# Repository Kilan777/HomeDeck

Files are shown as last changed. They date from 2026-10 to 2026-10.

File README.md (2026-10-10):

# Jarvis HomeDeck

> **Public mirror.** This is a snapshot of the private working repo (commit `6268e34`). Some private parts of the software are not included.

A self-built voice assistant with a screen: a Raspberry Pi Compute Module 4 carrier PCB that bolts to the 7-inch
Raspberry Pi Touch Display 2, plus the software that turns it into "Jarvis". Personal project by Kilan.

The board carries the CM4, USB-C PD power, three 5 V bucks, a stereo class-D amplifier, two MEMS microphones,
a Camera Module 3 connector, CO2 / temperature / humidity / pressure / VOC sensors, an RGB LED bar and an external
WS2812B strip header, a fan header, buttons, a Qwiic-style I2C header, microSD, USB-A and a second USB-C.

The software is a single Python service with a module per feature and a touch UI in Chromium, plus a phone app
served on a personal domain behind Google sign-in. Voice runs on a local wake word and hosted speech models;
everything that is a command (timers, lights, music, volume, math) is handled on the device without a model.

| Folder | Contents |
|---|---|
| `kicad/` | KiCad project: hierarchical schematic (9 sheets), 4-layer routed PCB, project symbols and footprints, DRC rules |
| `tools/circuit.py` | The single source the schematic, netlist and BOM are generated from. Edit this, not the KiCad files |
| `out/` | Gerbers, JLCPCB BOM and pick-and-place, schematic PDF, board renders, DRC report (rev A as ordered) |
| `docs/` | Hardware docs: `README.md` (board overview), `ARCHITECTURE.md`, `BRINGUP.md`, `ORIENTATION.md`, and `PCB_ISSUES.md` (what went wrong on rev A and what rev B should change) |
| `software/homedeck/` | The assistant: `server.py`, `modules/`, `web/`, `install/`. See `docs/SOFTWARE.md` |
| `software/homedeck_ui.py` | The original bench dashboard used for bring-up (retired) |

## Status

- Rev A board #1 is fully working and in daily use, running at 9 V PD after two solder-jumper changes.
  Rev A board #2 is assembled and untested. Findings and the rev B list are in `docs/PCB_ISSUES.md`.
- Software is feature complete for daily use: home screen, Jarvis voice, Spotify (full client), YouTube (ad-free
  native player), air quality with history, timers, alarms, reminders, lists, calendar, countdowns, bikes, transit,
  flights radar, lights, fan, sleep sounds, guest card with Wi-Fi QR,
  presence, Wi-Fi setup, on-screen keyboard. See `docs/SOFTWARE.md`.

## Quick start

Hardware: order from `out/` (JLCPCB 4-layer, two-sided assembly), read `docs/BRINGUP.md`, then apply the rev A
fixes in `docs/PCB_ISSUES.md` before first power-on (the 9 V jumper setting matters).

Software, on the Pi:

```
rsync -a software/homedeck/ kilan@homedeck.local:~/hd/
ssh kilan@homedeck.local 'cd ~/hd && bash install.sh'
```

Then open Settings on the device for location, Wi-Fi, Spotify, calendar feeds and the API keys the optional
features need (Groq for voice, 511.org for Muni). Secrets live only on the device in `/var/lib/homedeck/config.json`
and are never in this repository.

## Privacy

This repository is private. It contains no credentials, tokens or Wi-Fi passwords. The device redacts secrets
from every API response, the phone app requires Google sign-in, and there is no VPN or third-party relay involved.

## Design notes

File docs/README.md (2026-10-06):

# HomeDeck CM4 – smart display / voice assistant carrier board

A Raspberry Pi Compute Module 4 carrier that bolts onto the back of the Raspberry Pi Touch Display 2 (7") and turns it into a self-built "Echo Show" style device: touchscreen, camera, two MEMS microphones, stereo class-D speaker amplifier, CO2 / temperature / humidity / pressure / VOC sensors, ambient light sensor header, RGB light bar, three programmable buttons, microSD, USB-C PD power, a second USB-C (data + 5 V) and a USB-A port.

Everything in this package was generated from a single circuit description (`tools/circuit.py`), so the schematic, the PCB netlist and the BOM cannot disagree with each other.

## What is in the box

| File | What it is |
|---|---|
| `kicad/HomeDeck.kicad_pro` + `*.kicad_sch` | KiCad 7 project, hierarchical schematic (9 sheets). Opens in KiCad 7, 8 or 9. |
| `kicad/HomeDeck.kicad_pcb` | 4-layer board, placed and routed, ground/power planes filled. |
| `kicad/HomeDeck.kicad_sym`, `kicad/HomeDeck.pretty/` | Project symbols and footprints (CM4, CH224K, TPA3118D2, TS3USB221, SY6280, BME688, FPC, USB-A, microSD). |
| `kicad/HomeDeck.kicad_dru` | Custom DRC rules (0.1 mm rules inside the CM4 fan-out areas). |
| `out/HomeDeck_gerbers.zip` | Gerbers + Excellon drill files for JLCPCB. |
| `out/HomeDeck_BOM_JLCPCB.csv` | BOM in JLCPCB format with LCSC part numbers, library type and stock as checked on 2026-09-06. |
| `out/HomeDeck_CPL_JLCPCB.csv` | Pick-and-place file in JLCPCB format (pad-centre positions, JLC rotation corrections applied). |
| `out/HomeDeck_BOM_other.csv` | Parts you buy elsewhere (the CM4 itself) and DNP parts. |
| `out/HomeDeck_schematic.pdf` | Printable schematic. |
| `out/board_top.png`, `out/board_bottom.png` | Renders. |
| `out/drc.txt` | KiCad DRC report of the delivered board. |
| `docs/ARCHITECTURE.md` | Design rationale, power budget, pin map. |
| `docs/BRINGUP.md` | Ordering, assembly, first power-on and software setup. |

## Key numbers

* Board: 130 x 105 mm, 1.6 mm, 4 layers (signal / GND / power planes / signal), ENIG recommended because of the 0.4 mm-pitch CM4 connector pads.
* Mounting: four M2.5 holes on the 58 x 49 mm Raspberry Pi pattern (Touch Display 2 standoffs), centred on the board.
* Power in: USB-C PD, 15 V requested (solder jumpers for 9/12/20 V). Needs a 45 W or better PD charger.
* Rails: 3x TPS5430 bucks (5V_SYS for the CM4, 5V_PERIPH for display/LEDs/fan, 5V_USB for the ports), AMS1117 3.3 V, amplifier directly from the 15 V rail.
* Design rules: 0.2 mm tracks / 0.15 mm clearance generally, 0.1 mm / 0.1 mm only inside the two CM4 fan-out rule areas, vias 0.6/0.3 mm (0.45/0.2 mm in the fan-out). All within JLCPCB's 4-layer capabilities.

## Status of the delivered board

* Placed, fully routed (160 nets), planes filled. KiCad DRC: **0 errors, 0 unconnected items, 0 dangling tracks or vias**; 272 warnings, all cosmetic (silkscreen clipped by the edge on overhanging connectors, designators over copper, and "footprint not in library" because the report was generated headless). Details in `docs/BRINGUP.md` section 5.
* Schematic-to-board netlist verified identical (both come from `tools/circuit.py`); a separate GND connectivity check finds no floating ground copper.
* Design-reviewed twice by independent passes over the datasheets; all findings are fixed in this revision (CH224K VDD feed, TVS orientation, buffered PWR LED, pull-ups referenced to the CM4 3.3 V, USB-C port current limit, I2C0 pull-ups, hub crystal caps removed, LDO output electrolytic, SD_PWR_ON pull-up rail). Manufacturing checks: minimum hole-to-hole gap 0.35 mm, vias 0.6/0.3 and 0.45/0.2, no top-side parts under the CM4, no bottom-side parts near the display standoffs.
* 218 assembled parts (plus the two CM4 sockets as M1A/M1B), 66 BOM lines (38 Basic, 28 Extended), all checked for JLC stock and library type on 2026-09-06 (three out-of-stock parts were swapped: fuse, FPC connectors, CM4 sockets). 116 parts on the bottom side, so order two-sided Standard assembly.
* Routing is 0/45/90-degree geometry with chamfered corners; differential pairs length-matched to within 1.3 mm (most under 0.3 mm), except USB-C #2 data (7.7 mm, still within what USB 2.0 tolerates; see ARCHITECTURE.md section 5).
* Buy separately: CM4 module, Touch Display 2, camera, speakers, PD charger, optional fan and BH1750 breakout (see `out/HomeDeck_BOM_other.csv`).

## How the schematic is drawn

The schematic is "label style": every pin carries a global label with its net name and the sub-sheets group the circuit by function (power, cm4, usb, video, sd, audio, sensors, ui, mech). Every net name is unique across the project, so you can click any label in KiCad and see every place the net goes. It is not a pretty hand-drawn schematic, but it is complete and it is exactly what the PCB was built from.

## Regenerating

```
python3 tools/gen_lib.py        # symbols + footprints
python3 tools/gen_sch.py        # schematic
python3 tools/route.py          # placement + routing + zone fill + DRC (takes 20-40 min)
python3 tools/export.py         # gerbers, BOM, CPL, PDF
```
`tools/router.cpp` is the negotiated-congestion grid router (build with `g++ -O2 -std=c++17 -o tools/router tools/router.cpp`, needs nlohmann-json).

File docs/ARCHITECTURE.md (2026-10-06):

# HomeDeck CM4 – Architecture & Design Notes

Smart-display / voice-assistant carrier board for the Raspberry Pi Compute Module 4, built to bolt onto the back of the Raspberry Pi Touch Display 2 (7", 720x1280). Fabricated and assembled by JLCPCB (4-layer, SMT assembly, Basic parts wherever a Basic part exists).

## 1. What the board does

| Block | Choice | Why |
|---|---|---|
| Compute | Raspberry Pi CM4 (any RAM / eMMC / wireless variant) on 2x Hirose DF40C-100DS | Linux, native DSI + CSI, Wi-Fi/BT on module, huge software base (Home Assistant, Wyoming/openWakeWord, Rhasspy). |
| Display | Touch Display 2 via 15-pin 1.0 mm bottom-contact DSI connector (BOOMELE, JLC C66660) (CM4 DSI1, 2 lanes) + 3-pin 5 V header for the display's power lead | Same wiring as a Pi 4, so the stock `vc4-kms-dsi-ili9881-7inch` overlay works. Touch runs over the I2C0 lines inside the DSI cable. |
| Camera | Pi Camera Module (v2/v3/HQ) via 15-pin 1.0 mm bottom-contact CSI connector (same part; CM4 CAM1, 2 lanes) | Stock libcamera support. Camera enable driven by the CM4 `Camera_GPIO` pin, exactly like the CM4IO board. |
| Power in | USB-C #1 with CH224K PD sink (VDD fed from VBUS through 1 k, SMBJ24A TVS, 5 A fuse), configured for 15 V (solder jumpers allow 9/12/20 V) | One cable from any 45 W+ USB-C PD charger. 15 V gives the amplifier headroom and keeps the bucks efficient. |
| Rails | 3x TPS5430 (3 A, Basic part) bucks: `5V_SYS` (CM4 + 3.3 V LDO), `5V_PERIPH` (display + LED bar + fan), `5V_USB` (USB-C #2 + USB-A + internal USB headers). AMS1117-3.3 LDO for `3V3` (22 uF ceramic + 100 uF electrolytic on its output, the LDO needs some ESR). | Three Basic-part bucks are cheaper at JLC than one big Extended buck, and they isolate the CM4 from USB-port load steps. Output caps are 100 uF electrolytic + 22 uF ceramic because the TPS5430 wants some ESR. |
| USB | CM4 USB 2.0 -> TS3USB221 mux -> CH334R 4-port hub. Ports: USB-C #2 (5 V/1.7 A + data, CC pull-ups advertise 1.5 A), USB-A (5 V/1.3 A + data), 2x internal 4-pin headers (for a Zigbee/Thread dongle etc). | CM4 has a single USB 2.0 port so a hub is mandatory. Each external port has a SY6280 current-limit switch and USBLC6 ESD protection. |
| eMMC flashing | `nRPIBOOT` jumper flips both TS3USB221 muxes so the CM4 USB goes straight to USB-C #2 and cuts that port's 5 V output. U6's two switch ports are wired the opposite way round to U7 (so the BOOT pair leaves U6 on the pins facing U7 without crossing the hub pair), and its select pin is therefore driven by an inverted copy of `nRPIBOOT` (Q5 2N7002 + R47 10 k). | Lets you run `rpiboot` from a PC with a USB-A-to-C cable without a separate service port. |
| Storage | microSD (Molex 104031-0811) on the CM4 SD lines with SD_PWR_ON load switch | Boot medium for CM4 *Lite*. On eMMC CM4 variants the SD pins are inactive (Pi limitation). |
| Audio out | PCM5102A I2S DAC -> TPA3118D2 stereo class-D (2x >5 W into 8 ohm from the 15 V rail), LC output filters (10 uH + 1 uF), 2x JST-PH speaker connectors | `dtoverlay=hifiberry-dac` style zero-config DAC. Amp enable/mute/fault on GPIO. |
| Audio in | 2x ICS-43434 I2S MEMS mics (L/R on one I2S data line) at the top corners, bottom-ported through the PCB | Same clocks as the DAC (full-duplex I2S), same arrangement as the Google AIY Voice HAT overlay. |
| Sensors (I2C6, GPIO22/23) | SCD40 (CO2) and BME688 (temp/humidity/pressure/VOC) on a thermally slotted tongue at the left edge; BH1750 ambient light sensor on a 4-pin header (J12) so it can sit behind the bezel and actually see the room. | Keeps the temperature sensor away from the CM4 heat and the light sensor where there is light. |
| Light bar | 10x WS2812B (5050) along the top edge + JST-PH-3 header for an external strip, 74AHCT1G125 level shifter, data on GPIO10 (SPI MOSI, works with `rpi_ws281x` SPI mode) | Classic "listening" glow. |
| Buttons / LEDs | Power button (GPIO3: wake from halt + `gpio-shutdown`), two user buttons (GPIO16, GPIO26), user LED (GPIO12, PWM-capable), PWR / ACT LEDs from the CM4 LED pins, PD-good LED. Each button has an on-board tactile switch *and* a 2-pin header for a panel-mounted button. | All programmable; nothing is hard-wired to the mics or camera. |
| Misc | 5 V fan header (GPIO25 PWM via transistor), UART debug header (GPIO14/15), 2x8 expansion header with the spare GPIOs, `GLOBAL_EN` and `RUN` headers, reset button | Bring-up and future expansion. |

## 2. Power budget (15 V PD input)

| Load | Rail | Typ | Peak |
|---|---|---|---|
| CM4 | 5V_SYS | 1.4 A | 3.0 A |
| 3V3 LDO loads (hub, DAC, mux, sensors, mics) | 5V_SYS | 0.25 A | 0.45 A |
| Touch Display 2 | 5V_PERIPH | 0.6 A | 1.0 A |
| LED bar (10x WS2812B) | 5V_PERIPH | 0.1 A | 0.6 A |
| Fan | 5V_PERIPH | 0.1 A | 0.2 A |
| USB-C #2 + USB-A + internal headers | 5V_USB | 0.5 A | 3.0 A (1.74 A + 1.33 A limits of the SY6280s) |
| Amplifier (2x5 W into 8 ohm, music) | VBUS 15 V | 0.3 A | 1.0 A |

Worst case at 15 V: (3.45 + 1.8 + 2.9) x 5 V / 0.88 + 15 W = ~61 W momentarily; realistic sustained draw is 20–30 W. A 45 W (15 V / 3 A) PD supply is the minimum; 65 W is comfortable. If the charger only offers 9 V or 12 V the CH224K falls back to it and everything still works (the amp just has less headroom). At 5 V only (dumb charger) the bucks cannot regulate and the board is not guaranteed to boot — the PD-good LED tells you.

Buck design (TPS5430, 500 kHz, non-synchronous): 10 uH / 7.8 A shielded inductor, SS34 catch diode, 2x 10 uF/50 V ceramic input, 100 uF electrolytic + 22 uF ceramic output, 10 nF bootstrap, feedback 15 k / 4.7 k -> 5.12 V (CM4 window is 4.75–5.25 V, USB ports need >4.75 V after the switch drop).

## 3. CM4 pin usage

* USB: `USB_P/N` (105/103) -> mux. `USB_OTG_ID` DNP link to GND (host mode is set by `otg_mode=1` in `config.txt`).
* DSI1 lanes 0-1 + clock -> display connector; CAM1 lanes 0-1 + clock -> camera connector; `SCL0/SDA0` (80/82) to both connectors (the CM4 has 1.8 k internal pull-ups, none added); `Camera_GPIO` (97) -> camera pin 11.
* SD: `SD_CLK/CMD/DAT0-3` (57/62/63/67/69/61) -> microSD; `SD_PWR_ON` (75) -> P-FET load switch, 10 k pull-up to `CM4_3.3V` so the card is powered at boot; `SD_VDD_OVERRIDE` NC.
* Power/control: 6x `+5V` pins from 5V_SYS, `GPIO_VREF` (78) -> `CM4_3.3V`, `GLOBAL_EN` (99) header, `RUN_PG` (92) reset switch via 220 R, `nRPIBOOT` (93) jumper, `PI_LED_nPWR` (95, buffered with a P-FET as the datasheet requires) / `Pi_nLED_Activity` (21) LEDs, `EEPROM_nWP`, `WL_nDisable`, `BT_nDisable`, `AnalogIP*`, `VDAC_COMP`, HDMI, PCIe, Ethernet all NC.
* GPIO map:

| GPIO | Function | GPIO | Function |
|---|---|---|---|
| 2 | expansion (SDA1) | 16 | BTN_A |
| 3 | PWR_BTN (SCL1, wake) | 17 | expansion |
| 4 | AMP_SDZ (amp enable, pulled low) | 18 | I2S_BCLK |
| 5 | AMP_MUTE (high = mute, pulled low) | 19 | I2S_LRCLK |
| 6 | AMP_FAULT (input, pulled up) | 20 | I2S_DIN (mics) |
| 7 | expansion (CE1) | 21 | I2S_DOUT (DAC) |
| 8 | expansion (CE0) | 22 | I2C6_SDA sensors |
| 9 | expansion (MISO) | 23 | I2C6_SCL sensors |
| 10 | LED_DATA (MOSI) | 24 | DAC_XSMT (pulled up) |
| 11 | expansion (SCLK) | 25 | FAN_PWM |
| 12 | USER_LED | 26 | BTN_B |
| 13 | expansion (PWM1) | 27 | PD_GOOD (input, pulled up) |
| 14/15 | UART TX/RX debug | 0/1 | ID_SD/ID_SC on expansion |

All pull-ups on CM4 GPIOs go to `CM4_3.3V` (not the always-on 3V3) so no pin sees voltage while the module is off, as the CM4 datasheet requires.

Software notes: `dtoverlay=i2c6,pins_22_23`, `dtoverlay=gpio-shutdown,gpio_pin=3`, `dtoverlay=hifiberry-dac` (or a custom simple-audio-card overlay that adds the ICS-43434 capture side), `dtoverlay=vc4-kms-dsi-ili9881-7inch`, `otg_mode=1`, `dtparam=i2c_vc=on`.

## 4. Mechanical

* Board 130 x 105 mm, 1.6 mm, 4 layers (Sig – GND – PWR – Sig), ENIG recommended for the 0.4 mm DF40 pads. JLCPCB 4-layer rules: 0.2/0.15 mm tracks/clearance generally, 0.1/0.1 mm and 0.45/0.2 mm vias inside the two CM4 fan-out rule areas.
* Four M2.5 holes on the 58 x 49 mm Raspberry Pi pattern (centred on the board), matching the Touch Display 2 standoffs. The display sits against the *bottom* side, so bottom-side parts are limited to 0603-1206 passives, one SOT-23 and the two mics (~1 mm tall); 114 parts live there, so order two-sided assembly.
* CM4 on top, centred over the standoff pattern; use the official CM4 heatsink (the design leaves the CM4 mounting holes free).
* All external connectors on the bottom edge (y = 105): microSD, USB-A, USB-C data, fan, speakers, display power, USB-C power. Display and camera FPC connectors sit above the CM4 with the cables exiting toward the top edge.
* Sensor tongue on the left edge with two 1.6 mm routed slots for thermal isolation; enclosure needs vent slots there and a light pipe for the BH1750.
* Mics at the top corners: 1.0 mm acoustic holes through the PCB (they are bottom-ported and mounted on the bottom side so they listen "up" through the board); enclosure needs matching holes with a gasket.
* LED bar along the top edge shining upward — enclosure needs a diffuser slot, or use the 3-pin header for a strip elsewhere.

## 5. Fan-out and routing notes

Every used CM4 pad gets a 0.1 mm stub to a 0.45/0.2 mm via, in three staggered rows (1.2 / 1.9 / 2.6 mm from the pad row). Inner rows fan out under the module, outer rows fan out away from it; the region below the lower connector (x 52-78, y 73-86) is kept free of components for this, and the lower fan-out rule area extends to y = 79.5 so the SD-card bus can leave the connector at 0.1 mm spacing. The routing was done by a negotiated-congestion grid router written for this project, then post-processed into conventional 0/45/90-degree geometry (staircases replaced by straight and 45-degree runs wherever clear, right-angle corners chamfered), and every differential pair was length-matched with small meander bumps on the shorter leg; the top/bottom GND pours use 0.25 mm minimum width and 0.25 mm clearance so they do not fragment into slivers, every pour island that ended up without a path to the internal GND plane got a stitching via, and a coarse grid of stitching vias ties the pours to the plane in the open areas (a connectivity check on the final board finds zero floating GND copper). In2 carries split power planes: 5V_SYS under the CM4, VBUS (15 V) along the right and bottom-right, 5V_USB bottom-left, 5V_PERIPH along the top, 3V3 under the sensor tongue.

### Differential-pair status (final board)

| Pair | Length P / N (mm) | Skew |
|---|---|---|
| DSI D0 / D1 / CLK | 19.0/18.8, 21.3/21.5, 20.4/20.6 | 0.1 / 0.2 / 0.2 mm |
| CSI D0 / D1 / CLK | 14.3/14.1, 17.1/16.6, 21.0/19.8 | 0.2 / 0.5 / 1.2 mm |
| CM4 USB -> U6 | 43.8/43.9 | 0.1 mm |
| U6 -> U7 (BOOT) | 6.8/7.2 | 0.3 mm |
| U6 -> hub upstream | 4.7/6.0 | 1.3 mm |
| hub -> U7 (DS1) | 3.4/4.2 | 0.8 mm |
| hub -> USB-A (signal path through the ESD diode) | 11.4/12.6 | 1.1 mm |
| hub -> internal headers DS3 / DS4 | 46.7/46.5, 34.2/34.0 | 0.2 / 0.2 mm |
| U7 -> USB-C #2 (signal path) | 22.9/15.2 | **7.7 mm** |

Everything except USB-C #2 is within 1.3 mm (under 10 ps), which is well inside what MIPI D-PHY and USB 2.0 receivers tolerate. The USB-C #2 data pair is the one that could not be matched automatically: the receptacle's A6/B6 and A7/B7 pads interleave, so one leg has to loop behind the connector, and the 0.5 mm-pitch mux pins leave no room for meanders. 7.7 mm is about 50 ps, 2.5 % of a USB high-speed bit, so it will work, but if you want it textbook-clean, re-route that pair with KiCad's interactive differential-pair router (Route -> Differential Pair, then Tune Skew) between U7 and J2. Nothing else on the board is impedance- or length-critical.

## 6. Options not populated (but discussed)

mmWave presence radar (LD2410 on the UART header), hardware mic/camera kill switch (can be added in series with the mic 3V3 and `Camera_GPIO`), Zigbee/Thread (a USB dongle on the internal USB header is the pragmatic route), IR blaster/receiver, PoE, RTC with coin cell, PIR.

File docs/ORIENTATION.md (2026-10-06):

# Component orientation list (for the JLCPCB placement preview)

Directions are as seen looking at that side of the board with the top edge of the board up (for bottom-side parts you are looking at the board from below). 'Only 90 deg' means 0 and 180 are both fine but a 90-degree error is a fault.

| Ref | Value | Footprint | Side | Orientation matters? | How it must sit |
|---|---|---|---|---|---|
| C1 | 10uF/50V | C_1206_3216Metric | bottom | No | Symmetric two-terminal part. |
| C2 | 10uF/50V | C_1206_3216Metric | bottom | No | Symmetric two-terminal part. |
| C3 | 100uF/35V | CP_Elec_6.3x7.7 | top | Yes | Positive (+) lead on the left (the can's black stripe is the negative side, opposite). |
| C4 | 1uF | C_0603_1608Metric | top | No | Symmetric two-terminal part. |
| C5 | 10uF/50V | C_1206_3216Metric | bottom | No | Symmetric two-terminal part. |
| C6 | 100nF | C_0603_1608Metric | top | No | Symmetric two-terminal part. |
| C7 | 10nF | C_0603_1608Metric | bottom | No | Symmetric two-terminal part. |
| C8 | 100uF/35V | CP_Elec_6.3x7.7 | top | Yes | Positive (+) lead on the bottom (the can's black stripe is the negative side, opposite). |
| C9 | 22uF/25V | C_1206_3216Metric | bottom | No | Symmetric two-terminal part. |
| C10 | 100nF | C_0603_1608Metric | bottom | No | Symmetric two-terminal part. |
| C11 | 10uF/50V | C_1206_3216Metric | bottom | No | Symmetric two-terminal part. |
| C12 | 100nF | C_0603_1608Metric | top | No | Symmetric two-terminal part. |
| C13 | 10nF | C_0603_1608Metric | bottom | No | Symmetric two-terminal part. |
| C14 | 100uF/35V | CP_Elec_6.3x7.7 | top | Yes | Positive (+) lead on the bottom (the can's black stripe is the negative side, opposite). |
| C15 | 22uF/25V | C_1206_3216Metric | bottom | No | Symmetric two-terminal part. |
| C16 | 100nF | C_0603_1608Metric | bottom | No | Symmetric two-terminal part. |
| C17 | 10uF/50V | C_1206_3216Metric | bottom | No | Symmetric two-terminal part. |
| C18 | 100nF | C_0603_1608Metric | top | No | Symmetric two-terminal part. |
| C19 | 10nF | C_0603_1608Metric | bottom | No | Symmetric two-terminal part. |
| C20 | 100uF/35V | CP_Elec_6.3x7.7 | top | Yes | Positive (+) lead on the bottom (the can's black stripe is the negative side, opposite). |
| C21 | 22uF/25V | C_1206_3216Metric | bottom | No | Symmetric two-terminal part. |
| C22 | 100nF | C_0603_1608Metric | bottom | No | Symmetric two-terminal part. |
| C23 | 22uF/25V | C_1206_3216Metric | bottom | No | Symmetric two-terminal part. |
| C24 | 22uF/25V | C_1206_3216Metric | bottom | No | Symmetric two-terminal part. |
| C25 | 100nF | C_0603_1608Metric | top | No | Symmetric two-terminal part. |
| C26 | 100nF | C_0603_1608Metric | bottom | No | Symmetric two-terminal part. |
| C27 | 10uF | C_0603_1608Metric | bottom | No | Symmetric two-terminal part. |
| C28 | 10uF | C_0603_1608Metric | bottom | No | Symmetric two-terminal part. |
| C29 | 100nF | C_0603_1608Metric | bottom | No | Symmetric two-terminal part. |
| C30 | 100nF | C_0603_1608Metric | bottom | No | Symmetric two-terminal part. |
| C31 | 100nF | C_0603_1608Metric | bottom | No | Symmetric two-terminal part. |
| C32 | 1uF | C_0603_1608Metric | bottom | No | Symmetric two-terminal part. |
| C33 | 10uF | C_0603_1608Metric | bottom | No | Symmetric two-terminal part. |
| C34 | 100nF | C_0603_1608Metric | bottom | No | Symmetric two-terminal part. |
| C35 | 100nF | C_0603_1608Metric | bottom | No | Symmetric two-terminal part. |
| C36 | 22pF | C_0603_1608Metric | bottom | No | Symmetric two-terminal part. |
| C37 | 22pF | C_0603_1608Metric | bottom | No | Symmetric two-terminal part. |
| C38 | 10uF | C_0603_1608Metric | top | No | Symmetric two-terminal part. |
| C39 | 10uF | C_0603_1608Metric | top | No | Symmetric two-terminal part. |
| C40 | 10uF | C_0603_1608Metric | bottom | No | Symmetric two-terminal part. |
| C41 | 10uF | C_0603_1608Metric | bottom | No | Symmetric two-terminal part. |
| C42 | 10uF | C_0603_1608Metric | bottom | No | Symmetric two-terminal part. |
| C43 | 100nF | C_0603_1608Metric | bottom | No | Symmetric two-terminal part. |
| C44 | 10uF | C_0603_1608Metric | bottom | No | Symmetric two-terminal part. |
| C45 | 100nF | C_0603_1608Metric | bottom | No | Symmetric two-terminal part. |
| C46 | 10uF | C_0603_1608Metric | bottom | No | Symmetric two-terminal part. |
| C47 | 100nF | C_0603_1608Metric | bottom | No | Symmetric two-terminal part. |
| C48 | 100nF | C_0603_1608Metric | bottom | No | Symmetric two-terminal part. |
| C49 | 10uF | C_0603_1608Metric | bottom | No | Symmetric two-terminal part. |
| C50 | 2.2uF | C_0603_1608Metric | bottom | No | Symmetric two-terminal part. |
| C51 | 2.2uF | C_0603_1608Metric | bottom | No | Symmetric two-terminal part. |
| C52 | 2.2uF | C_0603_1608Metric | bottom | No | Symmetric two-terminal part. |
| C53 | 2.2nF | C_0603_1608Metric | bottom | No | Symmetric two-terminal part. |
| C54 | 1uF | C_0603_1608Metric | top | No | Symmetric two-terminal part. |
| C55 | 1uF | C_0603_1608Metric | bottom | No | Symmetric two-terminal part. |
| C56 | 2.2nF | C_0603_1608Metric | bottom | No | Symmetric two-terminal part. |
| C57 | 1uF | C_0603_1608Metric | bottom | No | Symmetric two-terminal part. |
| C58 | 1uF | C_0603_1608Metric | bottom | No | Symmetric two-terminal part. |
| C59 | 1uF | C_0603_1608Metric | bottom | No | Symmetric two-terminal part. |
| C60 | 1uF | C_0603_1608Metric | bottom | No | Symmetric two-terminal part. |
| C61 | 100nF | C_0603_1608Metric | bottom | No | Symmetric two-terminal part. |
| C62 | 220nF | C_0603_1608Metric | top | No | Symmetric two-terminal part. |
| C63 | 220nF | C_0603_1608Metric | top | No | Symmetric two-terminal part. |
| C64 | 220nF | C_0603_1608Metric | top | No | Symmetric two-terminal part. |
| C65 | 220nF | C_0603_1608Metric | top | No | Symmetric two-terminal part. |
| C66 | 1nF | C_0603_1608Metric | bottom | No | Symmetric two-terminal part. |
| C67 | 10uF/50V | C_1206_3216Metric | bottom | No | Symmetric two-terminal part. |
| C68 | 1nF | C_0603_1608Metric | bottom | No | Symmetric two-terminal part. |
| C69 | 10uF/50V | C_1206_3216Metric | bottom | No | Symmetric two-terminal part. |
| C70 | 100uF/35V | CP_Elec_6.3x7.7 | top | Yes | Positive (+) lead on the left (the can's black stripe is the negative side, opposite). |
| C71 | 1uF/50V | C_0805_2012Metric | top | No | Symmetric two-terminal part. |
| C72 | 1uF/50V | C_0805_2012Metric | bottom | No | Symmetric two-terminal part. |
| C73 | 1uF/50V | C_0805_2012Metric | bottom | No | Symmetric two-terminal part. |
| C74 | 1uF/50V | C_0805_2012Metric | top | No | Symmetric two-terminal part. |
| C75 | 100nF | C_0603_1608Metric | top | No | Symmetric two-terminal part. |
| C76 | 100nF | C_0603_1608Metric | top | No | Symmetric two-terminal part. |
| C77 | 10uF | C_0603_1608Metric | bottom | No | Symmetric two-terminal part. |
| C78 | 100nF | C_0603_1608Metric | bottom | No | Symmetric two-terminal part. |
| C79 | 100nF | C_0603_1608Metric | bottom | No | Symmetric two-terminal part. |
| C80 | 100nF | C_0603_1608Metric | bottom | No | Symmetric two-terminal part. |
| C81 | 100nF | C_0603_1608Metric | bottom | No | Symmetric two-terminal part. |
| C82 | 100nF | C_0603_1608Metric | bottom | No | Symmetric two-terminal part. |
| C83 | 100nF | C_0603_1608Metric | bottom | No | Symmetric two-terminal part. |
| C84 | 100nF | C_0603_1608Metric | bottom | No | Symmetric two-terminal part. |
| C85 | 100nF | C_0603_1608Metric | bottom | No | Symmetric two-terminal part. |
| C86 | 100nF | C_0603_1608Metric | bottom | No | Symmetric two-terminal part. |
| C87 | 100nF | C_0603_1608Metric | bottom | No | Symmetric two-terminal part. |
| C88 | 100nF | C_0603_1608Metric | bottom | No | Symmetric two-terminal part. |
| C89 | 100nF | C_0603_1608Metric | bottom | No | Symmetric two-terminal part. |
| C90 | 100nF | C_0603_1608Metric | bottom | No | Symmetric two-terminal part. |
| C91 | 100nF | C_0603_1608Metric | bottom | No | Symmetric two-terminal part. |
| C92 | 10uF | C_0603_1608Metric | bottom | No | Symmetric two-terminal part. |
| C93 | 100nF | C_0603_1608Metric | bottom | No | Symmetric two-terminal part. |
| C94 | 100nF | C_0603_1608Metric | bottom | No | Symmetric two-terminal part. |
| C95 | 100nF | C_0603_1608Metric | bottom | No | Symmetric two-terminal part. |
| D1 | SMBJ24A | D_SMB | top | Yes | Cathode band on the bottom. |
| D2 | PD OK (green) | LED_0805_2012Metric | top | Yes | Cathode (green mark / notch) on the bottom. |
| D3 | ACT (green) | LED_0805_2012Metric | top | Yes | Cathode (green mark / notch) on the bottom. |
| D4 | PWR (red) | LED_0603_1608Metric | top | Yes | Cathode (green mark / notch) on the bottom. |
| D5 | USER (green) | LED_0805_2012Metric | top | Yes | Cathode (green mark / notch) on the bottom. |
| D6 | SS34 | D_SMA | top | Yes | Cathode band on the left. |
| D7 | SS34 | D_SMA | top | Yes | Cathode band on the left. |
| D8 | SS34 | D_SMA | top | Yes | Cathode band on the left. |
| D9 | SS34 | D_SMA | top | Yes | Cathode band on the left. |
| D10 | WS2812B | LED_WS2812B_PLCC4_5.0x5.0mm_P3.2mm | top | Yes | Pin 1 (VDD, the cut corner of the LED) at the top-left. |
| D11 | WS2812B | LED_WS2812B_PLCC4_5.0x5.0mm_P3.2mm | top | Yes | Pin 1 (VDD, the cut corner of the LED) at the top-left. |
| D12 | WS2812B | LED_WS2812B_PLCC4_5.0x5.0mm_P3.2mm | top | Yes | Pin 1 (VDD, the cut corner of the LED) at the top-left. |
| D13 | WS2812B | LED_WS2812B_PLCC4_5.0x5.0mm_P3.2mm | top | Yes | Pin 1 (VDD, the cut corner of the LED) at the top-left. |
| D14 | WS2812B | LED_WS2812B_PLCC4_5.0x5.0mm_P3.2mm | top | Yes | Pin 1 (VDD, the cut corner of the LED) at the top-left. |
| D15 | WS2812B | LED_WS2812B_PLCC4_5.0x5.0mm_P3.2mm | top | Yes | Pin 1 (VDD, the cut corner of the LED) at the top-left. |
| D16 | WS2812B | LED_WS2812B_PLCC4_5.0x5.0mm_P3.2mm | top | Yes | Pin 1 (VDD, the cut corner of the LED) at the top-left. |
| D17 | WS2812B | LED_WS2812B_PLCC4_5.0x5.0mm_P3.2mm | top | Yes | Pin 1 (VDD, the cut corner of the LED) at the top-left. |
| D18 | WS2812B | LED_WS2812B_PLCC4_5.0x5.0mm_P3.2mm | top | Yes | Pin 1 (VDD, the cut corner of the LED) at the top-left. |
| D19 | WS2812B | LED_WS2812B_PLCC4_5.0x5.0mm_P3.2mm | top | Yes | Pin 1 (VDD, the cut corner of the LED) at the top-left. |
| F1 | 5A | Fuse_1206_3216Metric | top | No | Symmetric. |
| J1 | USB-C PD IN | USB_C_Receptacle_HRO_TYPE-C-31-M-1 | top | Yes | Opening faces the bottom board edge. Only fits one way on the pads (through-hole shell pins). |
| J2 | USB-C DATA/5V | USB_C_Receptacle_HRO_TYPE-C-31-M-1 | top | Yes | Opening faces the bottom board edge. Only fits one way on the pads (through-hole shell pins). |
| J3 | USB-A | USB_A_Molex_67643_Horizontal | top | Yes | Opening faces the bottom board edge; through-hole pins only fit one way. |
| J4 | USB int | PinHeader_1x04_P2.54mm_Vertical | top | No | Plain header, any orientation. |
| J5 | USB int | PinHeader_1x04_P2.54mm_Vertical | top | No | Plain header, any orientation. |
| J6 | DISPLAY (DSI1) | FPC_15P_1.0mm_BottomContact_RA | top | Yes | Cable side (the flip/slide latch) faces the top board edge; pin 1 on the bottom-right. |
| J7 | CAMERA (CAM1) | FPC_15P_1.0mm_BottomContact_RA | top | Yes | Cable side (the flip/slide latch) faces the top board edge; pin 1 on the bottom-right. |
| J8 | DISPLAY 5V | PinHeader_1x03_P2.54mm_Vertical | top | No | Plain header, any orientation. |
| J9 | microSD | microSD_HC_Molex_104031-0811 | top | Yes | Card slot opening faces the bottom board edge; the 8 contact pins must sit on the 8 small pads at the inner (top) end of the footprint. |
| J10 | SPK L | JST_PH_S2B-PH-K_1x02_P2.00mm_Horiz | top | Yes | Opening must face the board edge (down). Pin 1 (SPK_LP) on the centre. |
| J11 | SPK R | JST_PH_S2B-PH-K_1x02_P2.00mm_Horiz | top | Yes | Opening must face the board edge (down). Pin 1 (SPK_RP) on the centre. |
| J12 | I2C ext (light sensor) | PinHeader_1x04_P2.54mm_Vertical | top | No | Plain header, any orientation. |
| J13 | GLOBAL_EN | PinHeader_1x02_P2.54mm_Vertical | top | No | Plain header, any orientation. |
| J14 | nRPIBOOT | PinHeader_1x02_P2.54mm_Vertical | top | No | Plain header, any orientation. |
| J15 | UART debug | PinHeader_1x03_P2.54mm_Vertical | top | No | Plain header, any orientation. |
| J16 | Expansion | PinHeader_2x08_P2.54mm_Vertical | top | No | Plain header; 180 just swaps pin numbering, which the pinout table already accounts for as physical positions. |
| J17 | LED strip ext | JST_PH_S3B-PH-K_1x03_P2.00mm_Horiz | top | Yes | Opening must face the board edge (down). Pin 1 (5V_PERIPH) on the centre. |
| J18 | ext button | PinHeader_1x02_P2.54mm_Vertical | top | No | Plain header, any orientation. |
| J19 | ext button | PinHeader_1x02_P2.54mm_Vertical | top | No | Plain header, any orientation. |
| J20 | ext button | PinHeader_1x02_P2.54mm_Vertical | top | No | Plain header, any orientation. |
| J21 | FAN 5V | JST_PH_S2B-PH-K_1x02_P2.00mm_Horiz | top | Yes | Opening must face the board edge (down). Pin 1 (5V_PERIPH) on the centre. |
| L1 | 10uH 7.8A | L_Sunlord_MWSA1004S | top | Only 90 deg | Non-polar. The two terminals must sit on the two pads; 0 and 180 are both fine, 90 is wrong. |
| L2 | 10uH 7.8A | L_Sunlord_MWSA1004S | top | Only 90 deg | Non-polar. The two terminals must sit on the two pads; 0 and 180 are both fine, 90 is wrong. |
| L3 | 10uH 7.8A | L_Sunlord_MWSA1004S | top | Only 90 deg | Non-polar. The two terminals must sit on the two pads; 0 and 180 are both fine, 90 is wrong. |
| L4 | 10uH 2.1A | L_Sunlord_SWPA5040S | top | Only 90 deg | Non-polar. The two terminals must sit on the two pads; 0 and 180 are both fine, 90 is wrong. |
| L5 | 10uH 2.1A | L_Sunlord_SWPA5040S | top | Only 90 deg | Non-polar. The two terminals must sit on the two pads; 0 and 180 are both fine, 90 is wrong. |
| L6 | 10uH 2.1A | L_Sunlord_SWPA5040S | top | Only 90 deg | Non-polar. The two terminals must sit on the two pads; 0 and 180 are both fine, 90 is wrong. |
| L7 | 10uH 2.1A | L_Sunlord_SWPA5040S | top | Only 90 deg | Non-polar. The two terminals must sit on the two pads; 0 and 180 are both fine, 90 is wrong. |
| Q1 | AO3401A | SOT-23 | top | Yes | Pin 1 (one of the two same-side pins) at the top-left; the single pin is on the opposite side. |
| Q2 | 2N7002 | SOT-23 | top | Yes | Pin 1 (one of the two same-side pins) at the top-left; the single pin is on the opposite side. |
| Q3 | AO3400A | SOT-23 | top | Yes | Pin 1 (one of the two same-side pins) at the top-left; the single pin is on the opposite side. |
| Q4 | AO3401A | SOT-23 | bottom | Yes | Pin 1 (one of the two same-side pins) at the bottom-right; the single pin is on the opposite side. |
| Q5 | 2N7002 | SOT-23 | bottom | Yes | Pin 1 (one of the two same-side pins) at the top-left; the single pin is on the opposite side. |
| R1 | 5.1k | R_0603_1608Metric | bottom | No | Symmetric two-terminal part. |
| R2 | 1k/0.25W | R_1206_3216Metric | bottom | No | Symmetric two-terminal part. |
| R3 | 10k | R_0603_1608Metric | bottom | No | Symmetric two-terminal part. |
| R4 | 470R | R_0603_1608Metric | bottom | No | Symmetric two-terminal part. |
| R5 | 15k | R_0603_1608Metric | top | No | Symmetric two-terminal part. |
| R6 | 4.7k | R_0603_1608Metric | bottom | No | Symmetric two-terminal part. |
| R7 | 15k | R_0603_1608Metric | bottom | No | Symmetric two-terminal part. |
| R8 | 4.7k | R_0603_1608Metric | top | No | Symmetric two-terminal part. |
| R9 | 15k | R_0603_1608Metric | bottom | No | Symmetric two-terminal part. |
| R10 | 4.7k | R_0603_1608Metric | top | No | Symmetric two-terminal part. |
| R11 | 10k | R_0603_1608Metric | bottom | No | Symmetric two-terminal part. |
| R13 | 330R | R_0603_1608Metric | bottom | No | Symmetric two-terminal part. |
| R14 | 100k | R_0603_1608Metric | bottom | No | Symmetric two-terminal part. |
| R15 | 1k | R_0603_1608Metric | bottom | No | Symmetric two-terminal part. |
| R16 | 220R | R_0603_1608Metric | bottom | No | Symmetric two-terminal part. |
| R17 | 10k | R_0603_1608Metric | bottom | No | Symmetric two-terminal part. |
| R18 | 22k | R_0603_1608Metric | bottom | No | Symmetric two-terminal part. |
| R19 | 22k | R_0603_1608Metric | bottom | No | Symmetric two-terminal part. |
| R20 | 3.9k | R_0603_1608Metric | bottom | No | Symmetric two-terminal part. |
| R21 | 5.1k | R_0603_1608Metric | bottom | No | Symmetric two-terminal part. |
| R22 | 10k | R_0603_1608Metric | bottom | No | Symmetric two-terminal part. |
| R23 | 10k | R_0603_1608Metric | bottom | No | Symmetric two-terminal part. |
| R24 | 10R | R_0603_1608Metric | bottom | No | Symmetric two-terminal part. |
| R25 | 10k | R_0603_1608Metric | bottom | No | Symmetric two-terminal part. |
| R26 | 470R | R_0603_1608Metric | top | No | Symmetric two-terminal part. |
| R27 | 22k | R_0603_1608Metric | bottom | No | Symmetric two-terminal part. |
| R28 | 6.8k | R_0603_1608Metric | bottom | No | Symmetric two-terminal part. |
| R29 | 470R | R_0603_1608Metric | bottom | No | Symmetric two-terminal part. |
| R30 | 22k | R_0603_1608Metric | bottom | No | Symmetric two-terminal part. |
| R31 | 6.8k | R_0603_1608Metric | top | No | Symmetric two-terminal part. |
| R32 | 20k | R_0603_1608Metric | bottom | No | Symmetric two-terminal part. |
| R33 | 100k | R_0603_1608Metric | top | No | Symmetric two-terminal part. |
| R34 | 10R | R_0603_1608Metric | bottom | No | Symmetric two-terminal part. |
| R35 | 10k | R_0603_1608Metric | bottom | No | Symmetric two-terminal part. |
| R36 | 10k | R_0603_1608Metric | bottom | No | Symmetric two-terminal part. |
| R37 | 10k | R_0603_1608Metric | top | No | Symmetric two-terminal part. |
| R38 | 4.7k | R_0603_1608Metric | bottom | No | Symmetric two-terminal part. |
| R39 | 4.7k | R_0603_1608Metric | bottom | No | Symmetric two-terminal part. |
| R40 | 330R | R_0603_1608Metric | bottom | No | Symmetric two-terminal part. |
| R41 | 470R | R_0603_1608Metric | bottom | No | Symmetric two-terminal part. |
| R42 | 10k | R_0603_1608Metric | bottom | No | Symmetric two-terminal part. |
| R43 | 10k | R_0603_1608Metric | bottom | No | Symmetric two-terminal part. |
| R44 | 10k | R_0603_1608Metric | bottom | No | Symmetric two-terminal part. |
| R45 | 100R | R_0603_1608Metric | top | No | Symmetric two-terminal part. |
| R46 | 100k | R_0603_1608Metric | bottom | No | Symmetric two-terminal part. |
| R47 | 10k | R_0603_1608Metric | bottom | No | Symmetric two-terminal part. |
| SW1 | POWER | SW_Push_1P1T_XKB_TS-1187A | top | Only 90 deg | The switch's internally connected pin pairs run along the 6 mm axis (left-right). Terminals must sit on the four pads; 0 and 180 are fine, 90 shorts the button permanently. |
| SW2 | BTN A | SW_Push_1P1T_XKB_TS-1187A | top | Only 90 deg | The switch's internally connected pin pairs run along the 6 mm axis (left-right). Terminals must sit on the four pads; 0 and 180 are fine, 90 shorts the button permanently. |
| SW3 | BTN B | SW_Push_1P1T_XKB_TS-1187A | top | Only 90 deg | The switch's internally connected pin pairs run along the 6 mm axis (left-right). Terminals must sit on the four pads; 0 and 180 are fine, 90 shorts the button permanently. |
| SW4 | RESET | SW_Push_1P1T_XKB_TS-1187A | top | Only 90 deg | The switch's internally connected pin pairs run along the 6 mm axis (left-right). Terminals must sit on the four pads; 0 and 180 are fine, 90 shorts the button permanently. |
| U1 | CH224K | ESSOP-10-1EP_3.9x4.9mm_P1.0mm | top | Yes | Pin 1 dot at the top-left. |
| U2 | TPS5430 | TI_SO-PowerPAD-8_ThermalVias | top | Yes | Pin 1 dot at the top-left. |
| U3 | TPS5430 | TI_SO-PowerPAD-8_ThermalVias | top | Yes | Pin 1 dot at the top-left. |
| U4 | TPS5430 | TI_SO-PowerPAD-8_ThermalVias | top | Yes | Pin 1 dot at the top-left. |
| U5 | AMS1117-3.3 | SOT-223-3_TabPin2 | top | Yes | Pin 1 at the top-left; the wide tab is on the opposite side. |
| U6 | TS3USB221 | Texas_UQFN-10_1.5x2mm_P0.5mm | top | Yes | Pin 1 dot at the top-left. |
| U7 | TS3USB221 | Texas_UQFN-10_1.5x2mm_P0.5mm | top | Yes | Pin 1 dot at the top-left. |
| U8 | CH334R | QSOP-16_3.9x4.9mm_P0.635mm | top | Yes | Pin 1 dot at the bottom-left. |
| U9 | USBLC6-2SC6 | SOT-23-6 | top | Yes | Pin 1 at the top-left (the side with 3 pins is left). |
| U10 | SY6280AAC | SOT-23-5 | top | Yes | Pin 1 at the top-left (the side with 3 pins is left). |
| U11 | USBLC6-2SC6 | SOT-23-6 | top | Yes | Pin 1 at the top-left (the side with 3 pins is left). |
| U12 | SY6280AAC | SOT-23-5 | top | Yes | Pin 1 at the top-left (the side with 3 pins is left). |
| U13 | PCM5102A | TSSOP-20_4.4x6.5mm_P0.65mm | top | Yes | Pin 1 dot at the top-left. |
| U14 | TPA3118D2 | HTSSOP-32-1EP_6.1x11mm_P0.65mm_EP5 | top | Yes | Pin 1 dot at the top-right. |
| U15 | ICS-43434 | InvenSense_ICS-43434-6_3.5x2.65mm | bottom | Yes | Pin 1 at the bottom-right (seen from the bottom side). The sound port hole must line up with the hole in the PCB. |
| U16 | ICS-43434 | InvenSense_ICS-43434-6_3.5x2.65mm | bottom | Yes | Pin 1 at the bottom-right (seen from the bottom side). The sound port hole must line up with the hole in the PCB. |
| U17 | SCD40 | Sensirion_SCD4x-1EP_10.1x10.1mm_P1 | top | Yes | Pin 1 dot at the top-left. |
| U18 | BME688 | Bosch_LGA-8_3x3mm_P0.8mm_Clockwise | top | Yes | Pin 1 dot at the top-left. |
| U19 | 74AHCT1G125 | SOT-23-5 | top | Yes | Pin 1 at the top-left (the side with 3 pins is left). |
| Y1 | 12MHz | Crystal_SMD_3225-4Pin_3.2x2.5mm | top | Only 90 deg | Pins 1/3 are the crystal, 2/4 ground. 0 and 180 are fine; 90 would swap them. Pin 1 belongs bottom-left. |

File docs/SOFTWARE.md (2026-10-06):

# Jarvis HomeDeck software

Everything runs on the CM4 as one systemd service, `homedeck.service`, from `/opt/homedeck`. Config lives in
`/var/lib/homedeck/config.json` (mode 0600, never in the repo). The device UI is Chromium in kiosk mode on the
touch panel; phones get a separate remote app on `https://jarvis.example.com` behind Google sign-in.

## Layout

```
software/homedeck/
  server.py            core: config, module loader, event bus, HTTP API, auth gate, secret redaction, CSP
  modules/*.py         one file per feature (see below)
  web/index.html       device UI shell + apps
  web/shell.js         app registry, home screen, switcher, now playing, controls, events
  web/keyboard.js      on-screen keyboard (also injected into Spotify's sign-in pages)
  web/style.css        design system, landscape rules, touch targets
  web/themes/          home screen styles (weather-led is the one in use)
  web/apps/*.js        one file per app
  web/remote.*         phone app
  install.sh           full install/update on the Pi
  install/             kiosk script, audio setup, Caddy, DuckDNS/UPnP, Spotify event hook, voice deps
```

## Module contract

A module is a Python file in `modules/` with `NAME`, `DEFAULTS`, `state()`, `api(action, params)`, a blocking
`start(ctx)` loop, an optional `intent(text)` for voice (return a spoken string, `""` for a silently handled
command, or `None` if the text is not yours) and optional `ROUTES` for raw HTTP. `ctx` gives config, logging,
`emit`/`on` events and `module(name)` for cross-module calls. Apps register with `HD.registerApp({...})` and get
`render`, `update(state)`, `idleWidget` for a home tile and `onEvent`.

## Modules

| Module | What it does |
|---|---|
| voice | Wake word (openwakeword "hey jarvis"), recorder with hysteresis end-of-speech and speculative transcription, Groq Whisper STT, local intents (math, time, volume, stop), module intents, Groq chat (qwen, reasoning off) with web search fallback, Orpheus TTS with Piper offline fallback, conversation history and recall, offline mode, mic taps for other modules |
| timers | Persistent countdown timers with labels, pause, add time, ringing until stopped; understands most phrasings and STT mishearings |
| alarms, reminders, lists, calendar, countdowns, memory | The usual assistant basics; calendar from private iCal URLs; countdowns also derived from calendar titles |
| spotify | Spotify Connect speaker (librespot / go-librespot) plus a full Web API client: library, search, playlists, queue, devices, likes, on-device sign-in with the injected keyboard |
| youtube | yt-dlp search, ffmpeg remux stream for an ad-free native player, iframe fallback |
| sensors | SCD40 / BME688 / J12 sensors, comfort zones, nudges, one-minute history log, daily spoken air report |
| weather | Open-Meteo forecast and the animated sky |
| bikes | Bay Wheels GBFS: station health, corrected e-bike counts, nearest free e-bikes, morning warning |
| transit | BART (legacy API) and Muni (511.org key) departures with walking time |
| flights | Live ADS-B aircraft around home with routes and a radar view |
| leds | WS2812B strip: lamp, Jarvis patterns, timer fill, music-reactive VU, sunrise |
| display | Backlight from ambient light, night mode, manual override, screen off, orientation, power button |
| fan | CM4 fan with auto thresholds |
| sleep | Generated sleep sounds with a fading sleep timer |
| presence | Home/away from phones on the LAN; drives notifications |
| guest | Wi-Fi QR card and house notes; "give me the wifi" overlay |
| wifi | Scan, join and forget networks from Settings |
| notify | ntfy push notifications |
| auth | Google OAuth sign-in for the phone app |
| audio | System volume (ALSA softvol shared by everything) |

## Things that are not obvious

- Chromium runs with `--alsa-output-device=default` and a dead `PULSE_SERVER` so browser audio shares the ALSA
  dmix/softvol chain with Jarvis and Spotify instead of PipeWire taking the card exclusively.
- The on-screen keyboard is our own page-level keyboard; squeekboard is installed but never shows in Chromium.
- Landscape is the default orientation (config `general.orientation`), applied live via wlr-randr and at boot by
  `install/kiosk.sh`. Landscape CSS lives in `@media (orientation: landscape) and (max-height: 600px)` blocks.
- Groq's free tier changes its model list; the fast model is configurable (`voice.llm.groq_fast_model`).
- The language model is told it cannot perform actions; every command is matched on the device first, and the
  timers module accepts common STT mishearings of "timer".
- Secrets are redacted in every API response (`*key`, `*secret`, `*token`, `*password`) with a `_set` flag for
  the UI; the phone app never receives them.
- Deploying: `install.sh` for everything, or copy single files and `systemctl restart homedeck.service`. Web
  files hot-reload in the kiosk when their version changes. Timers, conversation history, air history and
  YouTube history persist in `/var/lib/homedeck/` across restarts and power loss.
- Chromium keeps its shared memory in /tmp on this board (Debian's `/etc/chromium.d/dev-shm` rule) and leaks it
  slowly; after about a day /tmp fills and the page shows "Reconnecting" while the service is fine.
  `install/kiosk_watchdog.py`, started by `kiosk.sh`, restarts the browser when /tmp passes 70 %, when the page
  has been offline for a minute while the server answers, or at 4 AM, and never while the screen is being touched.
- Echo cancellation: `/etc/asound.conf` tees the speaker feed into an ALSA loopback card (snd-aloop, clocked from the
  I2S card via `timer_source`, ignored by WirePlumber), and `install/aec/homedeck-aec` (WebRTC AEC3, built by
  `install/aec/build.sh`) reads mics + loopback and feeds cleaned 16 kHz audio to the voice pipeline. The echo
  reaches the mics 20-40 ms before the loopback copy, so the mic path is delayed 60 ms. Live on the device at
  volume 55 it removes ~16 dB of music echo; the pipeline falls back to plain arecord if the helper dies twice in
  a minute. Settings: `voice.aec` (delay_ms, mic_delay_ms, ns, stereo_ref, music_wake_threshold). The Jarvis app has
  a Voice calibration card (api `voice/calibrate`) to re-measure after the enclosure changes the acoustics.

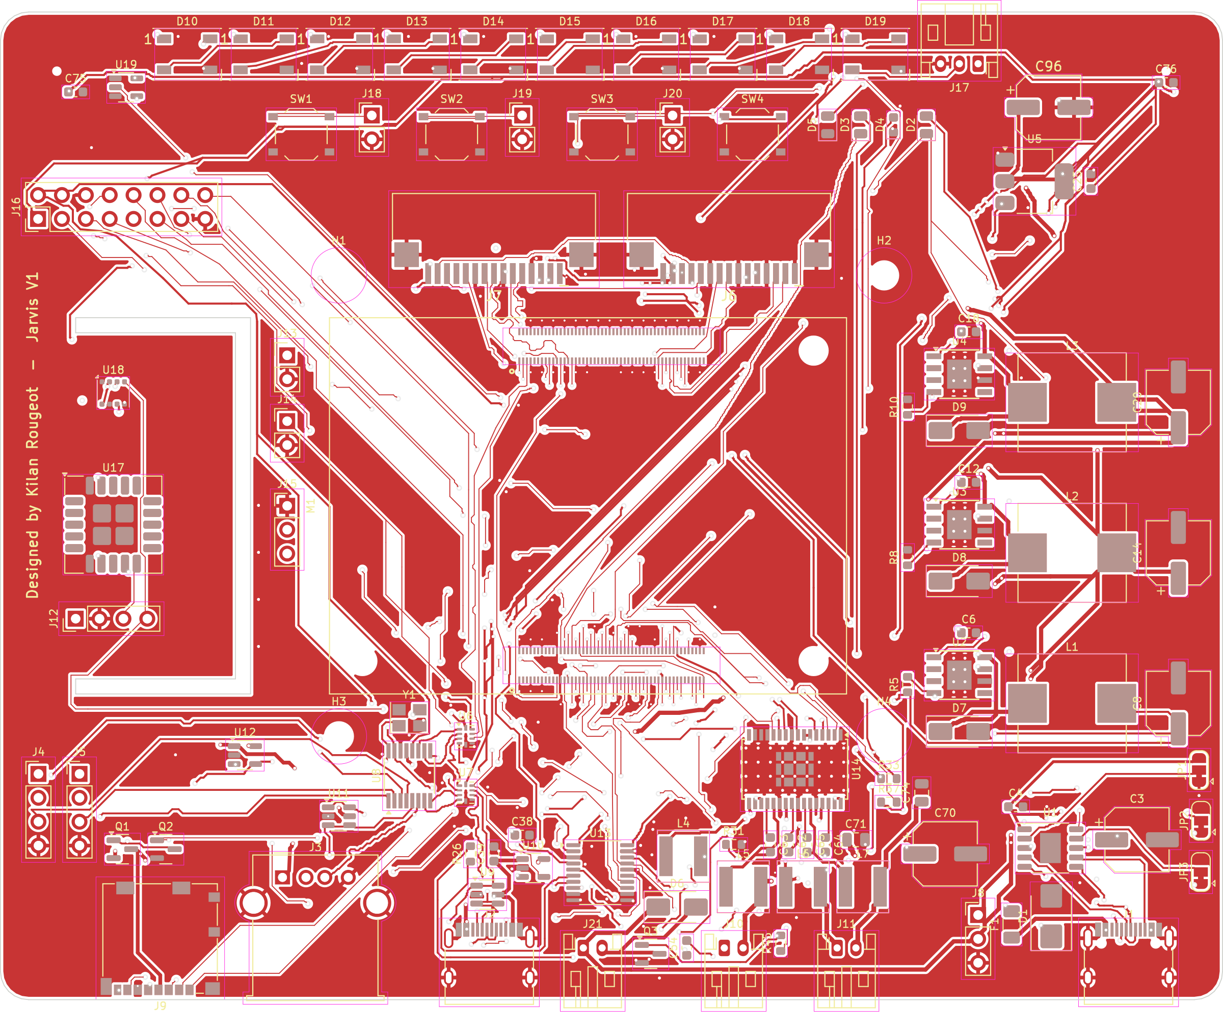
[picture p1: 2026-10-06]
out/board_top.png

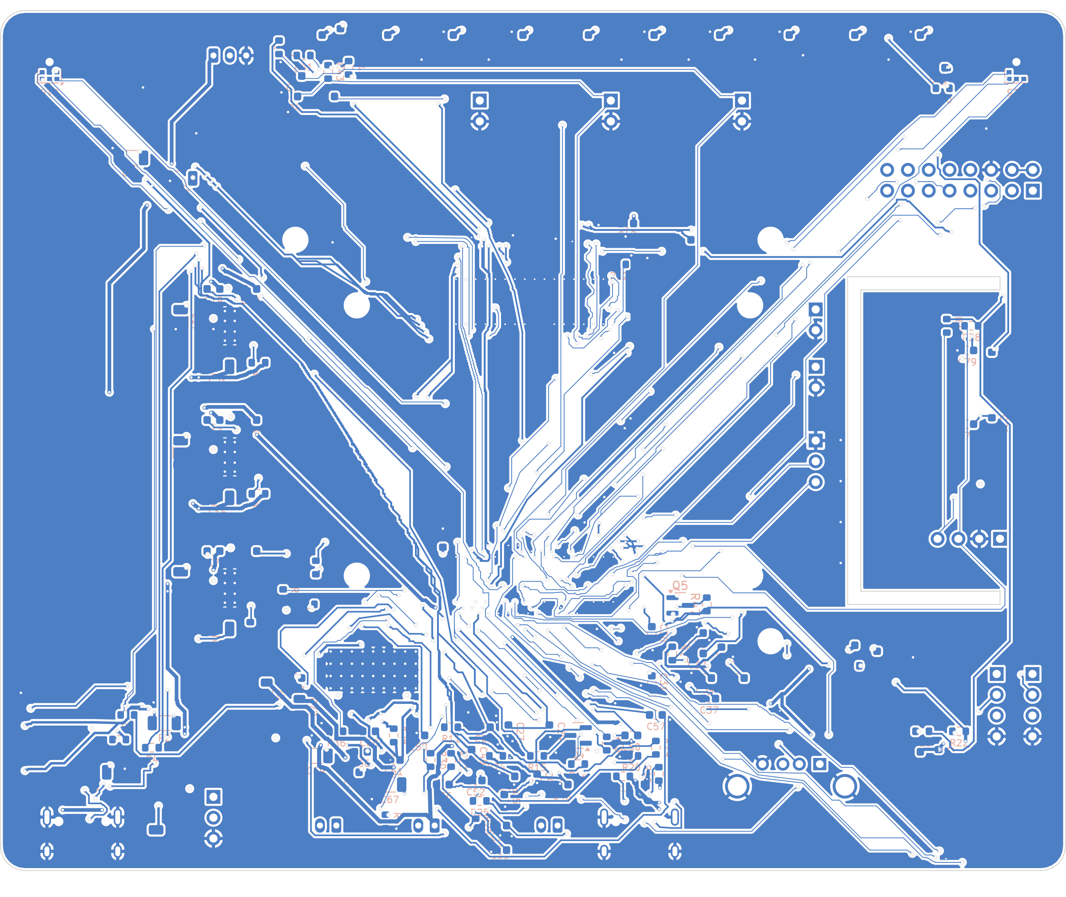
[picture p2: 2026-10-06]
out/board_bottom.png

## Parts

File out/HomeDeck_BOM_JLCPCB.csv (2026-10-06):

Comment | Designator | Footprint | LCSC Part # | MPN | JLC type | Description | JLC stock (2026-09-06)
TYPE-C-31-M-12 | J1,J2 | USB_C_Receptacle_HRO_TYPE-C-31-M-12 | C165948 | TYPE-C-31-M-12 | Extended | USB-C receptacle 16P (power input) | 295816
5A | F1 | Fuse_1206_3216Metric | C48332 | SF-1206F500-2 | Extended | 5 A fast-acting 1206 fuse (Bourns) | 10183
SMBJ24A | D1 | D_SMB | C87268 | SMBJ24A | Extended | VBUS TVS, cathode (band) to VBUS | 31850
10uF/50V | C1,C2,C5,C11,C17,C67,C69 | C_1206_3216Metric | C13585 |  | Basic |  | 3886433
100uF/35V | C3,C8,C14,C20,C96,C70 | CP_Elec_6.3x7.7 | C3339 |  | Extended |  | 45052
CH224K | U1 | ESSOP-10-1EP_3.9x4.9mm_P1.0mm | C970725 | CH224K | Extended | USB PD sink controller | 3137
5.1k | R1,R21 | R_0603_1608Metric | C23186 |  | Basic |  | 24366811
1k/0.25W | R2 | R_1206_3216Metric | C4410 |  | Basic |  | 3103095
1uF | C4,C32,C54,C55,C57,C58,C59,C60 | C_0603_1608Metric | C15849 |  | Basic |  | 9141046
10k | R3,R11,R47,R17,R22,R23,R25,R35,R36,R37,R42,R43,R44 | R_0603_1608Metric | C25804 |  | Basic |  | 32438109
KT-0805G | D2,D3,D5 | LED_0805_2012Metric | C2297 | KT-0805G | Basic |  | 1844100
470R | R4,R26,R29,R41 | R_0603_1608Metric | C23179 |  | Basic |  | 7850550
TPS5430 | U2,U3,U4 | TI_SO-PowerPAD-8_ThermalVias | C9864 | TPS5430DDAR | Basic | 3A buck -> 5V_SYS | 149924
100nF | C6,C10,C12,C16,C18,C22,C25,C26,C29,C30,C31,C34,C35,C43,C45,C47,C48,C61,C75,C76,C78,C79,C80,C81,C82,C83,C84,C85,C86,C87,C88,C89,C90,C91,C93,C94,C95 | C_0603_1608Metric | C14663 |  | Basic |  | 65400153
10nF | C7,C13,C19 | C_0603_1608Metric | C57112 |  | Basic |  | 9208836
SS34 | D7,D8,D9,D6 | D_SMA | C8678 | SS34 | Basic |  | 5300408
10uH 7.8A | L1,L2,L3 | L_Sunlord_MWSA1004S | C408487 | MWSA1004S-100MT | Extended |  | 8080
22uF/25V | C9,C15,C21,C23,C24 | C_1206_3216Metric | C12891 |  | Basic |  | 1473417
15k | R5,R7,R9 | R_0603_1608Metric | C22809 |  | Basic |  | 5368460
4.7k | R6,R8,R10,R38,R39 | R_0603_1608Metric | C23162 |  | Basic |  | 28145041
AMS1117-3.3 | U5 | SOT-223-3_TabPin2 | C6186 | AMS1117-3.3 | Basic |  | 1493311
10uF | C27,C28,C33,C38,C39,C40,C41,C42,C44,C46,C49,C77,C92 | C_0603_1608Metric | C96446 |  | Basic |  | 4908933
330R | R13,R40 | R_0603_1608Metric | C23138 |  | Basic |  | 4491301
AO3401A | Q4,Q1 | SOT-23 | C15127 | AO3401A | Basic | PWR LED buffer | 715738
100k | R14,R33,R46 | R_0603_1608Metric | C25803 |  | Basic |  | 25165711
PWR (red) | D4 | LED_0603_1608Metric | C2286 | KT-0603R | Basic |  | 4584108
1k | R15 | R_0603_1608Metric | C21190 |  | Basic |  | 29352441
B-2100S02P-A110 | J13,J14,J18,J19,J20 | PinHeader_1x02_P2.54mm_Vertical | C124375 | B-2100S02P-A110 | Extended |  | 182578
B-2100S03P-A110 | J15,J8 | PinHeader_1x03_P2.54mm_Vertical | C124376 | B-2100S03P-A110 | Extended |  | 18108
Expansion | J16 | PinHeader_2x08_P2.54mm_Vertical | C492425 | PZ254V-12-16P | Extended |  | 29777
TS-1187A-B-A-B | SW4,SW1,SW2,SW3 | SW_Push_1P1T_XKB_TS-1187A | C318884 | TS-1187A-B-A-B | Basic |  | 860979
220R | R16 | R_0603_1608Metric | C22962 |  | Basic |  | 2214404
TS3USB221 | U6,U7 | Texas_UQFN-10_1.5x2mm_P0.5mm | C130085 | TS3USB221RSER | Extended | USB 2.0 2:1 mux | 36241
2N7002 | Q5,Q2 | SOT-23 | C8545 | 2N7002 | Basic | nRPIBOOT inverter for U6 select | 2245681
CH334R | U8 | QSOP-16_3.9x4.9mm_P0.635mm | C4154405 | CH334R | Extended | USB 2.0 4-port hub | 26952
12MHz | Y1 | Crystal_SMD_3225-4Pin_3.2x2.5mm | C9002 | X322512MSB4SI | Basic |  | 142602
22k | R18,R19,R27,R30 | R_0603_1608Metric | C31850 |  | Basic |  | 4382672
USBLC6-2SC6 | U9,U11 | SOT-23-6 | C7519 | USBLC6-2SC6 | Extended |  | 48108
SY6280AAC | U10,U12 | SOT-23-5 | C55136 | SY6280AAC | Extended | USB-C #2 power switch 1.3A | 32462
3.9k | R20 | R_0603_1608Metric | C23018 |  | Basic |  | 1171777
USB-A | J3 | USB_A_Molex_67643_Horizontal | C2346 | 901-211A1021D10100 | Extended |  | 33420
B-2100S04P-A110 | J4,J5,J12 | PinHeader_1x04_P2.54mm_Vertical | C124378 | B-2100S04P-A110 | Extended |  | 105951
1.0-15PContact,Bottom | J6,J7 | FPC_15P_1.0mm_BottomContact_RA | C66660 | 1.0-15PContact,Bottom | Extended | 15-pin 1.0mm FPC, bottom contact, right angle (BOOMELE) | 3138
microSD | J9 | microSD_HC_Molex_104031-0811 | C585350 | 104031-0811 | Extended |  | 13273
PCM5102A | U13 | TSSOP-20_4.4x6.5mm_P0.65mm | C107671 | PCM5102APWR | Extended | I2S stereo DAC | 10504
10R | R24,R34 | R_0603_1608Metric | C22859 |  | Basic |  | 9636923
2.2uF | C50,C51,C52 | C_0603_1608Metric | C23630 |  | Basic |  | 3821265
2.2nF | C53,C56 | C_0603_1608Metric | C1604 |  | Basic |  | 1417575
6.8k | R28,R31 | R_0603_1608Metric | C23212 |  | Basic |  | 2243339
TPA3118D2 | U14 | HTSSOP-32-1EP_6.1x11mm_P0.65mm_EP5.2x11mm_Mask4.11x4.36mm_ThermalVias | C46497 | TPA3118D2DAPR | Extended | Stereo class-D amplifier | 39991
20k | R32 | R_0603_1608Metric | C4184 |  | Basic |  | 7878441
220nF | C62,C63,C64,C65 | C_0603_1608Metric | C21120 |  | Basic |  | 1068539
1nF | C66,C68 | C_0603_1608Metric | C1588 |  | Basic |  | 10301799
10uH 2.1A | L4,L5,L6,L7 | L_Sunlord_SWPA5040S | C84608 | SWPA5040S100MT | Extended |  | 72976
1uF/50V | C71,C72,C73,C74 | C_0805_2012Metric | C28323 |  | Basic |  | 3981237
S2B-PH-K-S | J10,J11,J21 | JST_PH_S2B-PH-K_1x02_P2.00mm_Horizontal | C173752 | S2B-PH-K-S | Extended |  | 29753
ICS-43434 | U15,U16 | InvenSense_ICS-43434-6_3.5x2.65mm | C5656610 | ICS-43434 | Extended | I2S MEMS mic LEFT | 4500
SCD40 | U17 | Sensirion_SCD4x-1EP_10.1x10.1mm_P1.25mm_EP4.8x4.8mm | C3659421 | SCD40-D-R2 | Extended | CO2 sensor | 3075
BME688 | U18 | Bosch_LGA-8_3x3mm_P0.8mm_ClockwisePinNumbering | C3664478 | BME688 | Extended | Temp/humidity/pressure/VOC | 1339
74AHCT1G125 | U19 | SOT-23-5 | C7484 | SN74AHCT1G125DBVR | Extended | 3.3->5V level shifter | 26202
WS2812B | D10,D11,D12,D13,D14,D15,D16,D17,D18,D19 | LED_WS2812B_PLCC4_5.0x5.0mm_P3.2mm | C2761795 | WS2812B-B/T | Extended |  | 167528
LED strip ext | J17 | JST_PH_S3B-PH-K_1x03_P2.00mm_Horizontal | C157929 | S3B-PH-K-S | Extended |  | 155016
AO3400A | Q3 | SOT-23 | C20917 | AO3400A | Basic |  | 964371
100R | R45 | R_0603_1608Metric | C22775 |  | Basic |  | 13946107
DF40C-100DS-0.4V(51) | M1A,M1B | Hirose_DF40C-100DS-0.4V | C597931 | DF40C-100DS-0.4V(51) | Extended | CM4 socket, 100-pin 0.4 mm, 1.5 mm stack (genuine Hirose; low stock, may be pre-order) | 25

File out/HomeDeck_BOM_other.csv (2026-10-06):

Designator | Value | Footprint | Note
M1 | Raspberry Pi CM4 | HomeDeck:RPi_CM4 | not in JLC library: Compute Module 4 (2x DF40C-100DS-0.4V(51), JLC C597931)
R12 | 0R | Resistor_SMD:R_0603_1608Metric | DNP (do not populate)
C36 | 22pF | Capacitor_SMD:C_0603_1608Metric | DNP (do not populate)
C37 | 22pF | Capacitor_SMD:C_0603_1608Metric | DNP (do not populate)

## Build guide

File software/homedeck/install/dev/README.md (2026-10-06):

# Dev helpers (run on the Pi)

- `cdp_eval.py "<js>"` runs JavaScript in the kiosk Chromium through DevTools on 127.0.0.1:9222, e.g.
  `HD.openApp("sensors")` then `grim /tmp/shot.png` (with `WAYLAND_DISPLAY=wayland-0 XDG_RUNTIME_DIR=/run/user/1000`)
  for a screenshot of a page, and `HD.showIdle()` to go back.
- `threadcpu.py <pid> [seconds]` per-thread CPU of the service (`systemctl show -p MainPID --value homedeck`).
- `aecdump_analyze.py` per-second echo reduction and echo delay for both mics from a helper dump
  (`kill -USR1` the homedeck-aec process after setting dump_s in /var/lib/homedeck/aec_runtime.conf).
- `wake_mix.py` offline check that summing two mics keeps the wake word detectable (needs the piper voices).

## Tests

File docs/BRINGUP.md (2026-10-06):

# HomeDeck CM4 – ordering, assembly and bring-up

## 0. Shopping list and how it fits together

What you buy besides the assembled board:

| Item | Notes |
|---|---|
| Raspberry Pi Compute Module 4, **wireless**, eMMC (e.g. CM4104016: 4 GB RAM / 16 GB eMMC / Wi-Fi) | Wireless is mandatory (no Ethernet on the board). Lite (no eMMC) works too but then you need a microSD card. Not a CM5. |
| Raspberry Pi Touch Display 2 (7") | Comes with the 15-way DSI ribbon, a 2-wire power lead with female Dupont ends, and four M2.5 screws. |
| Raspberry Pi Camera Module 3 (or v2) | Comes with a 15-way ribbon. Any length is fine; 200 mm gives room to position it in the bezel. |
| 2x speakers, 8 ohm, 3-5 W, ideally with a JST-PH 2.0 mm 2-pin lead | Search "8 ohm 5W speaker JST PH". Otherwise crimp JST-PH housings onto plain speakers. |
| USB-C PD charger, 45-65 W, plus a USB-C cable rated for it | Must offer 15 V (any laptop-class PD charger does). A phone charger will not boot the board. |
| USB-A to USB-C cable | To flash the eMMC from a PC (rpiboot) and for the USB-C data port. |
| M2.5 standoffs 3-4 mm tall (4x) and M2.5 nuts/screws | Board-to-display spacing; the display's own standoffs are on the Pi hole pattern. |
| 2.54 mm jumper cap (2x) | One for the nRPIBOOT jumper J14 during flashing, one spare. |
| Optional: 30 mm 5 V fan with JST-PH 2-pin lead | Plugs into J21. Only needed if the enclosure is sealed. |
| Optional: BH1750 (GY-302) light-sensor breakout + 4 female-female Dupont wires | Plugs into J12; mount it behind the bezel where it sees the room. |
| Optional: microSD card | Only for a CM4 Lite. |
| Optional: WS2812B LED strip with 3-pin JST-PH lead | J17, if you want light outside the board's own 10-LED bar. |
| Optional: panel-mount buttons (3x) with 2-wire leads | J18/J19/J20, if the on-board tactile switches are not reachable through the enclosure. |
| Optional: Zigbee/Thread USB dongle | Plugs into an internal USB header J4/J5 (5V, D-, D+, GND) with a 4-wire lead, or into the USB-A port. |

How it goes together (all connectors are on the top side unless noted):

1. **Board on display.** The board's bottom side faces the back of the display. Line up the four M2.5 holes (H1-H4, the 58 x 49 mm Pi pattern) with the display's standoffs, put 3-4 mm standoffs in between and screw down. The bottom side only has flat 0603-1206 parts and the two mics, which is why it fits.
2. **CM4 on the board.** Press the module onto the two 100-pin sockets (M1A/M1B) until it clicks, then M2.5 screws through its four corner holes into standoffs. Fit the official CM4 heatsink if you have one; the enclosure needs airflow there.
3. **Display ribbon.** 15-way ribbon from the display's DSI connector to **J6** (the right-hand FPC connector above the CM4). Both ends are bottom-contact: pull the black latch out, insert the cable with the **bare contacts facing the PCB** (blue stiffener up), push the latch back. The ribbon exits toward the top edge of the board.
4. **Display power.** The display's power lead with the two Dupont sockets goes on **J8** ("DISPLAY 5V", 3 pins next to the USB-C power input): red/5 V on pin 1 or 2 (both are 5V_PERIPH), black/GND on pin 3.
5. **Camera ribbon.** From the camera to **J7** (the left-hand FPC connector), same orientation rule. The camera enable is handled by the CM4 pin, nothing to set.
6. **Speakers.** JST-PH plugs into **J10** (left) and **J11** (right), pin 1 = +. If the speakers have no polarity marking it does not matter, just be consistent.
7. **Power.** PD charger into **J1**, the USB-C at the right end of the bottom edge (the other USB-C, **J2**, is the data port). D2 lights green when the charger agreed to 15 V.
8. **Optional bits.** Fan on J21 (pin 1 = 5 V). Light sensor on J12: 3V3, GND, SDA, SCL in that order. External LED strip on J17: 5 V, DATA, GND. Panel buttons on J18 (power), J19 (button A), J20 (button B), each to GND. UART debug on J15: GND, TX, RX (3.3 V logic, use a USB-UART adapter).
9. **First flash.** With an eMMC CM4: jumper on J14, USB-A-to-C from the PC into J2, power up, run rpiboot, then Raspberry Pi Imager onto the disk that appears, then remove the jumper and reboot. With a Lite: write the OS to the microSD and put it in J9 (bottom edge, left). Then follow sections 2-4 below.

## 1. Ordering from JLCPCB

1. Upload `out/HomeDeck_gerbers.zip`. Choose: 4 layers, 1.6 mm, 1 oz outer copper, ENIG surface finish (the CM4 connector pads are 0.2 mm wide – HASL is not flat enough), any colour, "Specify stackup" is not needed (JLC7628 default is fine, there are no controlled-impedance traces).
2. Tick SMT assembly, **both sides** ("Standard" assembly, not "Economic"). 116 of the 218 assembled parts sit on the bottom: all the decoupling and filter passives (0603/0805/1206 only), the two ICS-43434 microphones and two SOT-23 FETs. Everything tall (connectors, bucks, hub, amp, CM4 sockets) is on top. Hand-soldering the bottom side is possible but it is over 100 passives, so pay for two-sided assembly.
3. Upload `out/HomeDeck_BOM_JLCPCB.csv` and `out/HomeDeck_CPL_JLCPCB.csv`.
4. In the part-matching step, check every line. Part numbers were verified against the JLC catalogue while designing, but stock changes weekly. Known things to expect:
   * The DF40C-100DS-0.4V(51) sockets are LCSC/JLC part C597931 (genuine Hirose, Extended; only ~25 in stock on 2026-09-06 with an 11-day pre-order lead time, minimum order 9 pieces). 2 per board, BOM/CPL designators `M1A` and `M1B`; the KiCad footprint is a single `M1` CM4 footprint that contains both. If JLC cannot supply them, order from Digi-Key/Mouser and hand-reflow them (ENIG + stencil). Pin 1 of each socket is the left-hand pad of its lower row (M1A pin 1 at x=55.2, y=71.0; M1B pin 1 at x=55.2, y=37.08 in board coordinates) – check the orientation in JLC's placement preview.
   * The two 15-pin FPC connectors are BOOMELE "1.0-15PContact,Bottom" (C66660, 1.0 mm pitch, bottom contact, right angle, ~3,000 in stock). The footprint follows that part's drawing (0.6 x 2.2 mm pads, 2.6 x 2.6 mm anchors). The TE 1-84952-5 originally chosen is out of stock at JLC.
   * The fuse is Bourns SF-1206F500-2 (C48332, 5 A fast, ~10,000 in stock); the original 1206FT 5A is out of stock.
   * Every LCSC number was checked on jlcpcb.com on 2026-09-06 (library type and stock are in the last two BOM columns). Lowest stocks: BME688 (~1,300), SCD40 (~3,000), CH224K (~3,100), the FPC connector (~3,100) and the CM4 sockets (25). Everything else is in the tens of thousands or millions. 38 lines are Basic and 28 unique parts are Extended (each Extended part adds JLC's ~$3 feed-loading fee once per order). Every Extended part was checked for a Basic equivalent on 2026-09-06: JLC's Basic library contains no connectors, no hub/mux/PD/audio/sensor ICs, no fuses, no TVS, no power inductors and no ESD arrays, so those 28 cannot be reduced further without changing the design (e.g. dropping the microSD slot or the expansion headers).
   * WS2812B, BME688, SCD40 and the ICS-43434 mics are "Standard assembly only" parts, which is another reason to choose Standard, two-sided assembly.
   * Placement file: positions are the centre of each part's pads (what JLC expects, so connectors and pin headers land where they should) and rotations already include the usual KiCad-to-JLC package corrections (SOT-23 -90, SOIC/TSSOP/QSOP/QFN 270, SOT-223/electrolytics/USB-C/JST 180, etc.), the same table the popular kicad-jlcpcb-tools plugin uses. JLC's own library orientation still varies part by part, so in the placement preview check every polarized part: electrolytic caps (C3, C8, C14, C20, C70), SS34 diodes (D6-D9), SMBJ24A (D1), all LEDs, the WS2812Bs, every IC, and pin 1 of the CM4 sockets, FPC connectors and USB connectors. Rotate in their UI if needed; it does not change your files. `docs/ORIENTATION.md` lists, for every assembled part, whether its orientation matters and which corner/side its pin-1 dot, cathode band or + mark has to be on, so you can check the preview part by part. Square-looking parts still matter: the tactile switches (SW1-SW4) have internally connected pin pairs along the long 6 mm axis, so a 90-degree error shorts the button permanently; the terminals of the inductors and switches must sit on the pads, which the preview shows clearly.
5. Buy separately: Raspberry Pi CM4 (any variant; buy CM4 *Lite* if you want to use the microSD slot), Touch Display 2 (7"), a Pi camera module with 15-pin cable, two 8 ohm 3-5 W speakers with JST-PH leads, a 45-65 W USB-C PD charger, optionally a 5 V 30 mm fan and a BH1750 (GY-302) light-sensor breakout.

## 2. Before applying power

* Visually check the two CM4 connectors under magnification for solder bridges (0.4 mm pitch).
* With no CM4 fitted: measure resistance from VBUS to GND (should be > 1 kΩ), 5V_SYS/5V_PERIPH/5V_USB to GND (> 100 Ω), 3V3 to GND (> 100 Ω).
* D1 (SMBJ24A) band/cathode must face VBUS (the fuse side). Check the nRPIBOOT inverter Q5 (bottom side, under the CM4) is fitted, then check the three PD solder jumpers JP1-3: JP1 bridged 1-2 (CFG1 = GND), JP2 and JP3 bridged 1-2 (CFG2/CFG3 = VDD) → 15 V request.

## 3. First power-on (no CM4)

1. Plug a PD charger into J1 (the right-hand USB-C). D2 (PD OK) should light and VBUS should read 15 V (9 or 12 V if the charger cannot do 15).
2. Check 5.0-5.2 V on the three 5 V rails (test at the big electrolytic caps C14/C20/C29 area) and 3.3 V at U5.
3. Check that the USB-C data port (J2) and USB-A (J3) VBUS pins read 5 V.

## 4. Fit the CM4

1. Press the CM4 onto the two connectors, screw it down with M2.5 screws through the four CM4 holes (use 1.5 mm standoffs if you prefer; the DF40C is a 1.5 mm stack).
2. For an eMMC CM4: fit the nRPIBOOT jumper (J14), connect a PC to J2 with a USB-**A**-to-C cable (a C-to-C cable will not enumerate in this mode because the port's CC pull-ups are switched off with its 5 V), run `rpiboot`, flash Raspberry Pi OS with `rpi-imager`, remove the jumper. For a CM4 Lite: write the OS to a microSD.
3. `config.txt` additions (put at the end):

```
dtoverlay=vc4-kms-v3d
dtoverlay=vc4-kms-dsi-ili9881-7inch      # Touch Display 2
camera_auto_detect=1
otg_mode=1                                # CM4 USB port as host
dtparam=i2c_vc=on
dtoverlay=i2c6,pins_22_23                 # sensors + light sensor header (I2C6, /dev/i2c-6)
dtoverlay=gpio-shutdown,gpio_pin=3        # power button: shutdown while running, wake from halt
dtoverlay=hifiberry-dac                   # PCM5102A on I2S (playback)
dtoverlay=googlevoicehat-soundcard        # alternative: playback + ICS-43434 mic capture in one card
```
Use one of the two audio overlays, not both. `googlevoicehat-soundcard` gives you a full-duplex card (DAC + the two mics as a stereo capture device), which is the easiest way to get both directions working; `hifiberry-dac` is playback-only.

4. GPIO housekeeping the software must do: drive GPIO4 (AMP_SDZ) high to enable the amplifier and keep GPIO5 (AMP_MUTE) low; GPIO24 is the DAC soft-mute (pulled up = unmuted, drive low to mute); GPIO25 is the fan (PWM); GPIO27 reads low when the PD negotiation succeeded; GPIO6 reads low when the amplifier reports a fault.
5. Buttons: GPIO3 = power (handled by the overlay), GPIO16 = button A, GPIO26 = button B, all active-low with pull-ups on the board. User LED on GPIO12 (active high). Light bar: 10x WS2812B on GPIO10 (SPI0 MOSI) – use `rpi_ws281x` / `adafruit-circuitpython-neopixel-spi` in SPI mode, plus whatever you plug into J17.
6. Sensors on I2C6: SCD40 at 0x62, BME688 at 0x76, BH1750 breakout (J12) at 0x23.

## 5. Things to know / possible revision-B items

* The ambient light sensor is not on the board on purpose: it must see the room. Mount the BH1750 breakout behind the bezel and wire it to J12 (3V3, GND, SDA, SCL).
* The BME688 will read a few degrees high if the enclosure traps CM4 heat – the sensor tongue slots help but give the enclosure vents there.
* A 5 V-only USB charger will not boot the board reliably (the bucks need > 6 V). Use a PD charger.
* The USB-C data port is limited to 1.7 A and the USB-A port to 1.3 A by the SY6280 switches; both share the 3 A 5V_USB buck.
* Bottom-side parts are limited to 0603-1206 passives so the board can sit on the display's standoffs; keep at least 2.5 mm standoff height.
* The router is a home-grown grid router; the traces were straightened and the differential pairs length-matched afterwards (see ARCHITECTURE.md section 5 for the numbers). The one pair still out of tolerance by textbook standards is USB-C #2 data (7.7 mm skew); it will work, but it is the first thing to tidy in KiCad if you want to.
* C36 and C37 (22 pF next to the hub crystal Y1) are intentionally not populated: the CH334R has built-in crystal load capacitors. Leave them empty.
* If you ever move the PD jumpers to 20 V, replace R2 (1 k, 0.25 W) with a 0.5 W part; at 15 V it dissipates 0.14 W and is fine.
* Five ground pads have their via inside the pad (U9 pin 2, U11 pin 2, J6 pin 13, J9 pin 6, C61 pin 2) because there was no room next to them. They are 0.45/0.2 mm vias, tented by default, and JLC assembles boards like this every day; if you want to be picky, ask for "via filling / epoxy plugged" on the order (not needed).
* The DRC report (`out/drc.txt`) ends with 0 errors and 0 unconnected items. The 292 remaining entries are all warnings: silkscreen clipped by the board edge (connector outlines that deliberately overhang the edge), reference designators printed over copper, "footprint not in library" (only because the report is generated from the command line without KiCad's global footprint table) and 22 "via connected on one layer" notes, which are fan-out junction vias that are harmless.

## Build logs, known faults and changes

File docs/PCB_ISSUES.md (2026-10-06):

# Rev A findings and the rev B change list

What actually happened when the first two rev A boards were assembled and brought up (September 2026), the
workarounds that are in place on board #1, and what the next revision should change. Board references use the
designators in `kicad/HomeDeck.kicad_pcb`.

## What works on rev A board #1

USB-C PD input, all three bucks, 3.3 V LDO, CM4 (wireless, 4 GB / 16 GB eMMC), Wi-Fi and Bluetooth, DSI display and
Goodix touch, Camera Module 3, SCD40 and BME688 on I2C6, J12 I2C header (SHT4x and BH1750 auto-detected), I2S
microphones, TPA3118 amplifier and speakers, RGB LED bar and the J17 strip (70 LEDs in one chain), fan on J21,
buttons A / B / power, user LED, USB hub and ports. Board #2 is assembled but has not been powered.

## Problems found, in order of importance

### 1. 15 V PD chargers trip on plug-in (power)

Laptop-class PD chargers negotiate 15 V and then trip their protection during the 5 to 15 V step. Only 9 V
sources worked (a 20 W phone charger). The likely cause is inrush into the roughly 280 uF of VBUS bulk capacitance
(C3 100 uF electrolytic plus the buck input caps) at the moment of the voltage step.

Workaround on board #1: request 9 V instead. CH224K configuration jumpers JP2 and JP3 were cut between the
bottom and centre pads and bridged centre to top (CFG2 and CFG3 to GND). The board runs fine at 9 V; the
amplifier has less headroom but the small speakers do not need it.

Rev B: add inrush limiting on VBUS (a P-channel soft-start or a hot-swap controller such as TPS2595, or at least
an NTC in series with C3), reduce C3, and make 9 V the default jumper setting with 15 V as the option. Consider
whether 15 V is needed at all: the only 15 V consumer is the amplifier, and 12 V or 9 V is enough for
Dayton ND65-class speakers.

### 2. 5V_PERIPH rail intermittent (power)

The 5V_PERIPH buck (U3) output was dead on first power-up: no LED bar, no display power on J8. It came alive on
handling the board at the office and stayed up, which points at a poor joint on L2 or at the rail side of the
output stage rather than at U3 itself. U2 and U3 both ran cold, so it was not a load fault.

Workaround: the display was temporarily powered from 5V_SYS on the J16 expansion header (pins 4 and 6). After
the joint reflowed itself the normal path works. Reflow L2 on both boards before trusting them.

Rev B: use a smaller, easier-to-solder inductor footprint for L1 to L3 (the current one is wide and sits over
a plane cutout), add test points on every rail output (5V_SYS, 5V_PERIPH, 5V_USB, 3V3, VBUS), and route the
rails so a meter probe reaches them without a wire.

### 3. microSD slot does not work with an eMMC CM4 (design)

The eMMC variants of the CM4 disable the SD interface, so the slot is dead by design with the module installed.
It only works with a CM4 Lite.

Rev B: either drop the slot and the SD switching, or document it as Lite-only.

### 4. Button A shares GPIO16 with the voice HAT overlay (firmware)

The stock `googlevoicehat-soundcard` overlay claims GPIO16, which is button A. A custom overlay
(`homedeck-audio.dtbo`, same sound card with the amplifier shutdown line moved) fixed it.

Rev B: keep GPIO16 free of buttons, or pick GPIOs that no common audio overlay uses.

### 5. Amplifier pops on shutdown toggling (audio)

Toggling AMP_SDZ (GPIO4) per playback produced pops. The line is now held high permanently and the amplifier is
muted by silence only; the overlay's shutdown control was moved to an unused pin (GPIO13).

Rev B: add a proper mute (TPA3118 has MUTE separate from SDZ) with an RC ramp, and keep the DAC running between
plays. A hardware volume control is not needed because the DAC has none anyway; software volume via ALSA
softvol is fine.

### 6. Temperature sensors read high (thermal)

The SCD40 and BME688 sit close to the CM4 and its heat sink; in portrait mounting they were above the module in
the rising warm air and read 8 to 10 F high. Landscape mounting (sensors beside the module) and a configurable
offset fixed it in software.

Rev B: move the environmental sensors to the board edge farthest from the CM4, ideally on a slot-isolated
tongue with its own vent opening in the enclosure, and put the fan header where the fan pulls air across the
CM4 and away from the sensors.

### 7. Display panel sometimes fails to probe at boot (mechanical)

Occasionally the touch controller returns I2C errors at boot and the panel stays dark; a power cycle with the J6
ribbon reseated fixes it. Swapping the display and camera ribbons (they are different lengths) also broke the
display once.

Rev B: use a locking FPC connector for J6 and label the two FPC connectors clearly with their ribbon lengths.

### 8. Fan is on/off only (features)

J21 drives the fan through a low-side switch on GPIO25. Speed control needs PWM, which the software driver
supports but the hardware does not do smoothly (fans stall below about 35 percent and the switch is not meant
for 25 kHz).

Rev B: a proper PWM fan stage (logic-level MOSFET with a flyback diode, or a 4-wire fan header with a PWM line).

### 9. Chargers report under-voltage at 5 V (power)

With a plain 5 V USB source the CM4 reports under-voltage. Expected, since the design needs PD, but the board
should refuse to boot cleanly rather than brown out.

Rev B: a VBUS good comparator that holds the CM4 in reset below 8.5 V, and a status LED for "PD contract OK".

### 10. Minor

- The onboard LED bar (first 10 LEDs of the chain) is not used in the final enclosure; the external J17 strip is.
  Rev B could drop the bar or put it on a separate data line so the strip index does not start at 10.
- J19 and J20 button headers were clipped off to make room; only J18 (power button) is used.
- `config.txt` on Trixie does not accept trailing comments on a line; the bring-up doc now says so.
- Keep `enable_uart=1` and a serial adapter handy for bring-up; it saved time twice.
- Add the CM4 stack height (1.5 mm DF40C) and the display standoff pattern to the enclosure notes; the enclosure
  reference SVG lives outside the repo.

## Rev B change list, short form

1. Inrush limiter on VBUS, smaller C3, 9 V default jumpers.
2. Rail test points and friendlier inductor footprints.
3. Drop or clearly mark the microSD slot.
4. Move buttons off GPIO16; move the sensors away from the CM4; fan header positioned for airflow.
5. Amplifier mute with a ramp; keep SDZ high.
6. PWM fan stage.
7. Locking FPC connector for the display; label ribbon lengths.
8. VBUS-good reset gate and a PD status LED.
9. Optional: remove the onboard LED bar.

### Display controller hangs across a warm reboot (rev B: switchable display rail)

The Touch Display 2 keeps 5 V through a software reboot. After some warm reboots its controller (I2C 0x45 on the
CSI/DSI bus) no longer answers (`touch_reg -EREMOTEIO`, `pwm-backlight -EIO`); the DSI panel driver depends on
the backlight, so the screen stays black until power is removed. Seen 2026-09-19 and twice on 2026-10-05. All three
TPS5430 EN pins are no-connect (always on), so software cannot power-cycle the panel.
Rev B: drive the EN of the buck that feeds J8 (5V_PERIPH) from a GPIO through a pull-up (on by default), or put a
load switch on the J8 output, so the system can cycle the display for ~1 s before or after a reboot.

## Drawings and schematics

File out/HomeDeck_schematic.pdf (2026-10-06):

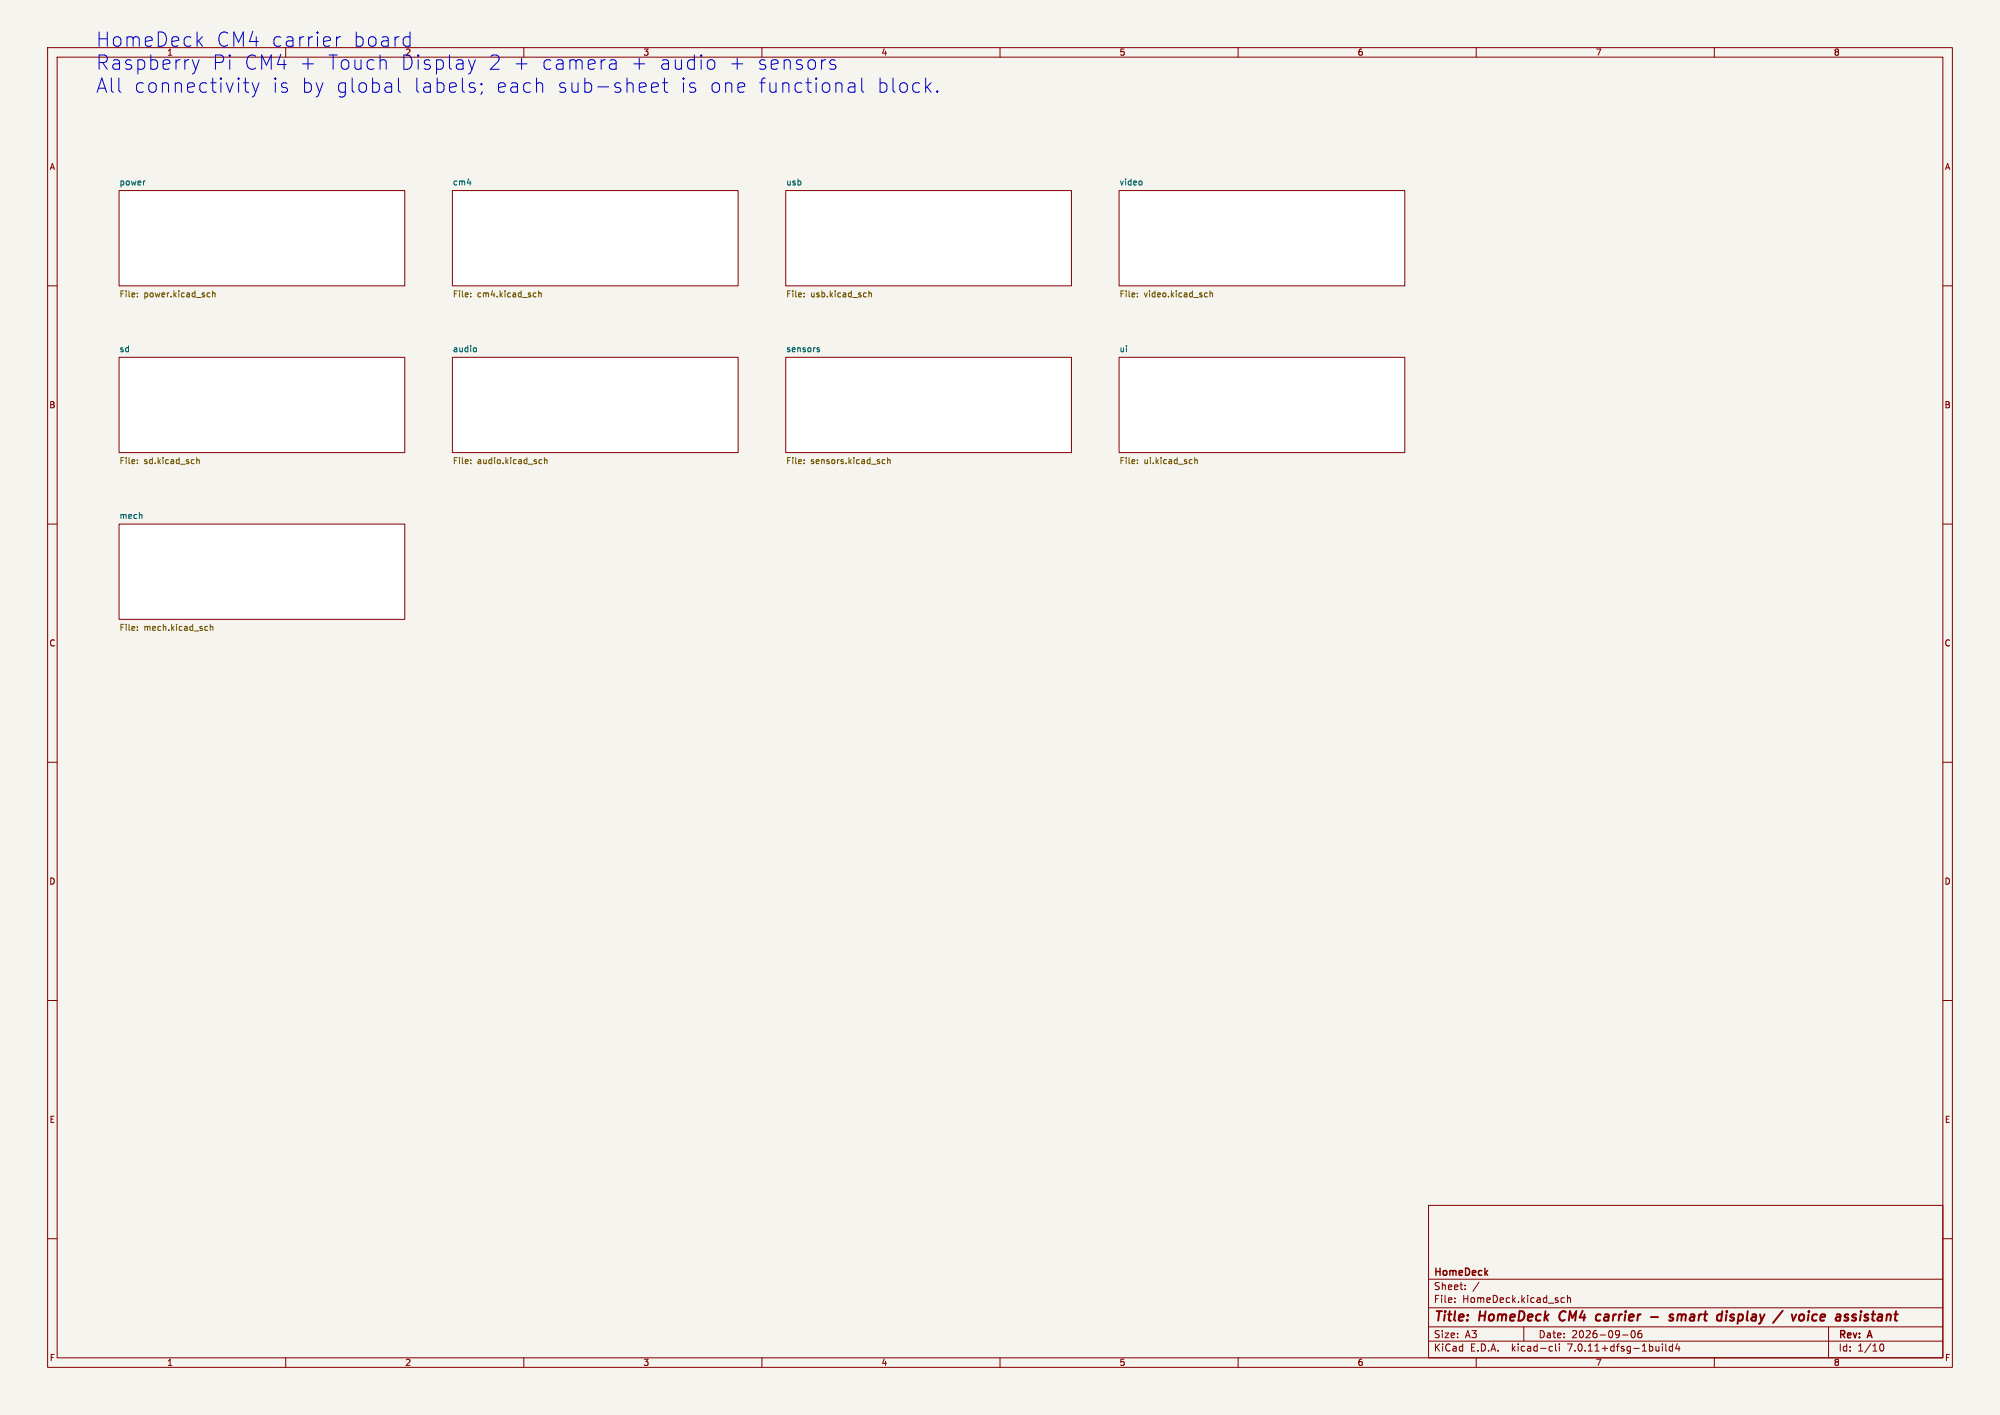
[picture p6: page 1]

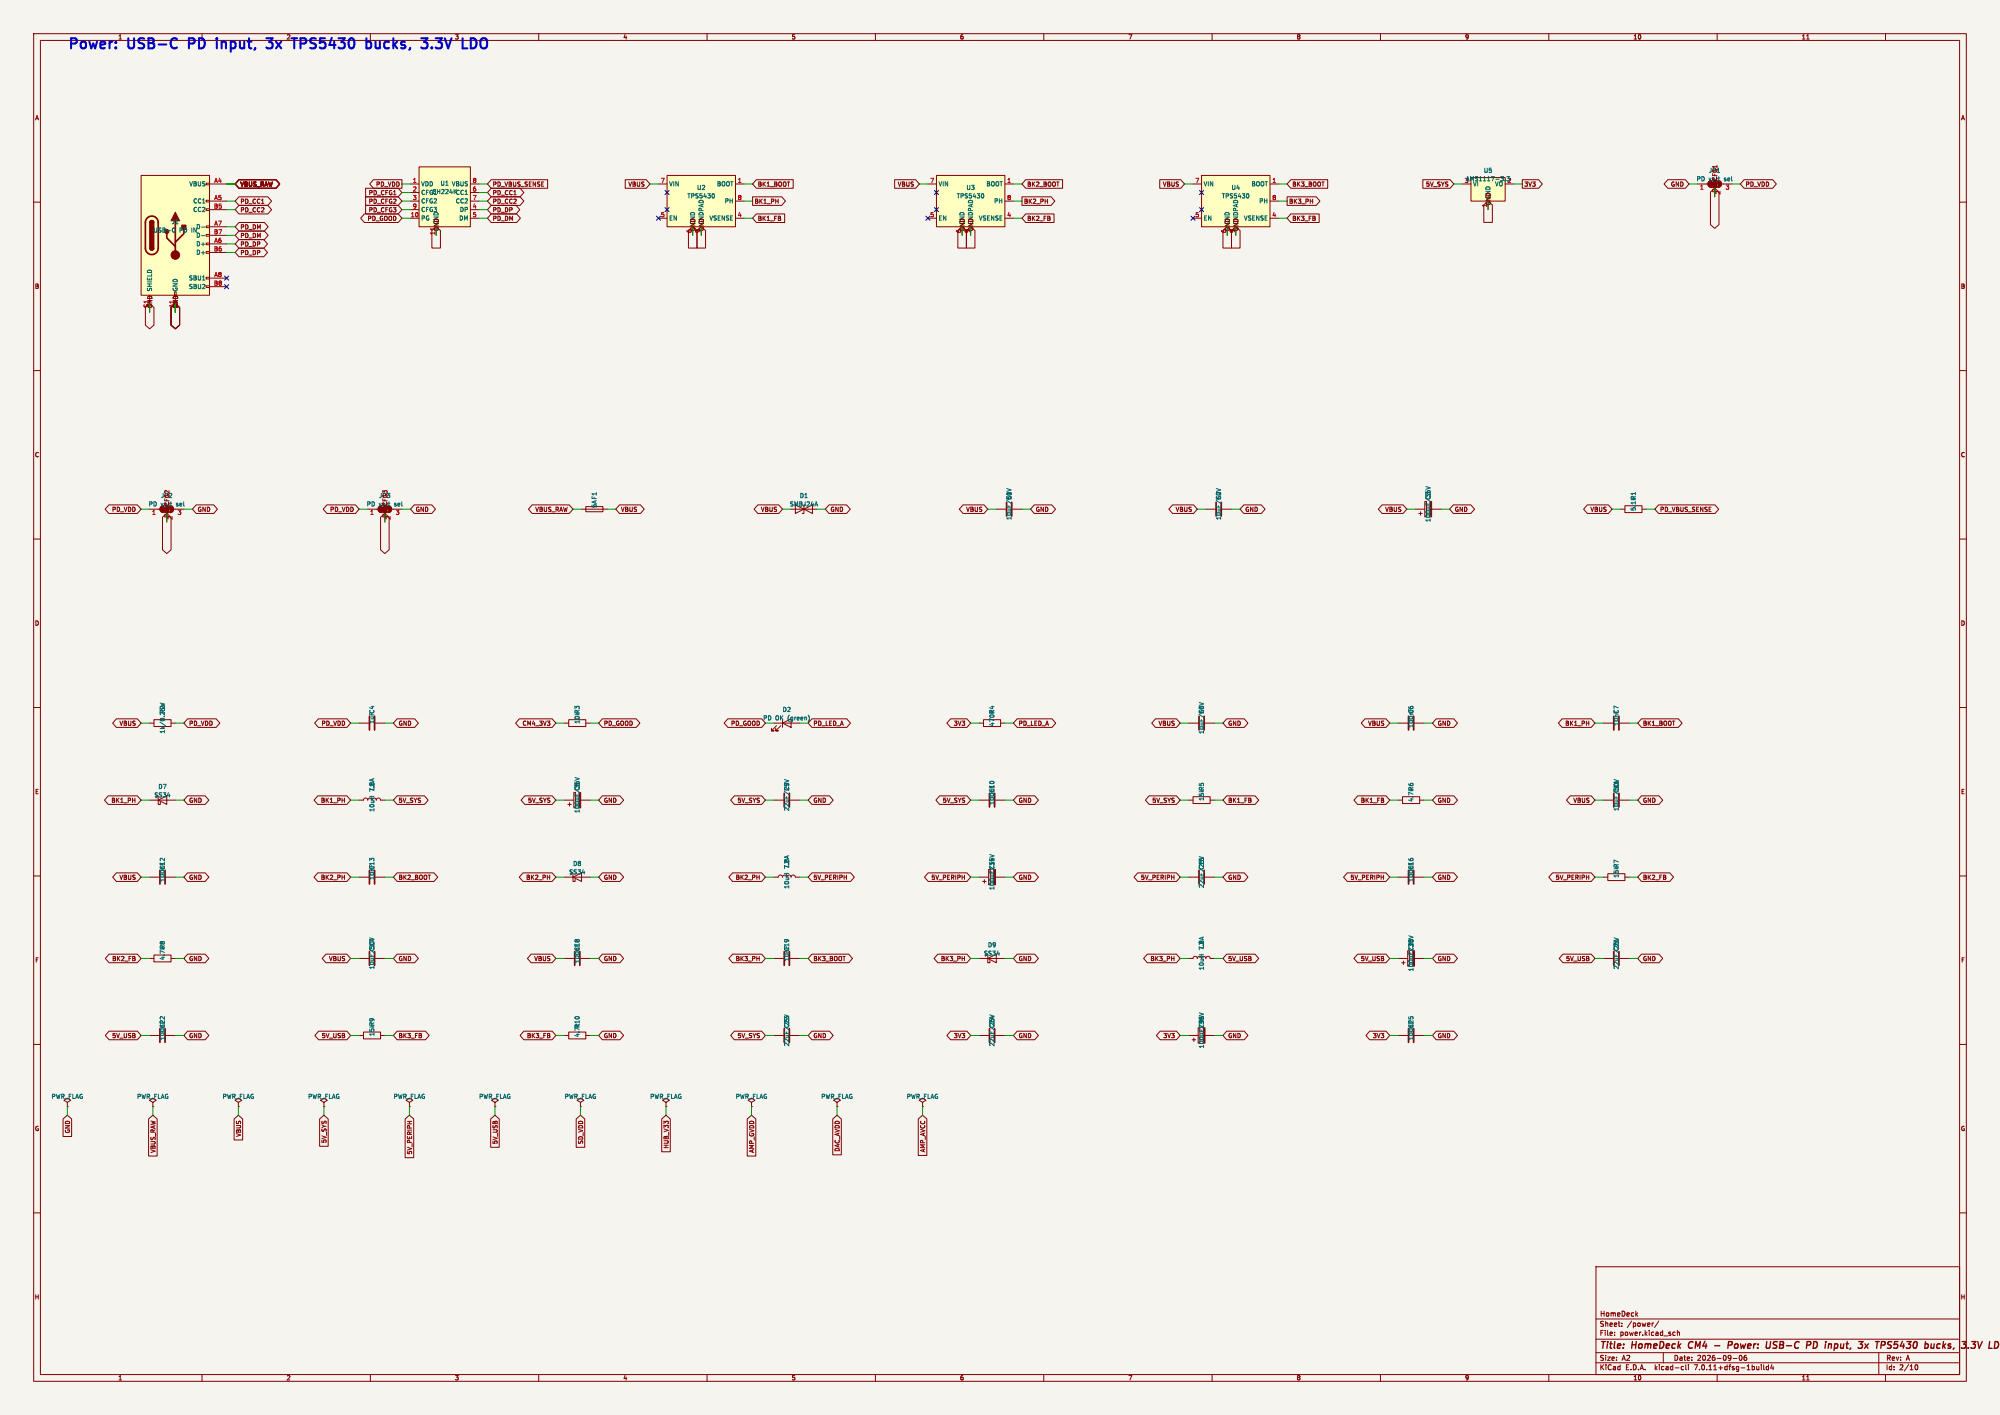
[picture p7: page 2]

JP1 PD volt sel GND

File: power.kicad_sch Sheet: /power/ HomeDeck C11 10uF/50VC8 100uF/35V

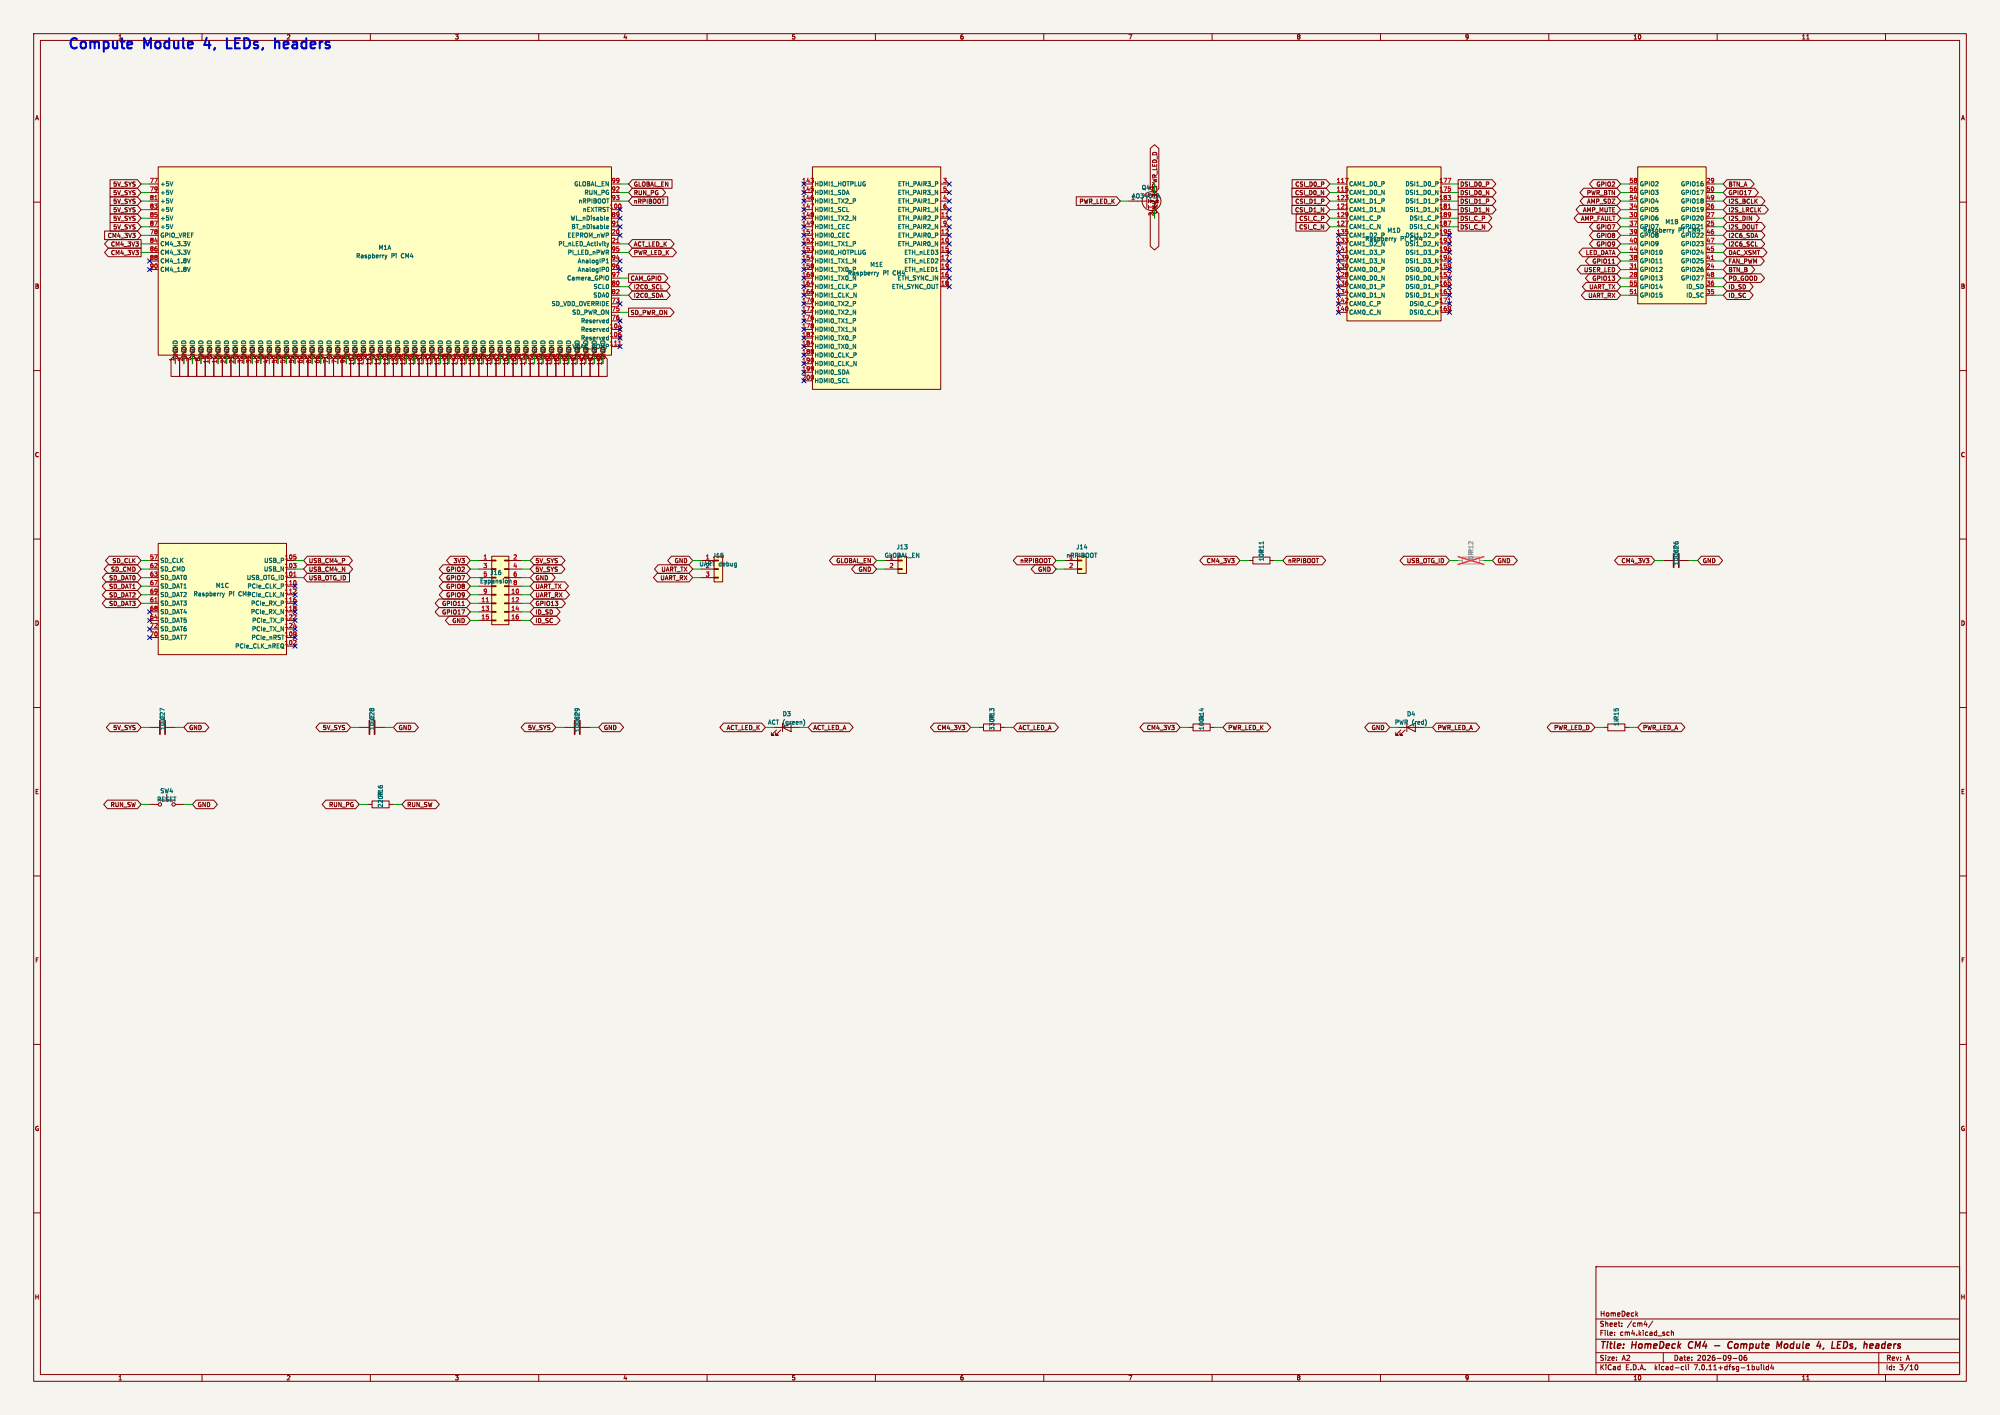
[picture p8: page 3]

CM4_3V3 Compute Module 4, LEDs, headers

7 GND 71 SD_VDD_OVERRIDE 73 GND 74 SD_PWR_ON 75 Reserved 76 +5V 77 GPIO_VREF 78 +5V 79 GND

2 EEPROM_nWP 20 Pi_nLED_Activity 21 GND 22 GND 23 GND 32 GND 33 GND 42 GND 43 GND 52 GND 53 GND 59 GND 60 GND 65 GND 66 GND

nRPIBOOT GND GND GND

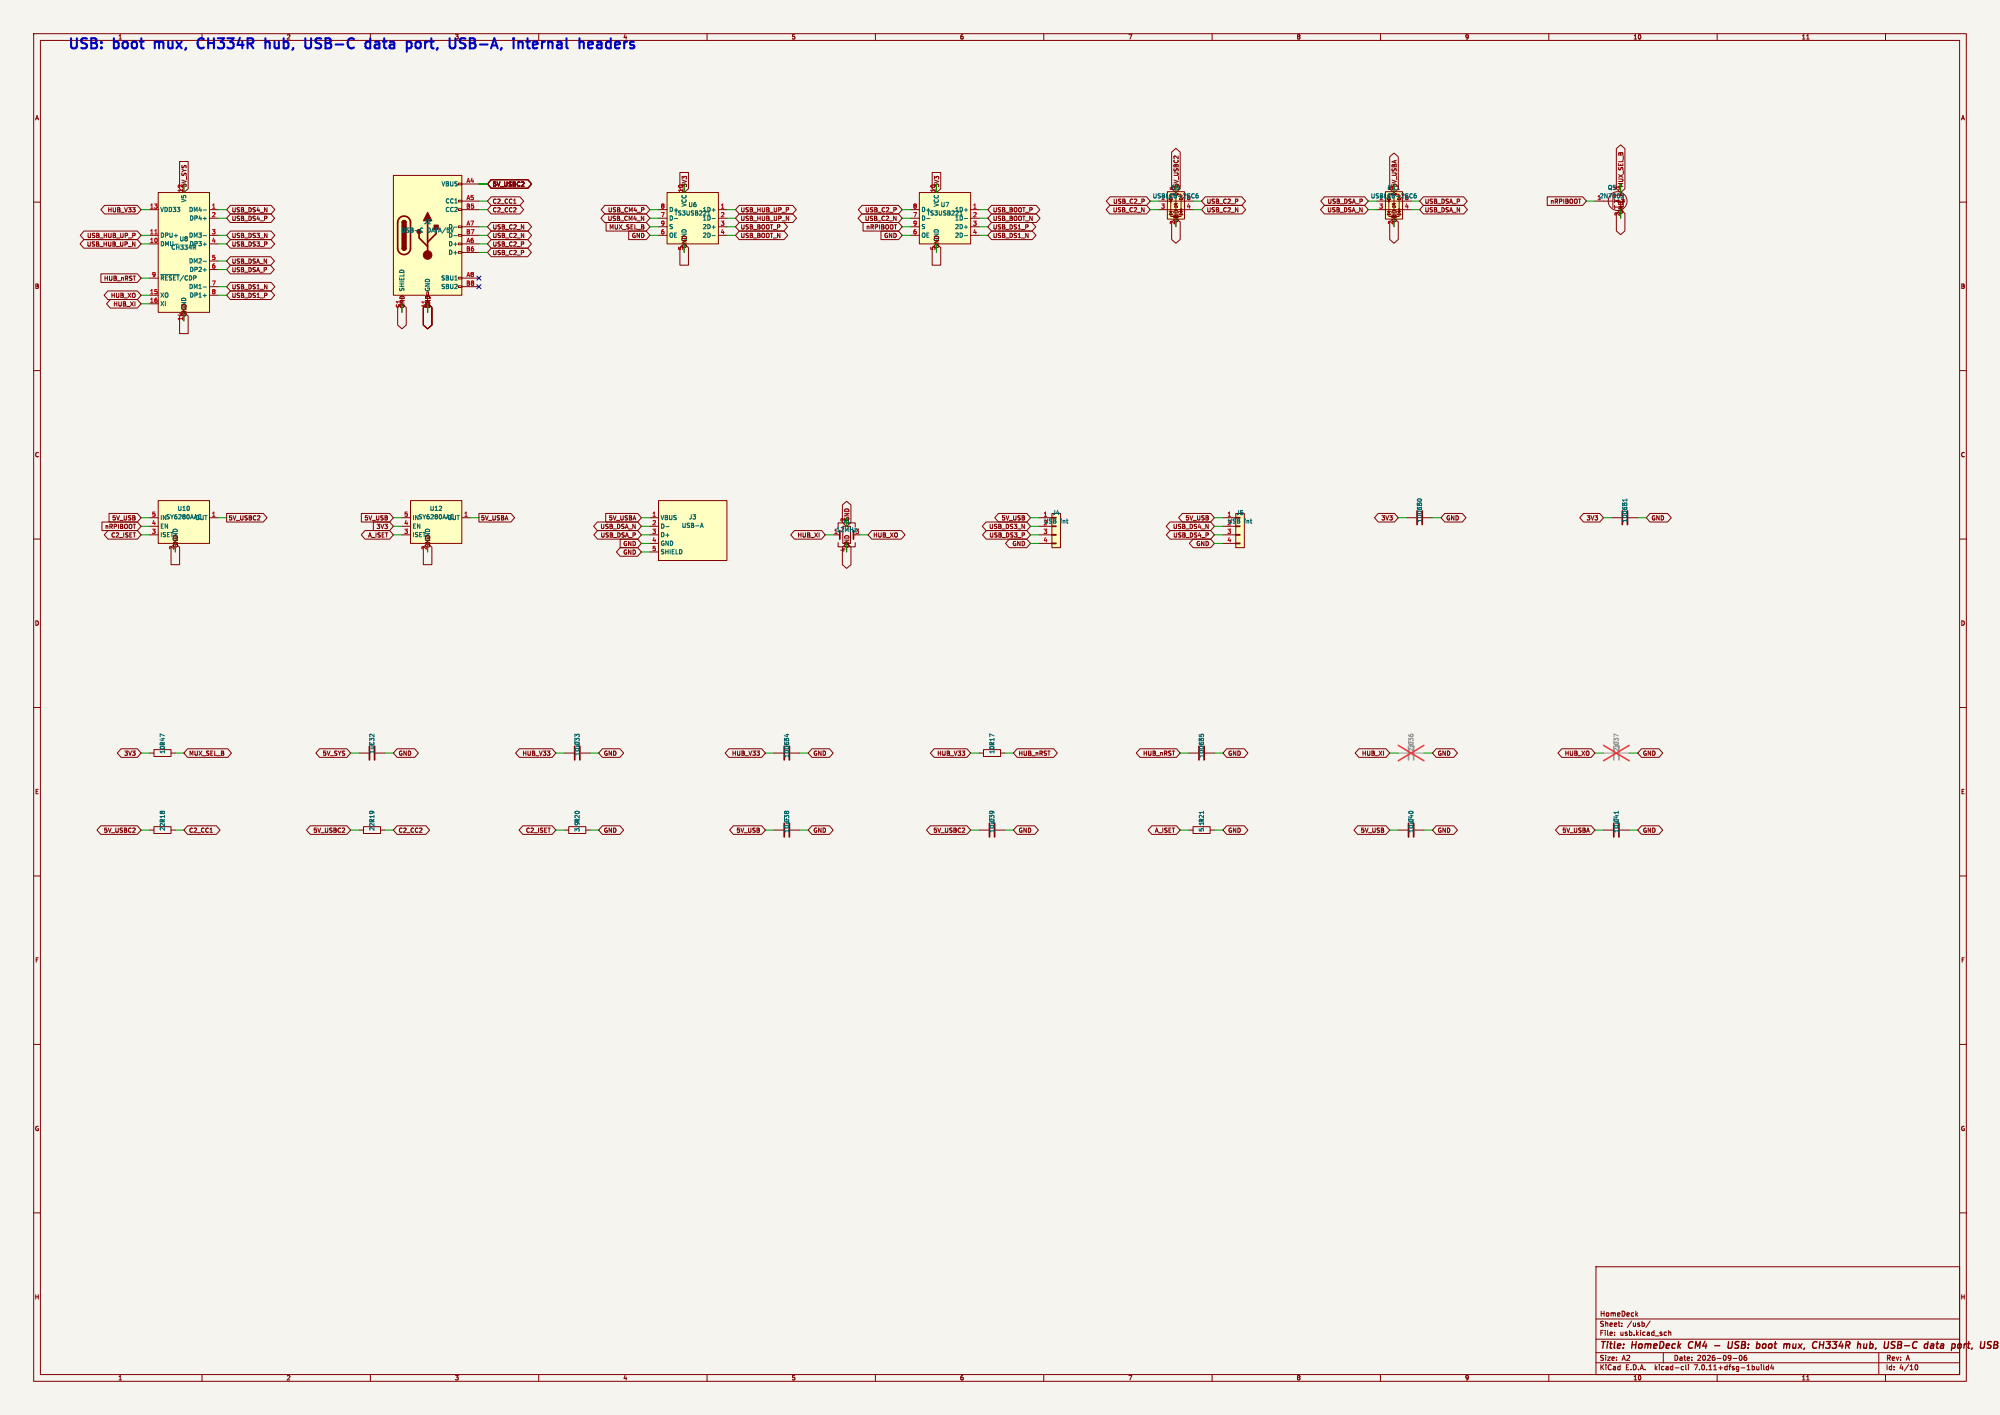
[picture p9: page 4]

File: usb.kicad_sch Sheet: /usb/ HomeDeck C30 100nF C33 10uF

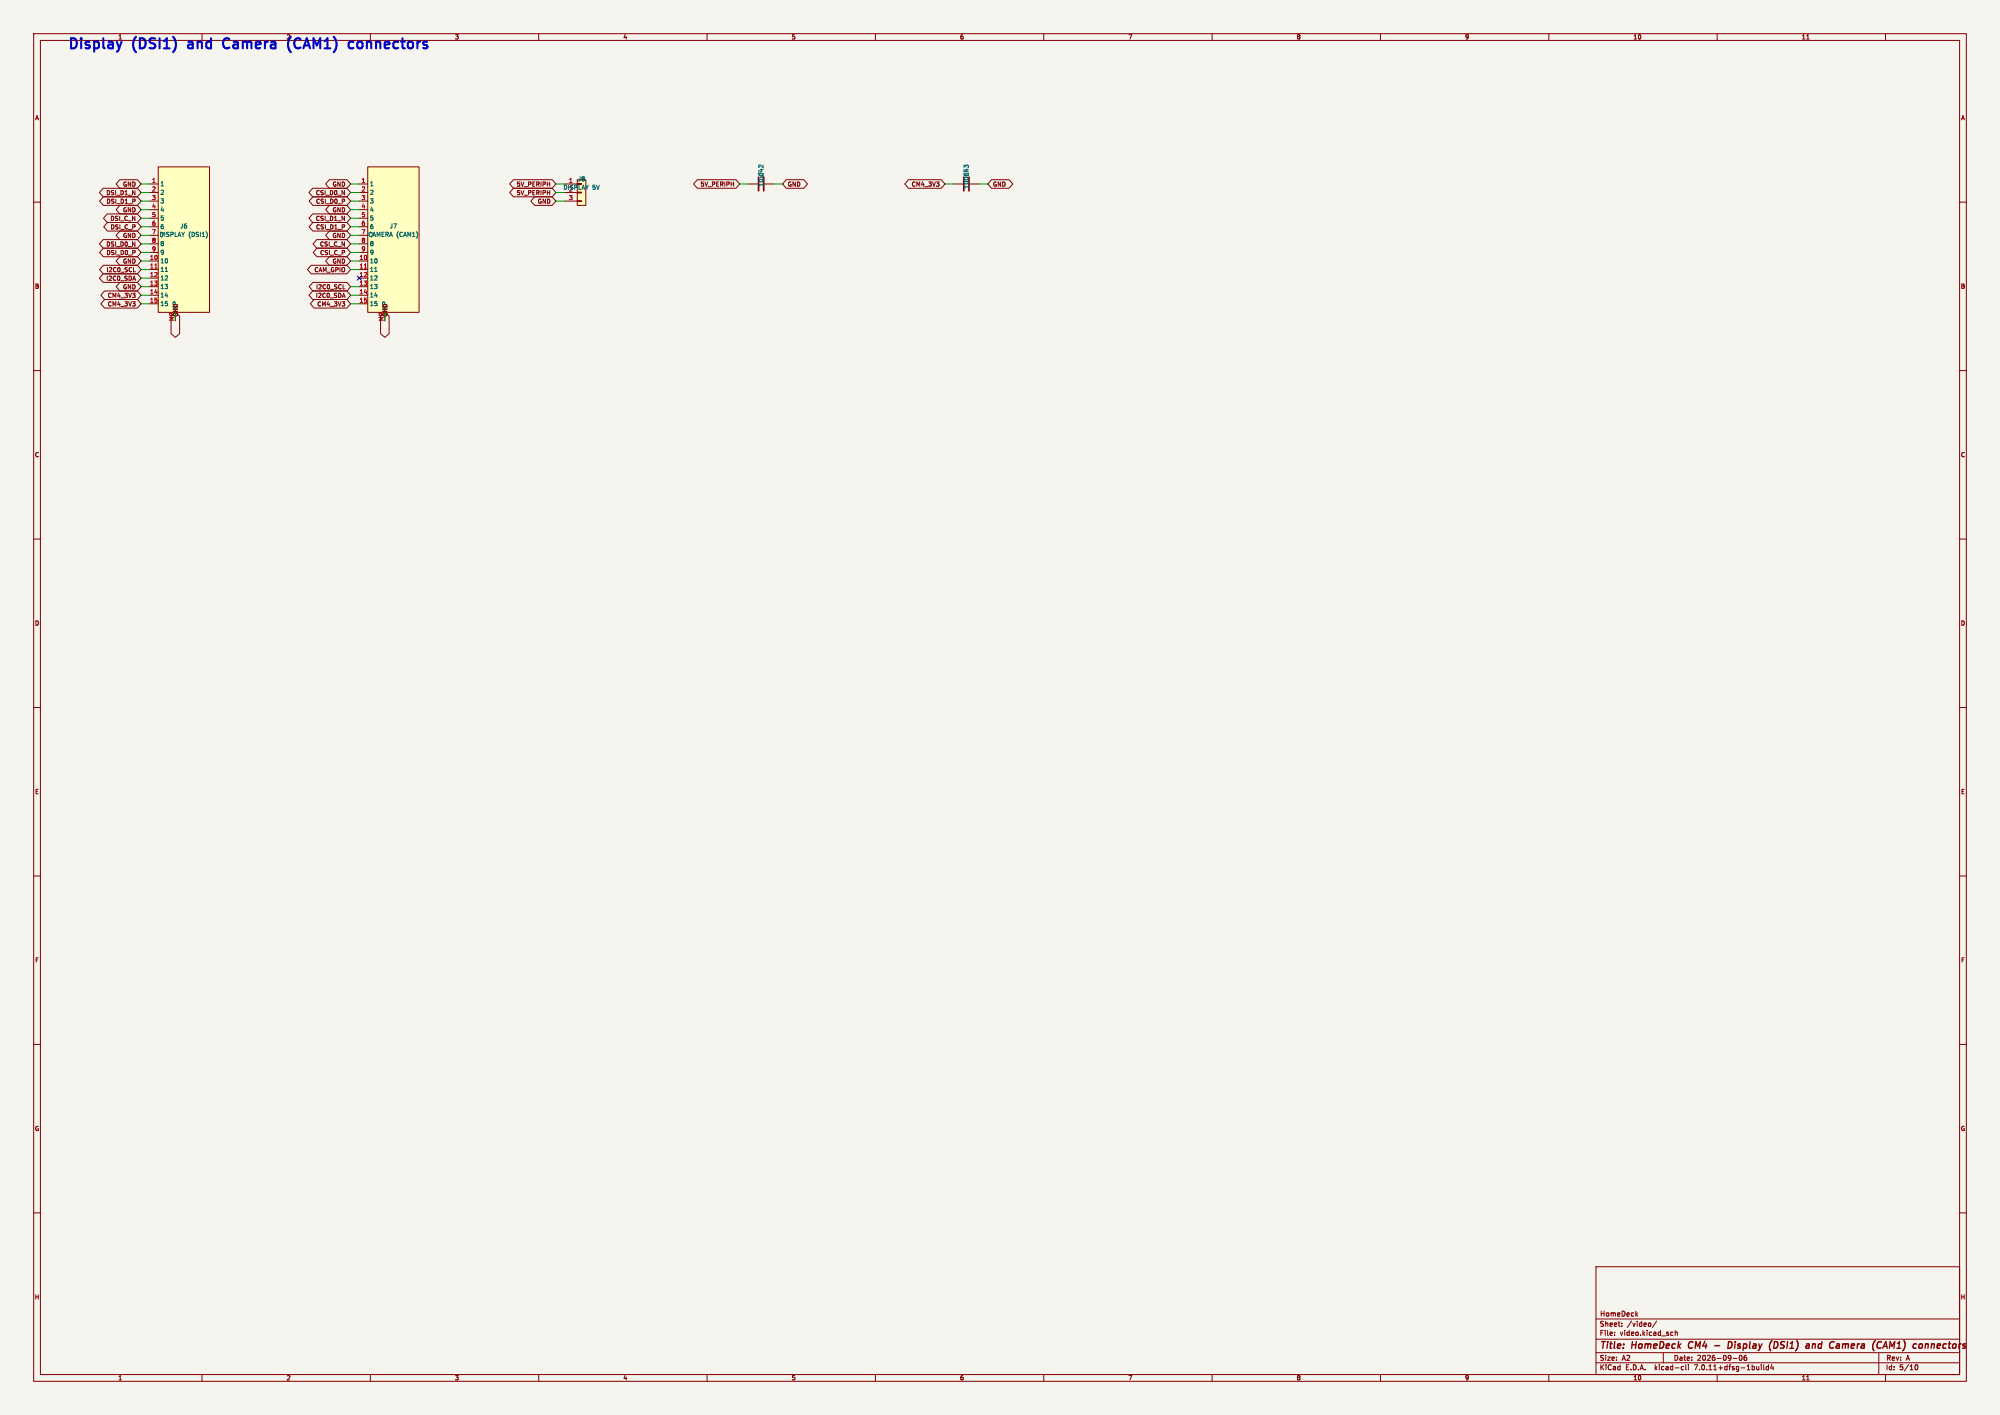
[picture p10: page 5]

File: video.kicad_sch Sheet: /video/ HomeDeck C43 100nFC42 10uF 1

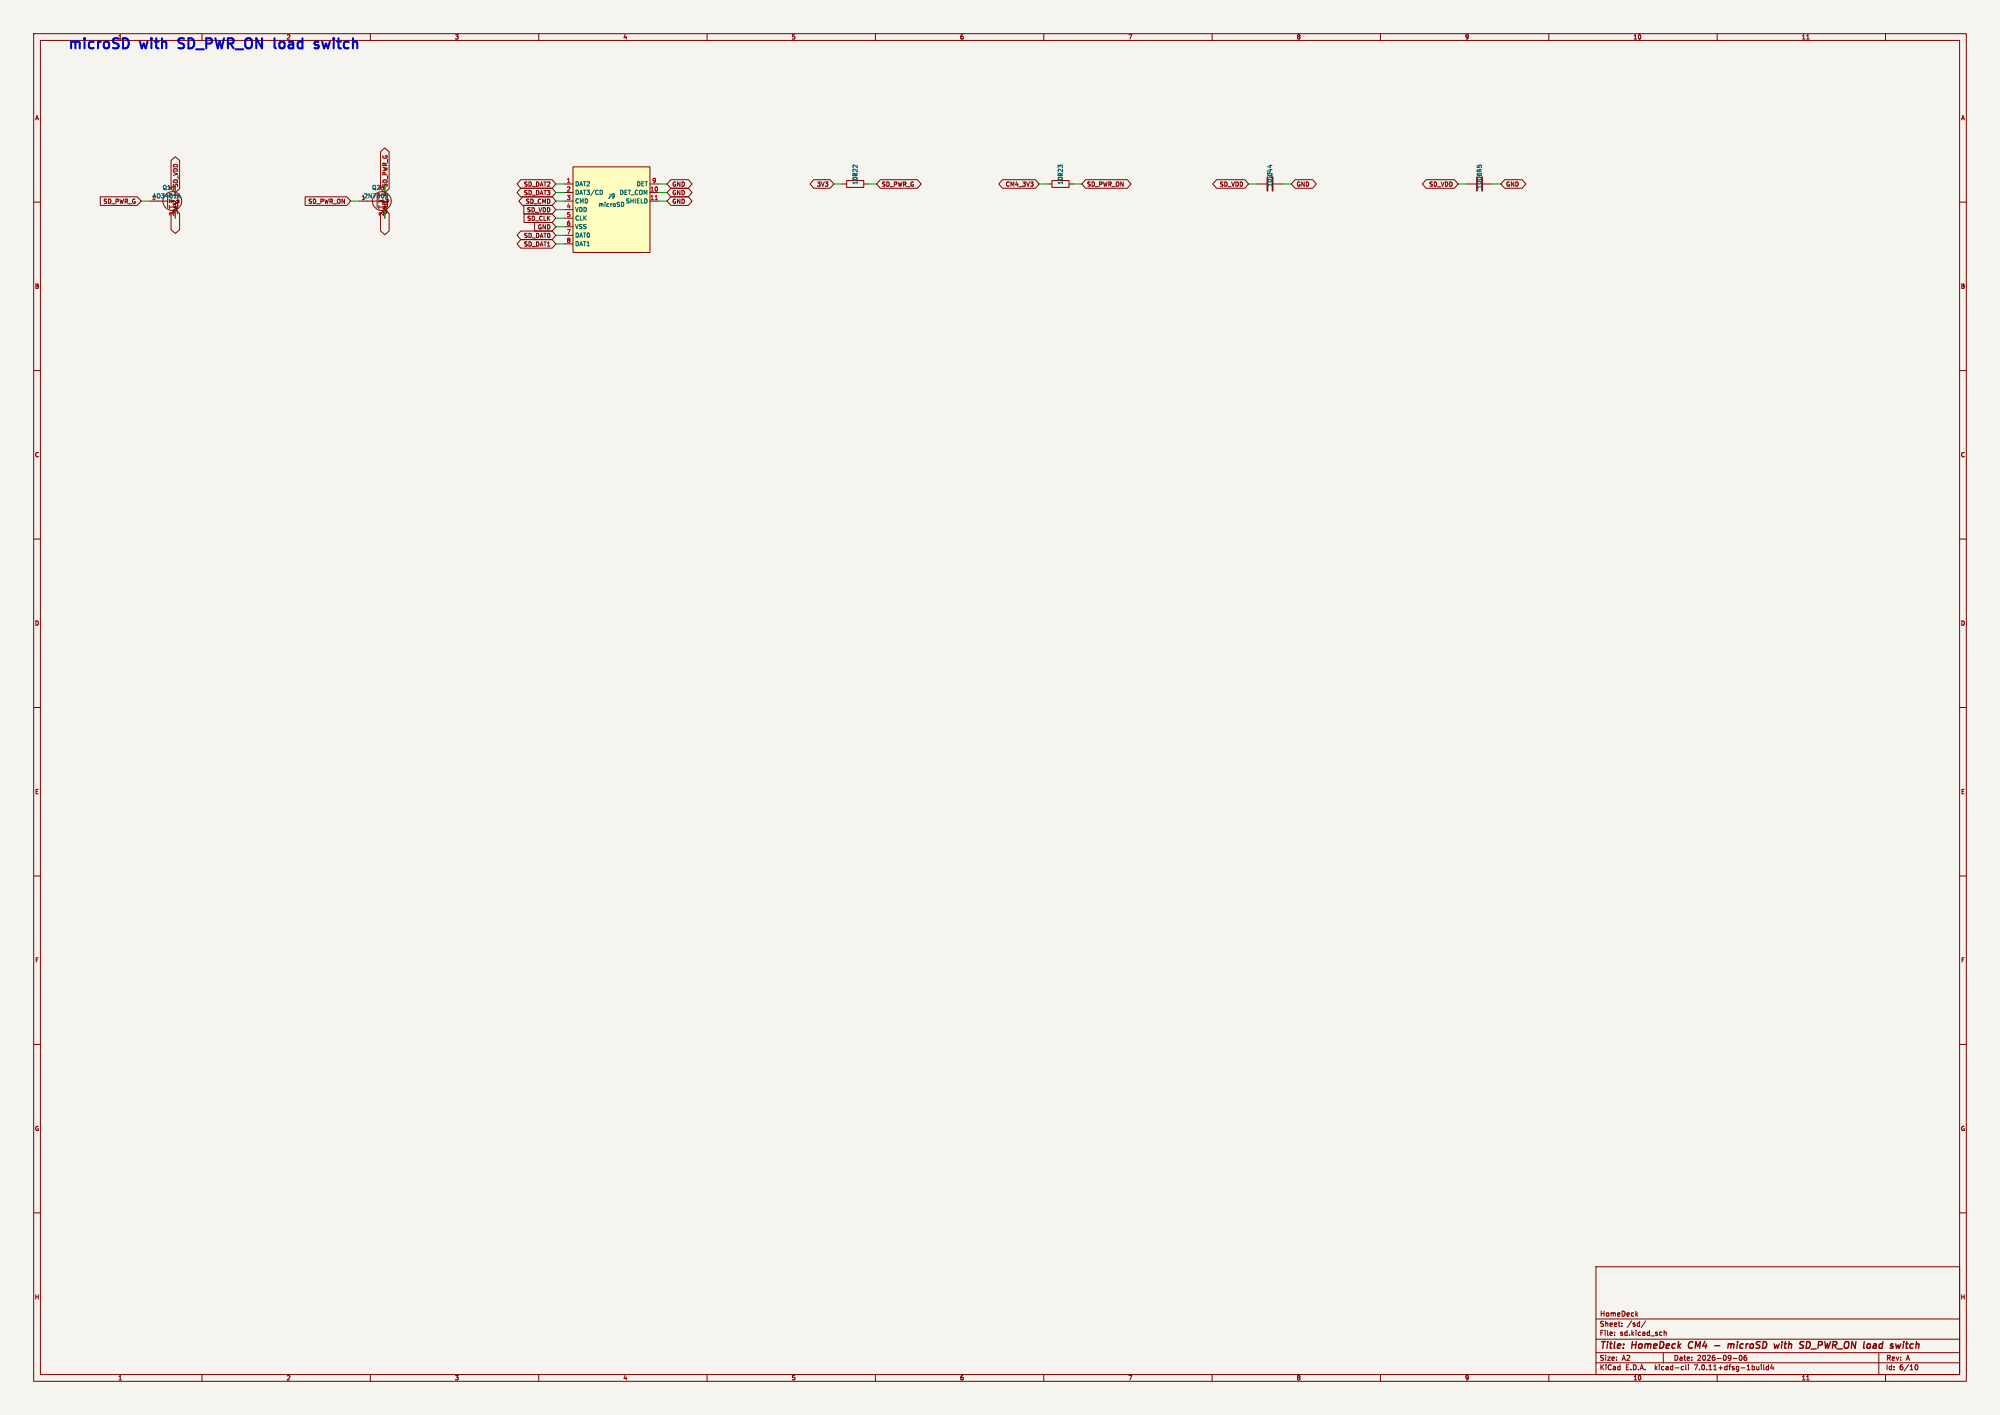
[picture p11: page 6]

File: sd.kicad_sch Sheet: /sd/ HomeDeck C44 10uF

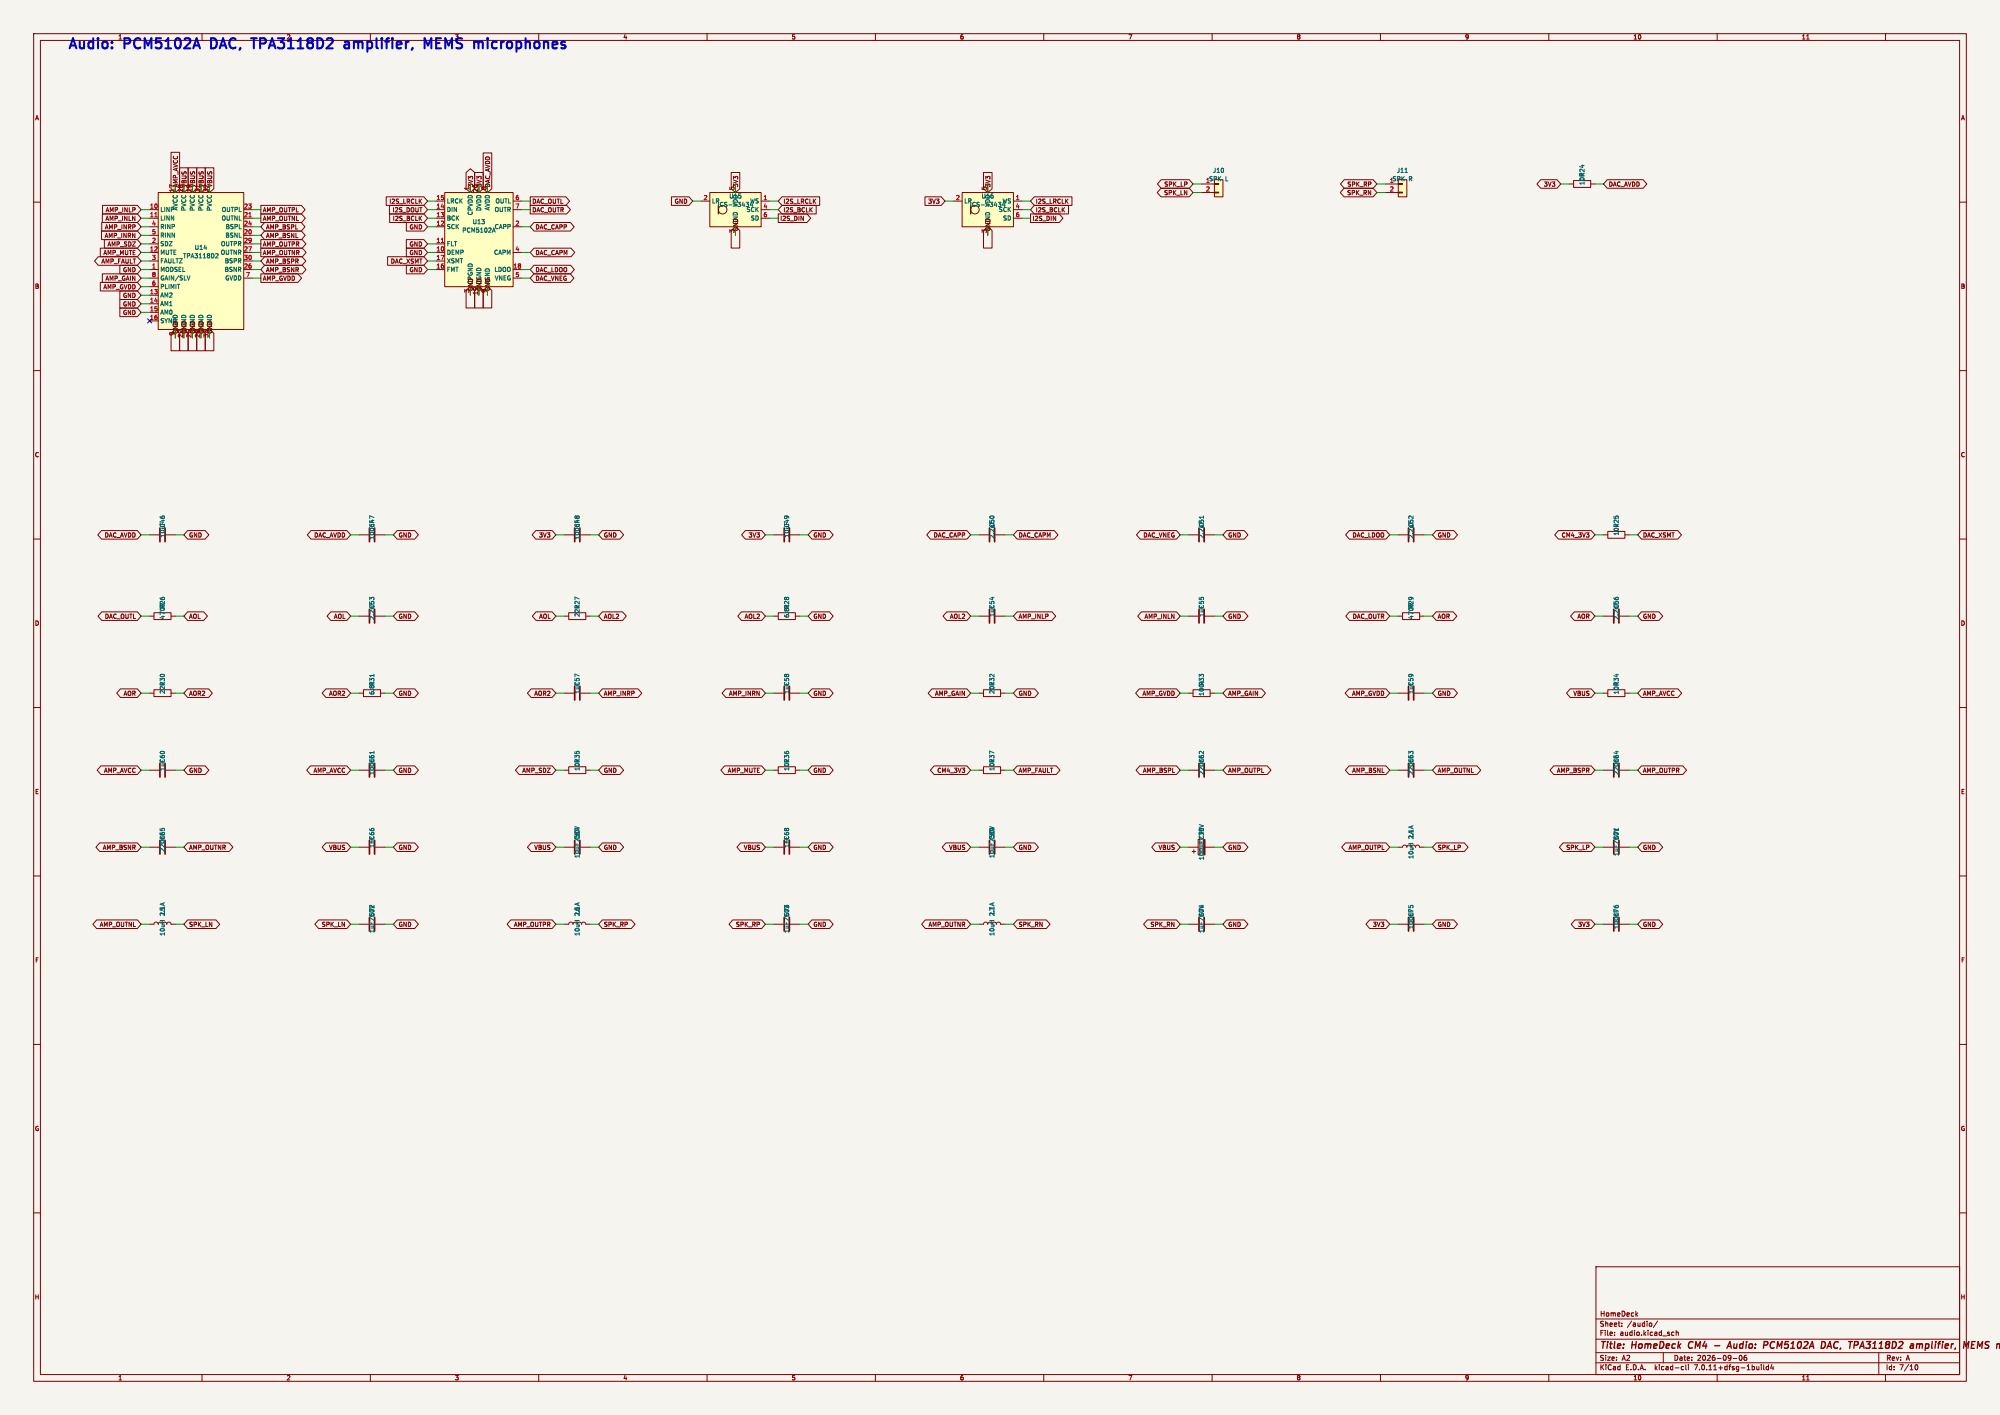
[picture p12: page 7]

1 DEMP 10 FLT 11 SCK 12 BCK 13 DIN 14

3 CAPM 4 VNEG 5 OUTL 6 OUTR 7 AVDD

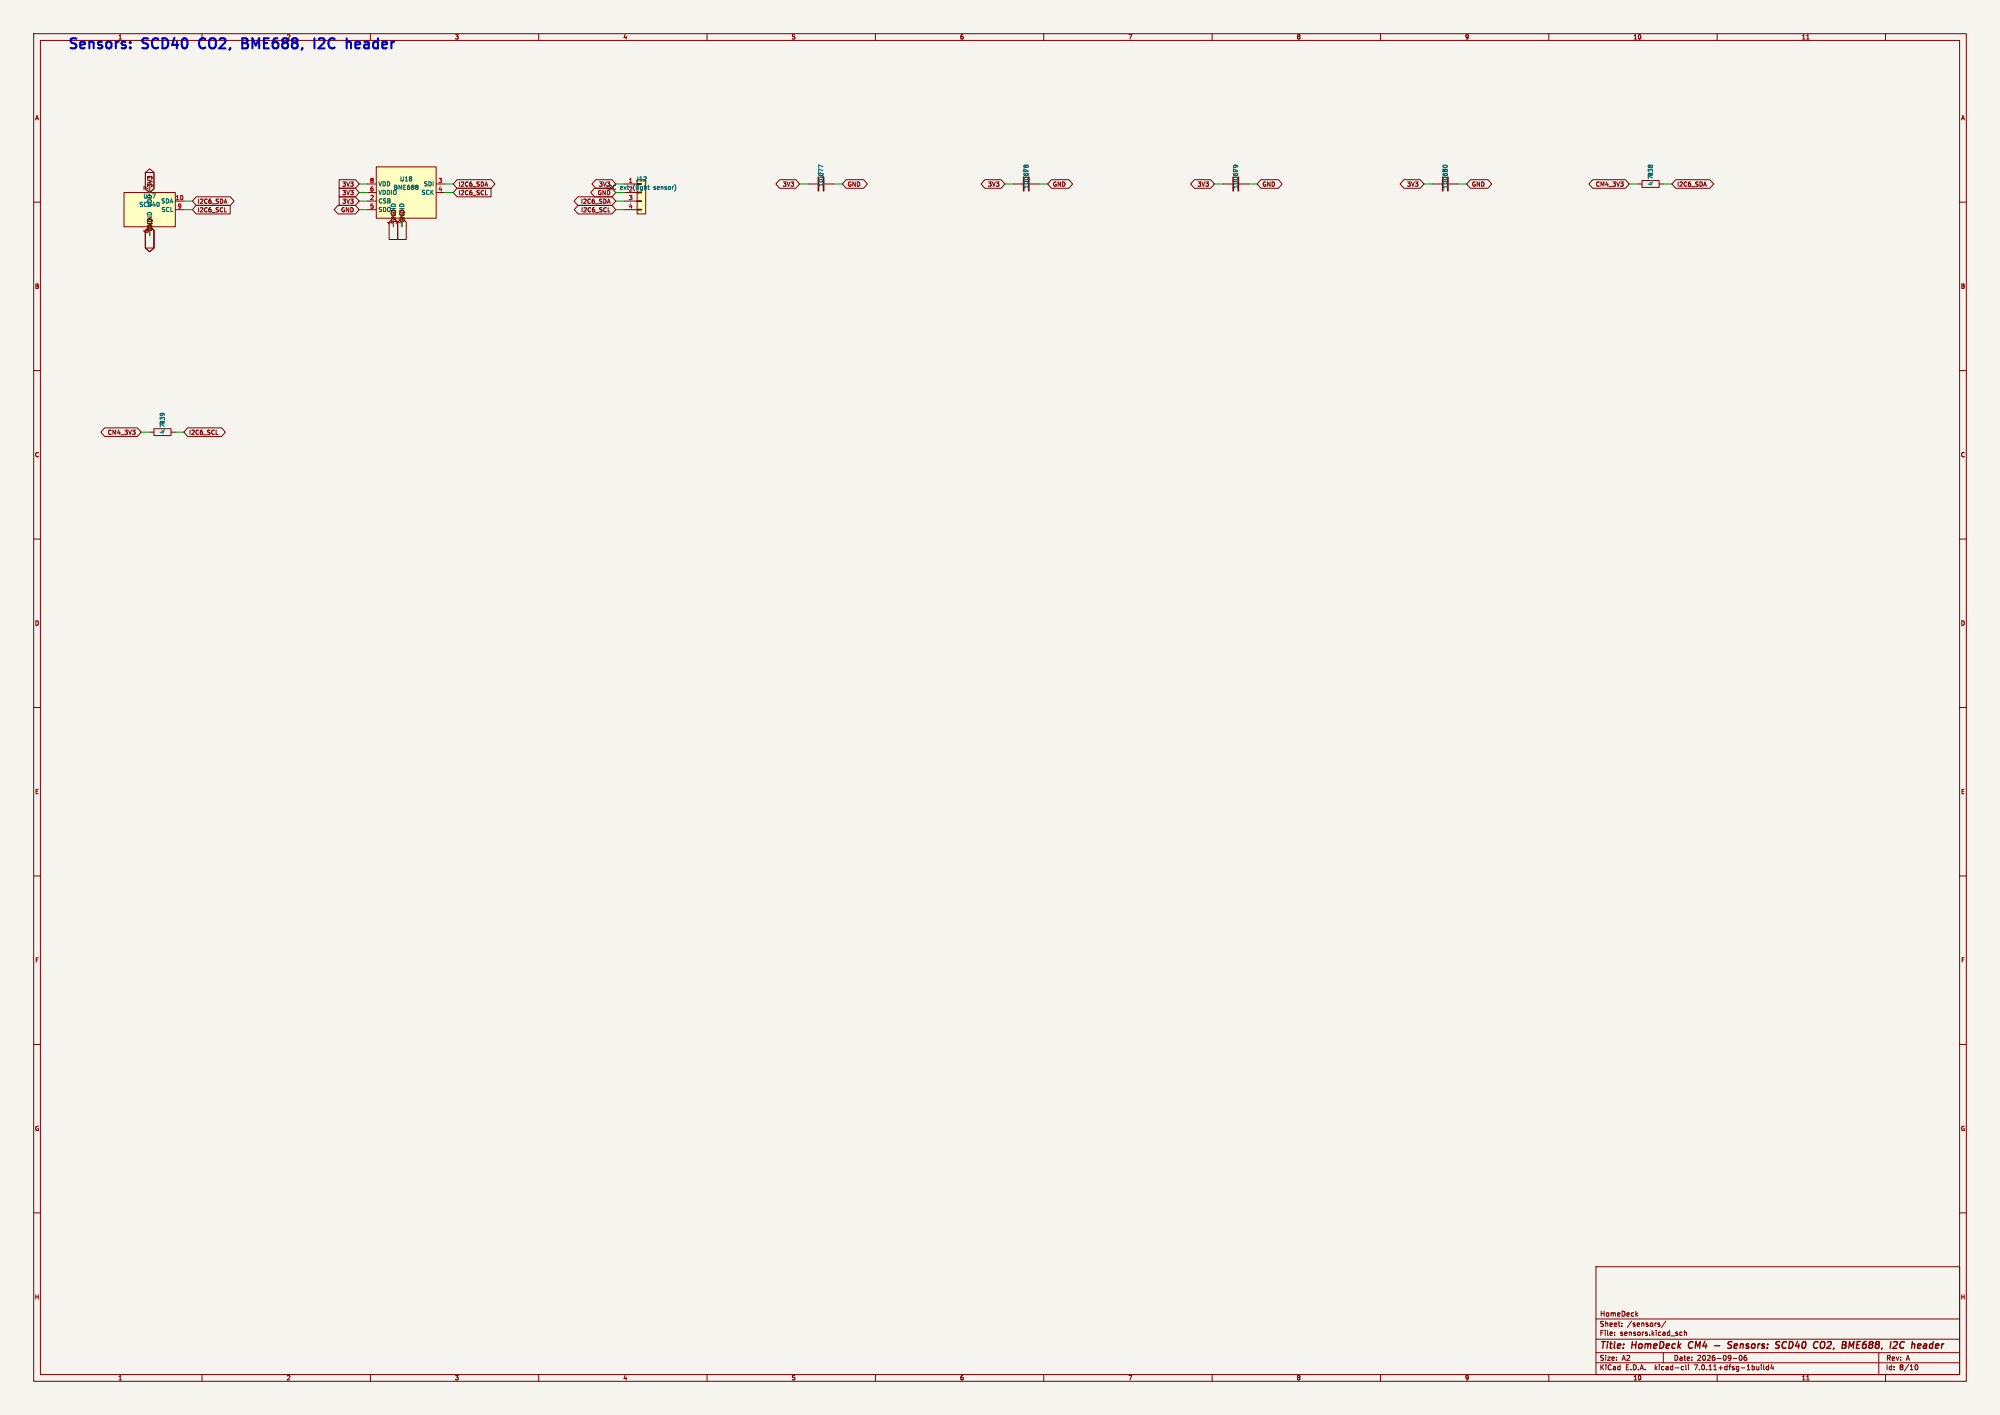
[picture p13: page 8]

1 CSB 2 SDI 3 SCK 4 SDO 5 VDDIO 6 GND

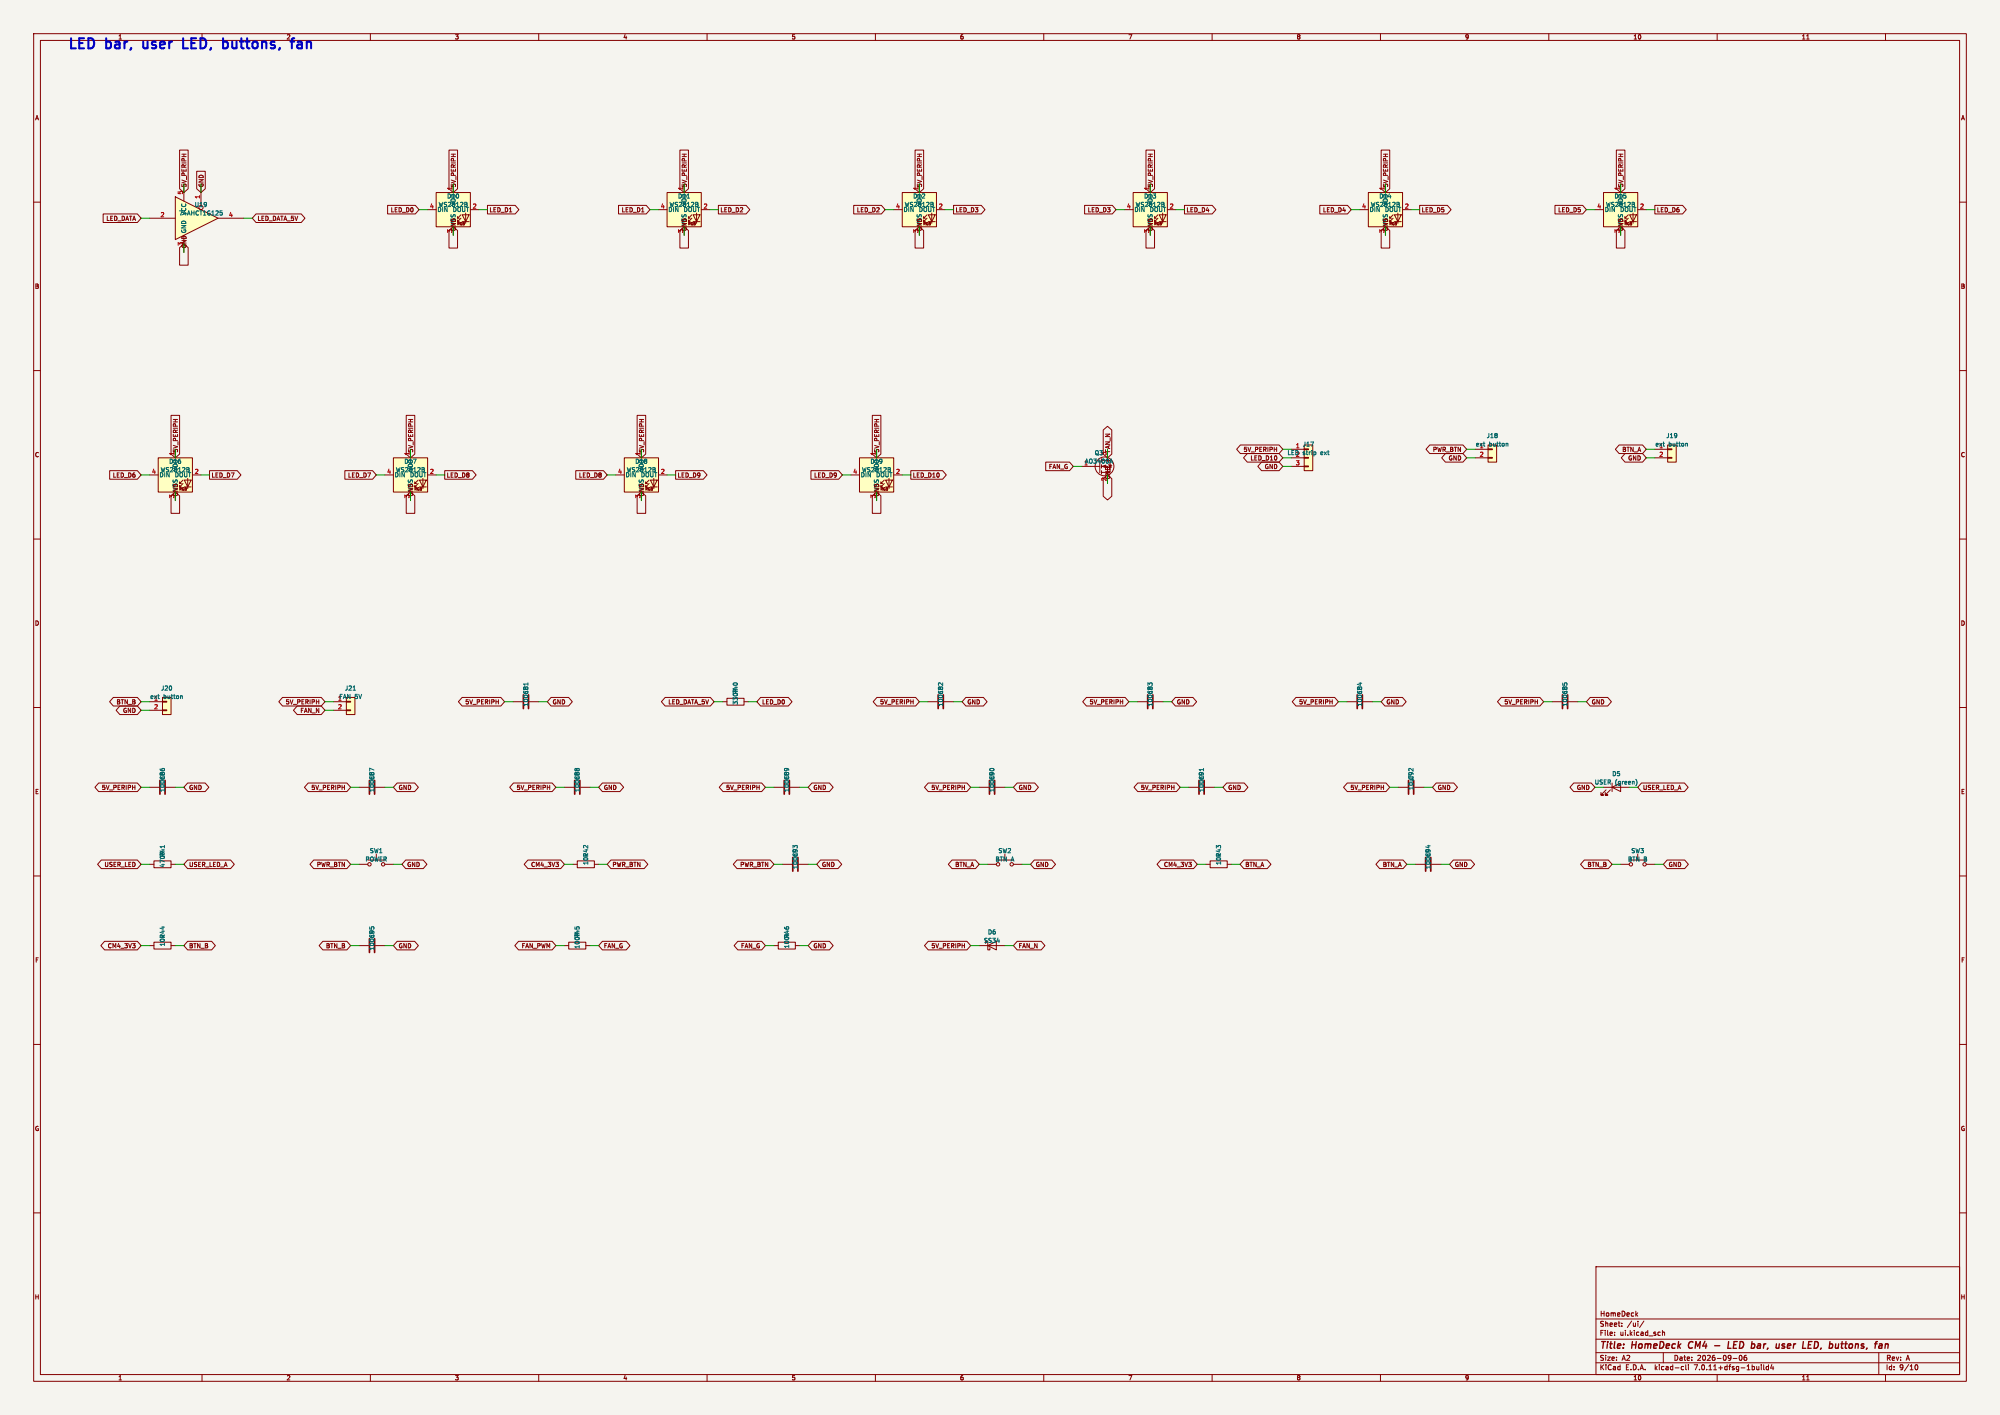
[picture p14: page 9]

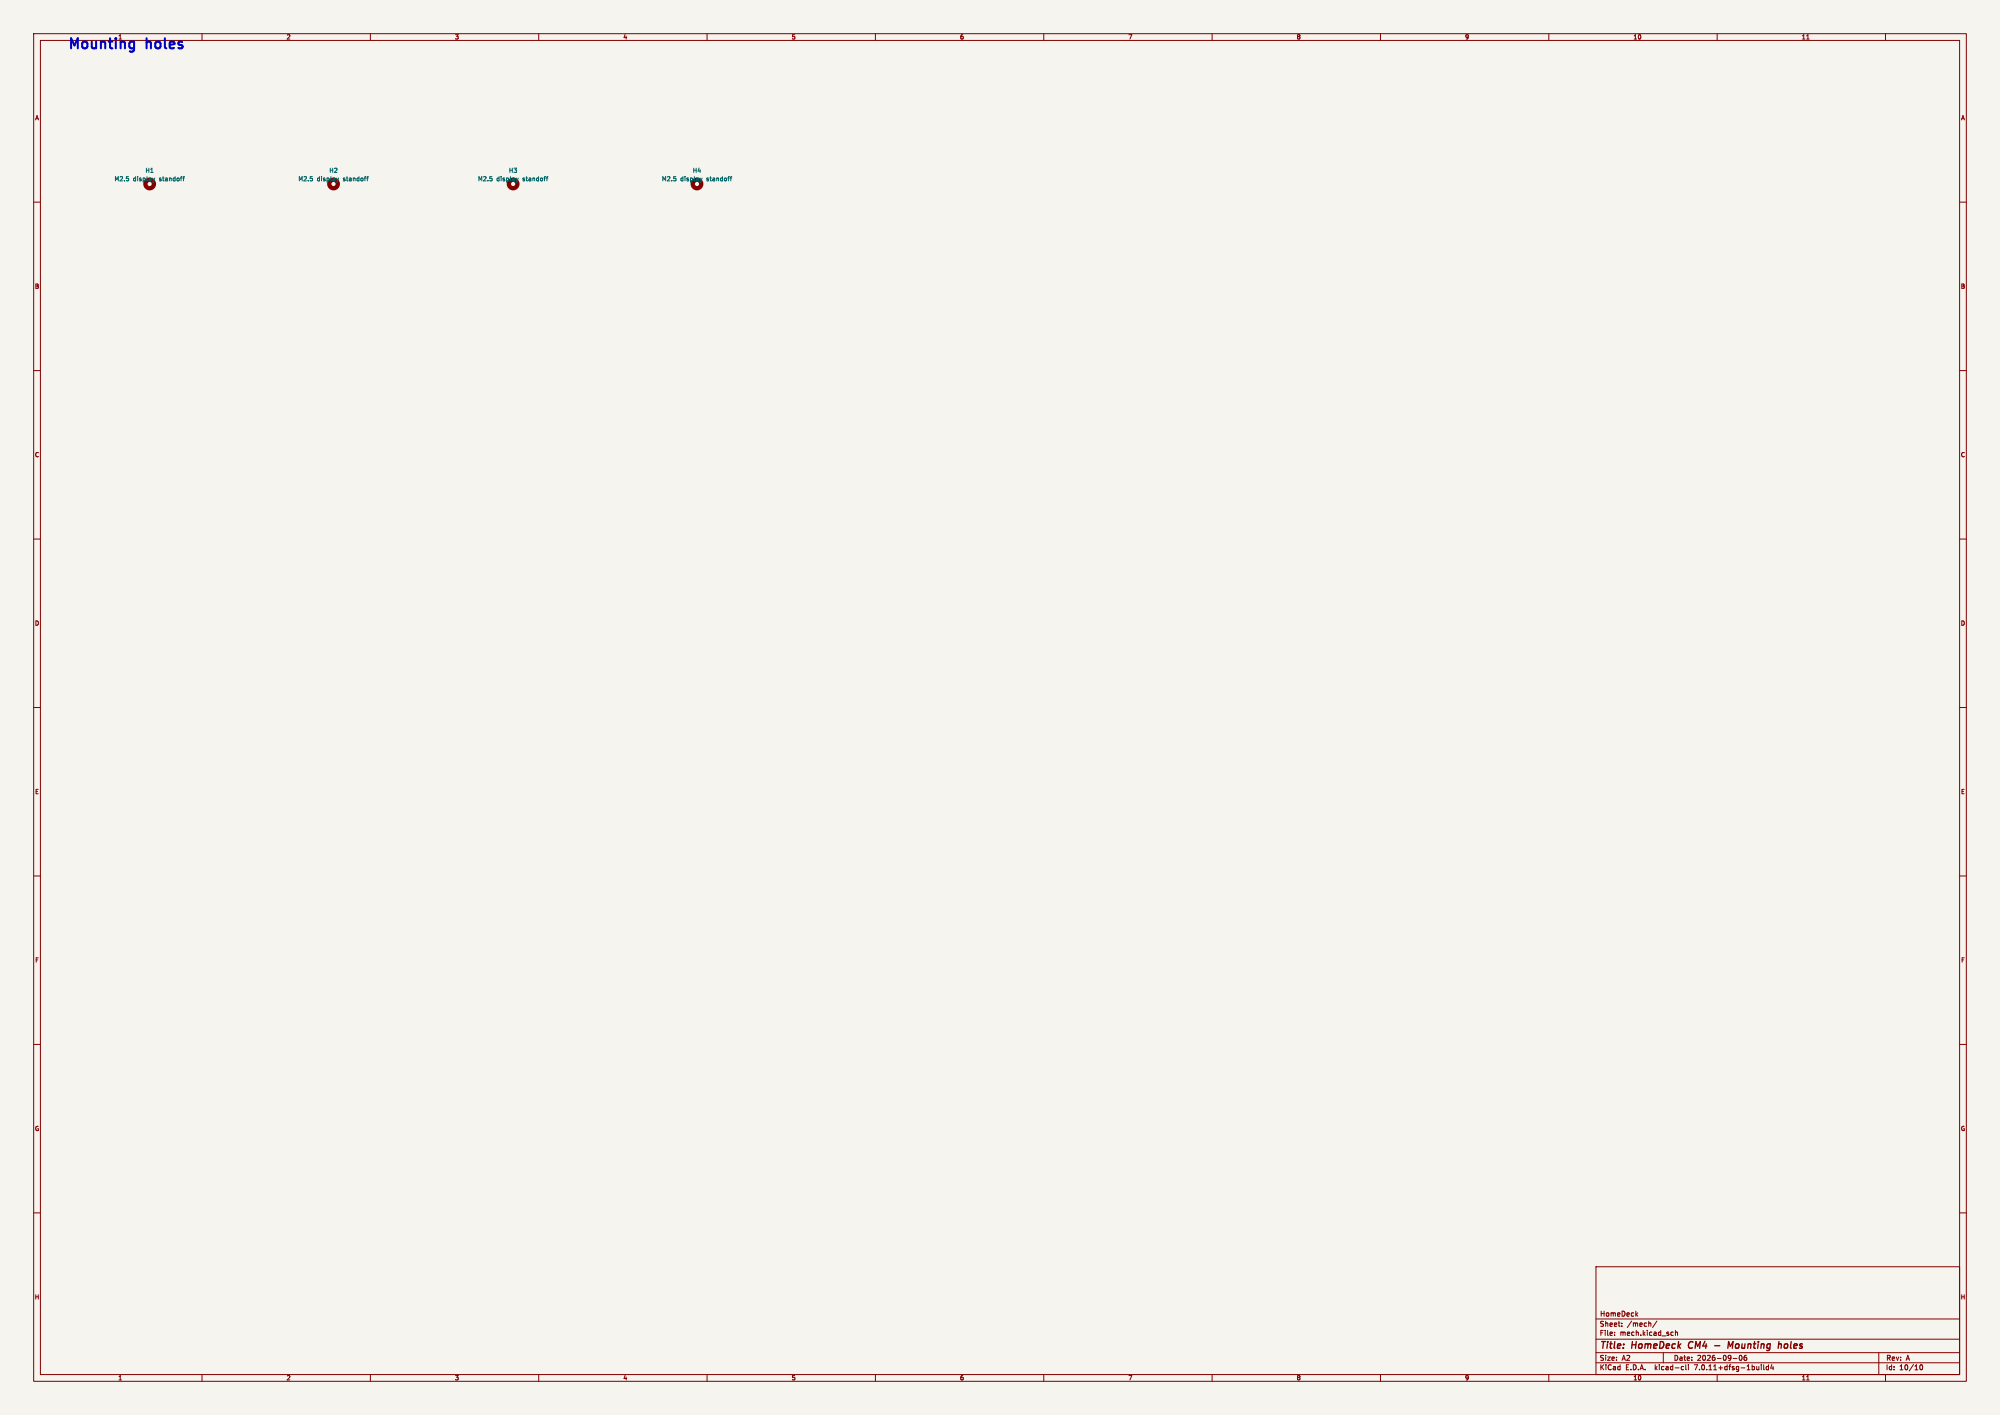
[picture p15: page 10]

File: mech.kicad_sch Sheet: /mech/ HomeDeck

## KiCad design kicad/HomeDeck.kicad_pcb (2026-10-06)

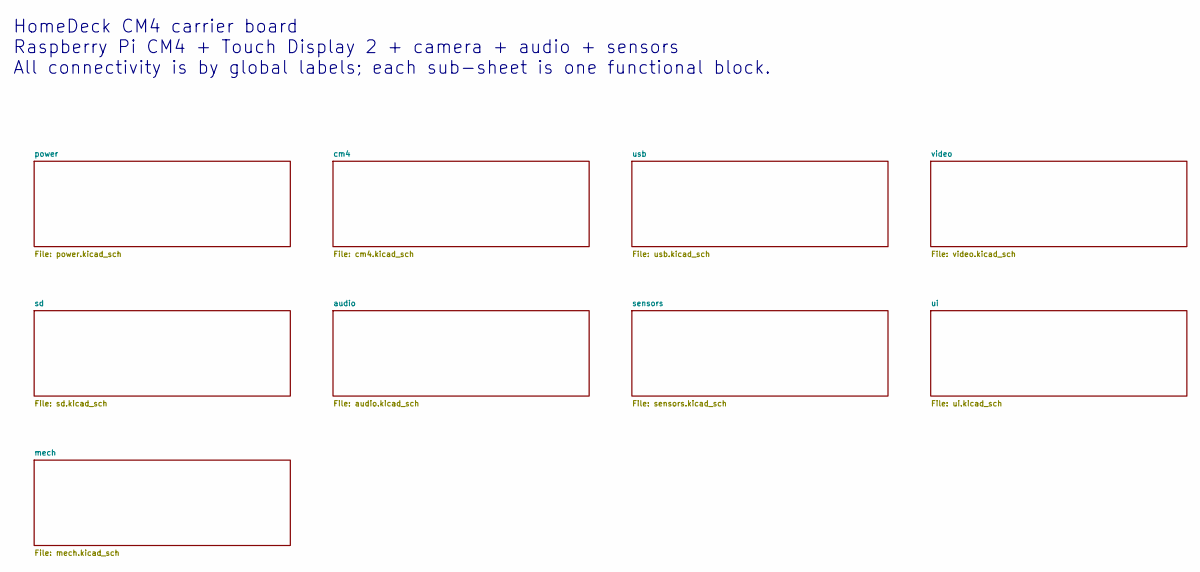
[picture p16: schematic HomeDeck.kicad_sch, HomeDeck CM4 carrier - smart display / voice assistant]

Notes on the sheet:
HomeDeck CM4 carrier board Raspberry Pi CM4 + Touch Display 2 + camera + audio + sensors All connectivity is by global labels; each sub-sheet is one functional block.

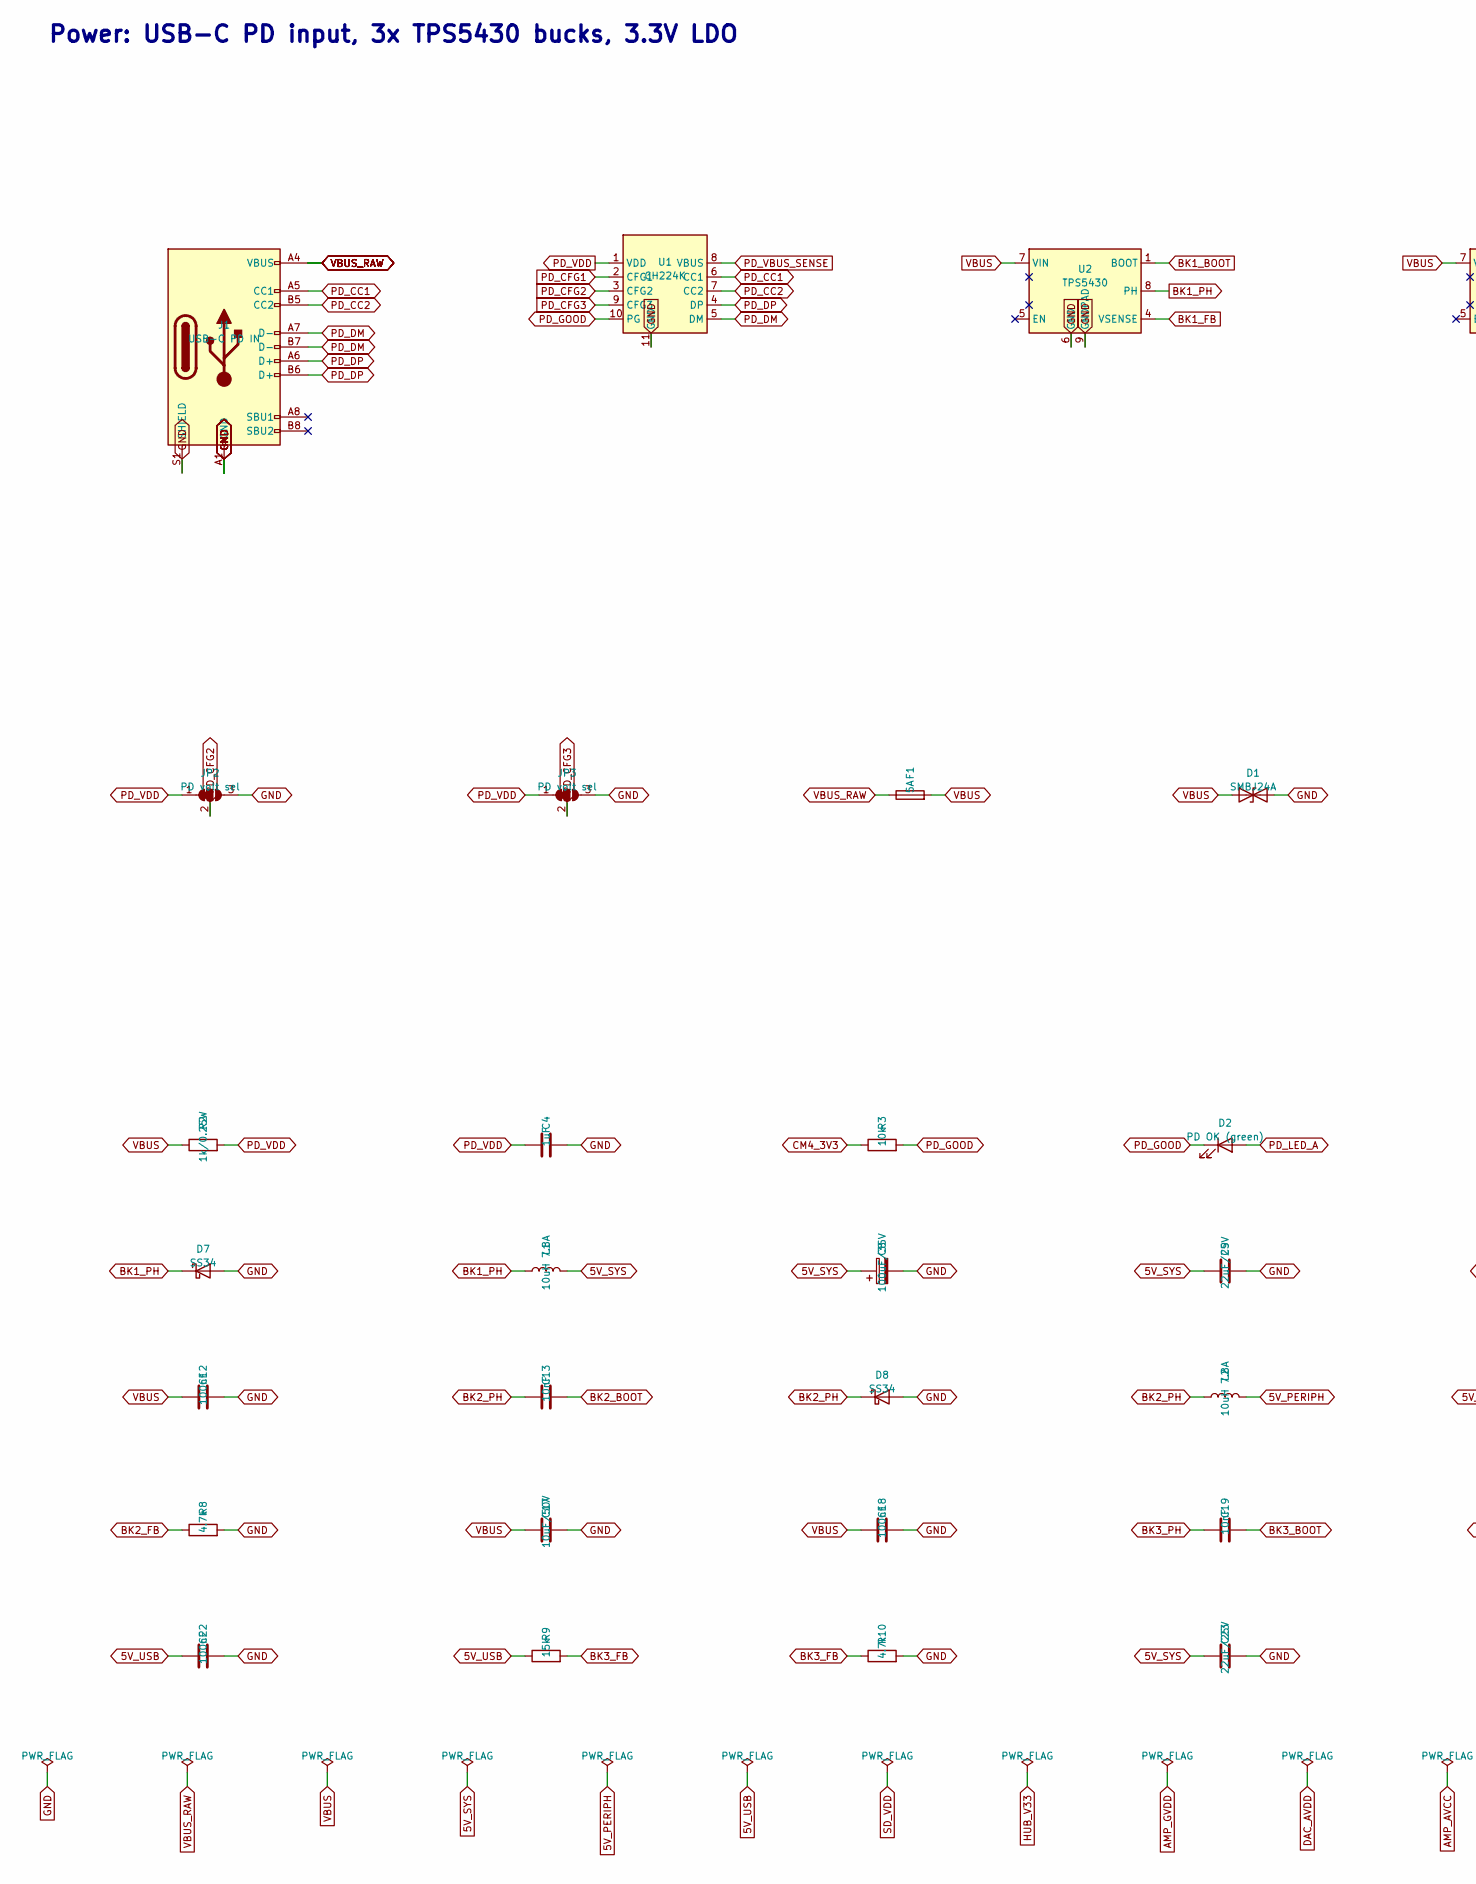
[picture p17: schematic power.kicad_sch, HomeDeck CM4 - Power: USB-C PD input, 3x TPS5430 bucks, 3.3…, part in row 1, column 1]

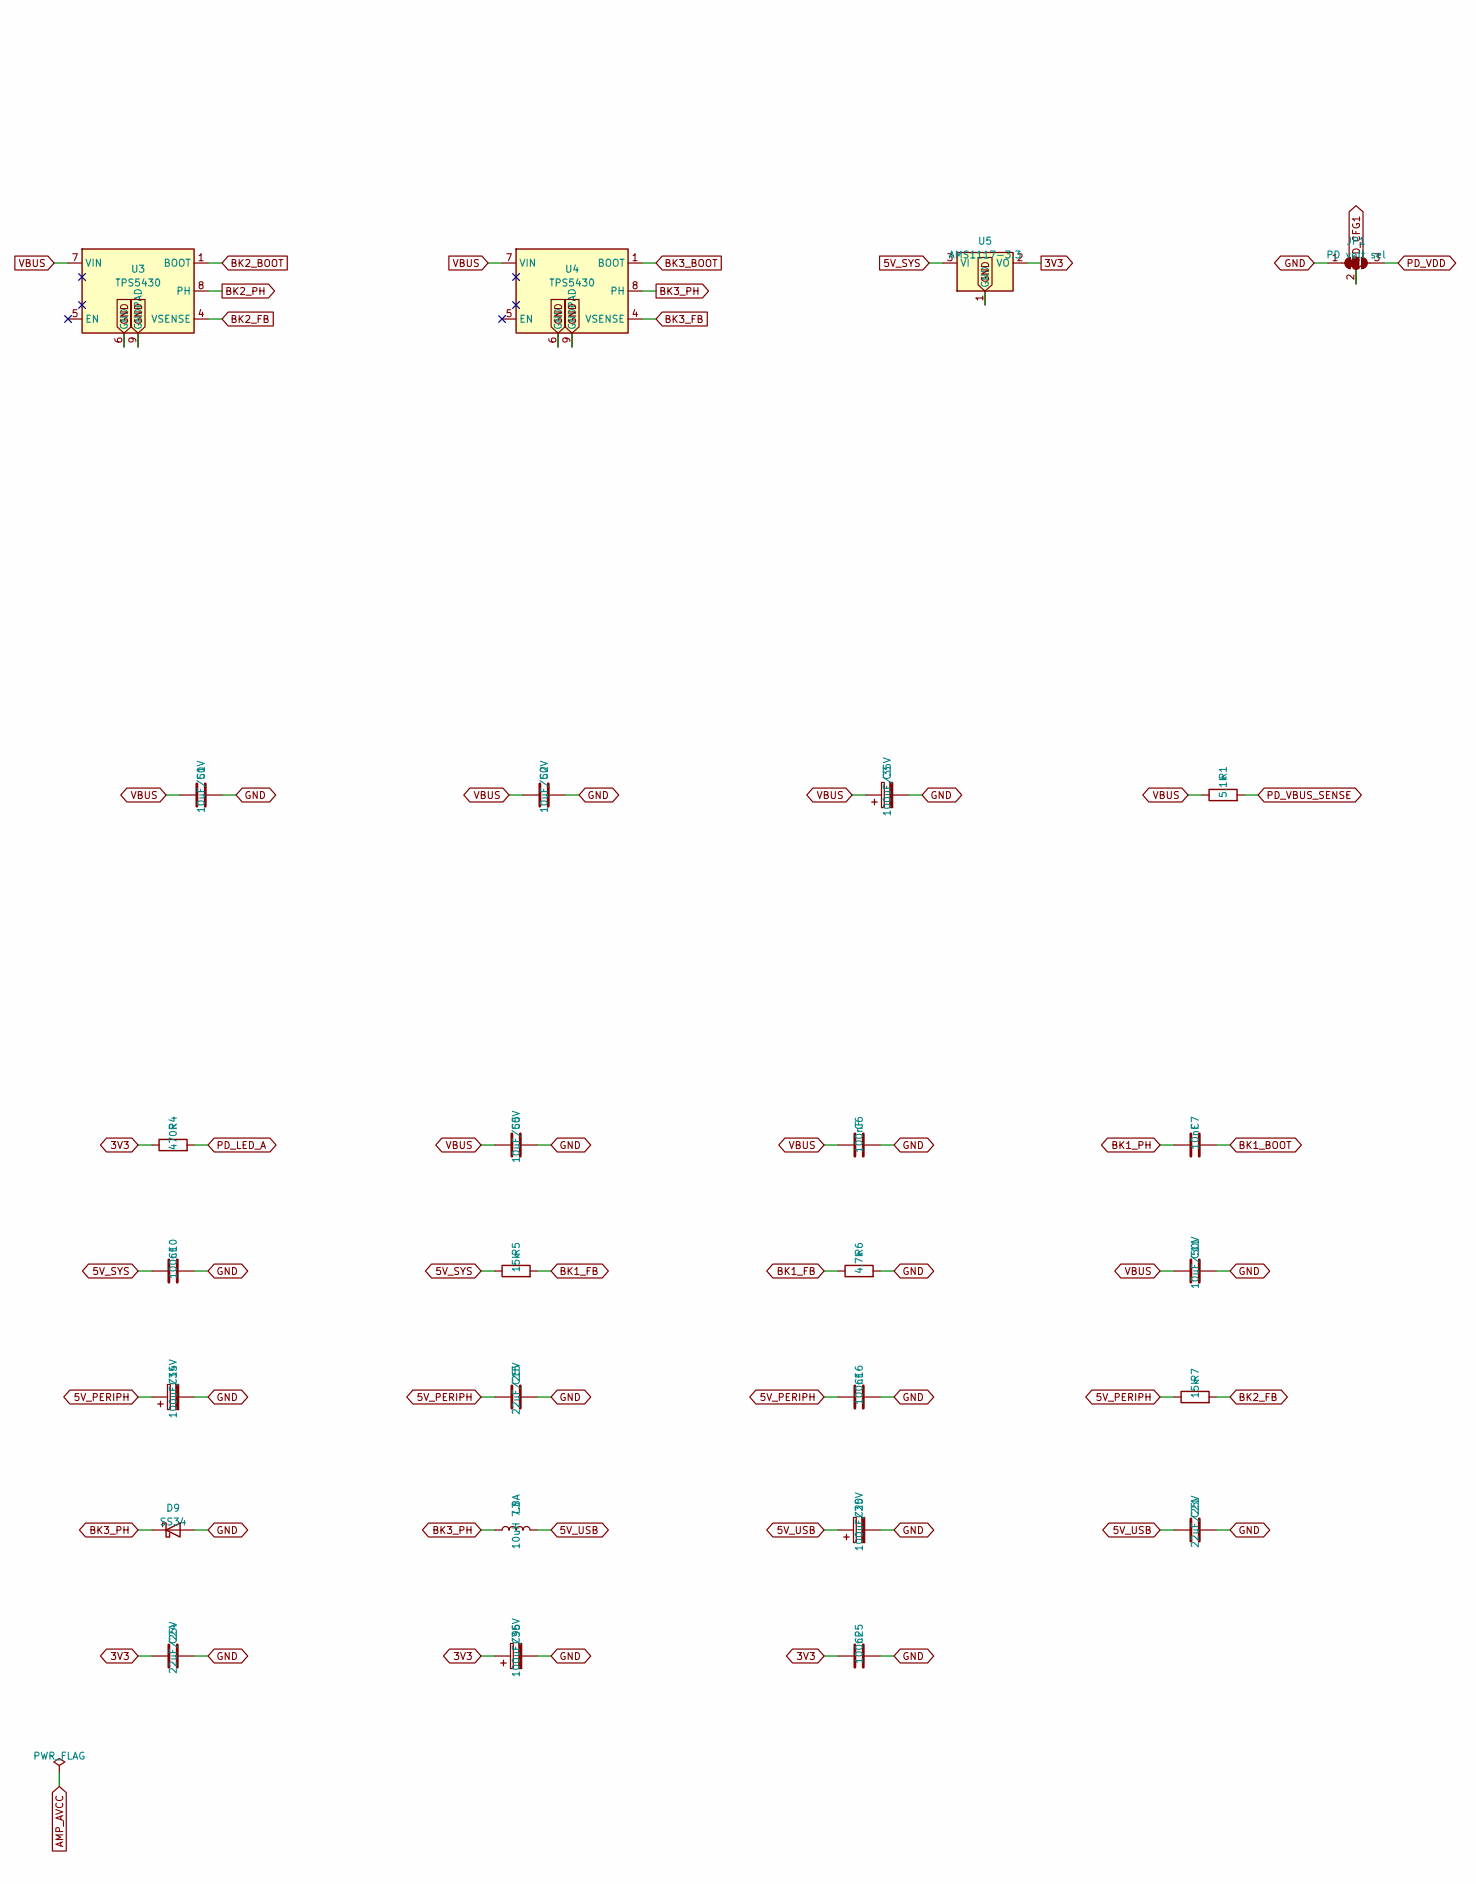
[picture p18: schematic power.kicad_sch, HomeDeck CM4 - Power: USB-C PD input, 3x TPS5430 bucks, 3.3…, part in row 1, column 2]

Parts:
C1, C2, C5, C11, C17: 10uF/50V; C_1206_3216Metric; LCSC C13585
C3, C8, C14, C20, C96: 100uF/35V; CP_Elec_6.3x7.7; LCSC C3339
C4: 1uF; C_0603_1608Metric; LCSC C15849
C6, C10, C12, C16, C18, C22, C25: 100nF; C_0603_1608Metric; LCSC C14663
C7, C13, C19: 10nF; C_0603_1608Metric; LCSC C57112
C9, C15, C21, C23, C24: 22uF/25V; C_1206_3216Metric; LCSC C12891
D1: SMBJ24A; D_SMB; MPN SMBJ24A; LCSC C87268
D2: PD OK (green); LED_0805_2012Metric; MPN KT-0805G; LCSC C2297
D7, D8, D9: SS34; D_SMA; MPN SS34; LCSC C8678
F1: 5A; Fuse_1206_3216Metric; MPN SF-1206F500-2; LCSC C48332
J1: USB-C PD IN; USB_C_Receptacle_HRO_TYPE-C-31-M-12; MPN TYPE-C-31-M-12; LCSC C165948
JP1, JP2, JP3: PD volt sel; SolderJumper-3_P1.3mm_Bridged12_RoundedPad1.0x1.5mm
L1, L2, L3: 10uH 7.8A; L_Sunlord_MWSA1004S; MPN MWSA1004S-100MT; LCSC C408487
R1: 5.1k; R_0603_1608Metric; LCSC C23186
R2: 1k/0.25W; R_1206_3216Metric; LCSC C4410
R3: 10k; R_0603_1608Metric; LCSC C25804
R4: 470R; R_0603_1608Metric; LCSC C23179
R5, R7, R9: 15k; R_0603_1608Metric; LCSC C22809
R6, R8, R10: 4.7k; R_0603_1608Metric; LCSC C23162
U1: CH224K; ESSOP-10-1EP_3.9x4.9mm_P1.0mm; MPN CH224K; LCSC C970725
U2, U3, U4: TPS5430; TI_SO-PowerPAD-8_ThermalVias; MPN TPS5430DDAR; LCSC C9864
U5: AMS1117-3.3; SOT-223-3_TabPin2; MPN AMS1117-3.3; LCSC C6186

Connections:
3V3: C24.1, C25.1, C96.1, R4.1, U5.2 (VO); also elsewhere on the board
5V_PERIPH: C14.1, C15.1, C16.1, L2.2, R7.1; also elsewhere on the board
5V_SYS: C8.1, C9.1, C10.1, C23.1, L1.2, R5.1, U5.3 (VI); also elsewhere on the board
5V_USB: C20.1, C21.1, C22.1, L3.2, R9.1; also elsewhere on the board
BK1_BOOT: C7.2, U2.1 (BOOT)
BK1_FB: R5.2, R6.1, U2.4 (VSENSE)
BK1_PH: C7.1, D7.1 (K), L1.1, U2.8 (PH)
BK2_BOOT: C13.2, U3.1 (BOOT)
BK2_FB: R7.2, R8.1, U3.4 (VSENSE)
BK2_PH: C13.1, D8.1 (K), L2.1, U3.8 (PH)
BK3_BOOT: C19.2, U4.1 (BOOT)
BK3_FB: R9.2, R10.1, U4.4 (VSENSE)
BK3_PH: C19.1, D9.1 (K), L3.1, U4.8 (PH)
CM4_3V3: R3.1; also elsewhere on the board
GND: C1.2, C2.2, C3.2, C4.2, C5.2, C6.2, C8.2, C9.2, C10.2, C11.2, C12.2, C14.2, C15.2, C16.2, C17.2, C18.2, C20.2, C21.2, C22.2, C23.2, C24.2, C25.2, C96.2, D1.2 (A2), D7.2 (A), D8.2 (A), D9.2 (A), J1.A1 (GND), J1.A12 (GND), J1.B1 (GND), J1.B12 (GND), J1.S1 (SHIELD), JP1.1 (A), JP2.3 (B), JP3.3 (B), R6.2, R8.2, R10.2, U1.11 (GND), U2.6 (GND), U2.9 (GNDPAD), U3.6 (GND), U3.9 (GNDPAD), U4.6 (GND), U4.9 (GNDPAD), U5.1 (GND); also elsewhere on the board
PD_CC1: J1.A5 (CC1), U1.6 (CC1)
PD_CC2: J1.B5 (CC2), U1.7 (CC2)
PD_CFG1: JP1.2 (C), U1.2 (CFG1)
PD_CFG2: JP2.2 (C), U1.3 (CFG2)
PD_CFG3: JP3.2 (C), U1.9 (CFG3)
PD_DM: J1.A7 (D-), J1.B7 (D-), U1.5 (DM)
PD_DP: J1.A6 (D+), J1.B6 (D+), U1.4 (DP)
PD_GOOD: D2.1 (K), R3.2, U1.10 (PG); also elsewhere on the board
PD_LED_A: D2.2 (A), R4.2
PD_VBUS_SENSE: R1.2, U1.8 (VBUS)
PD_VDD: C4.1, JP1.3 (B), JP2.1 (A), JP3.1 (A), R2.2, U1.1 (VDD)
VBUS: C1.1, C2.1, C3.1, C5.1, C6.1, C11.1, C12.1, C17.1, C18.1, D1.1 (A1), F1.2, R1.1, R2.1, U2.7 (VIN), U3.7 (VIN), U4.7 (VIN); also elsewhere on the board
VBUS_RAW: F1.1, J1.A4 (VBUS), J1.A9 (VBUS), J1.B4 (VBUS), J1.B9 (VBUS)

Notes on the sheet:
Power: USB-C PD input, 3x TPS5430 bucks, 3.3V LDO

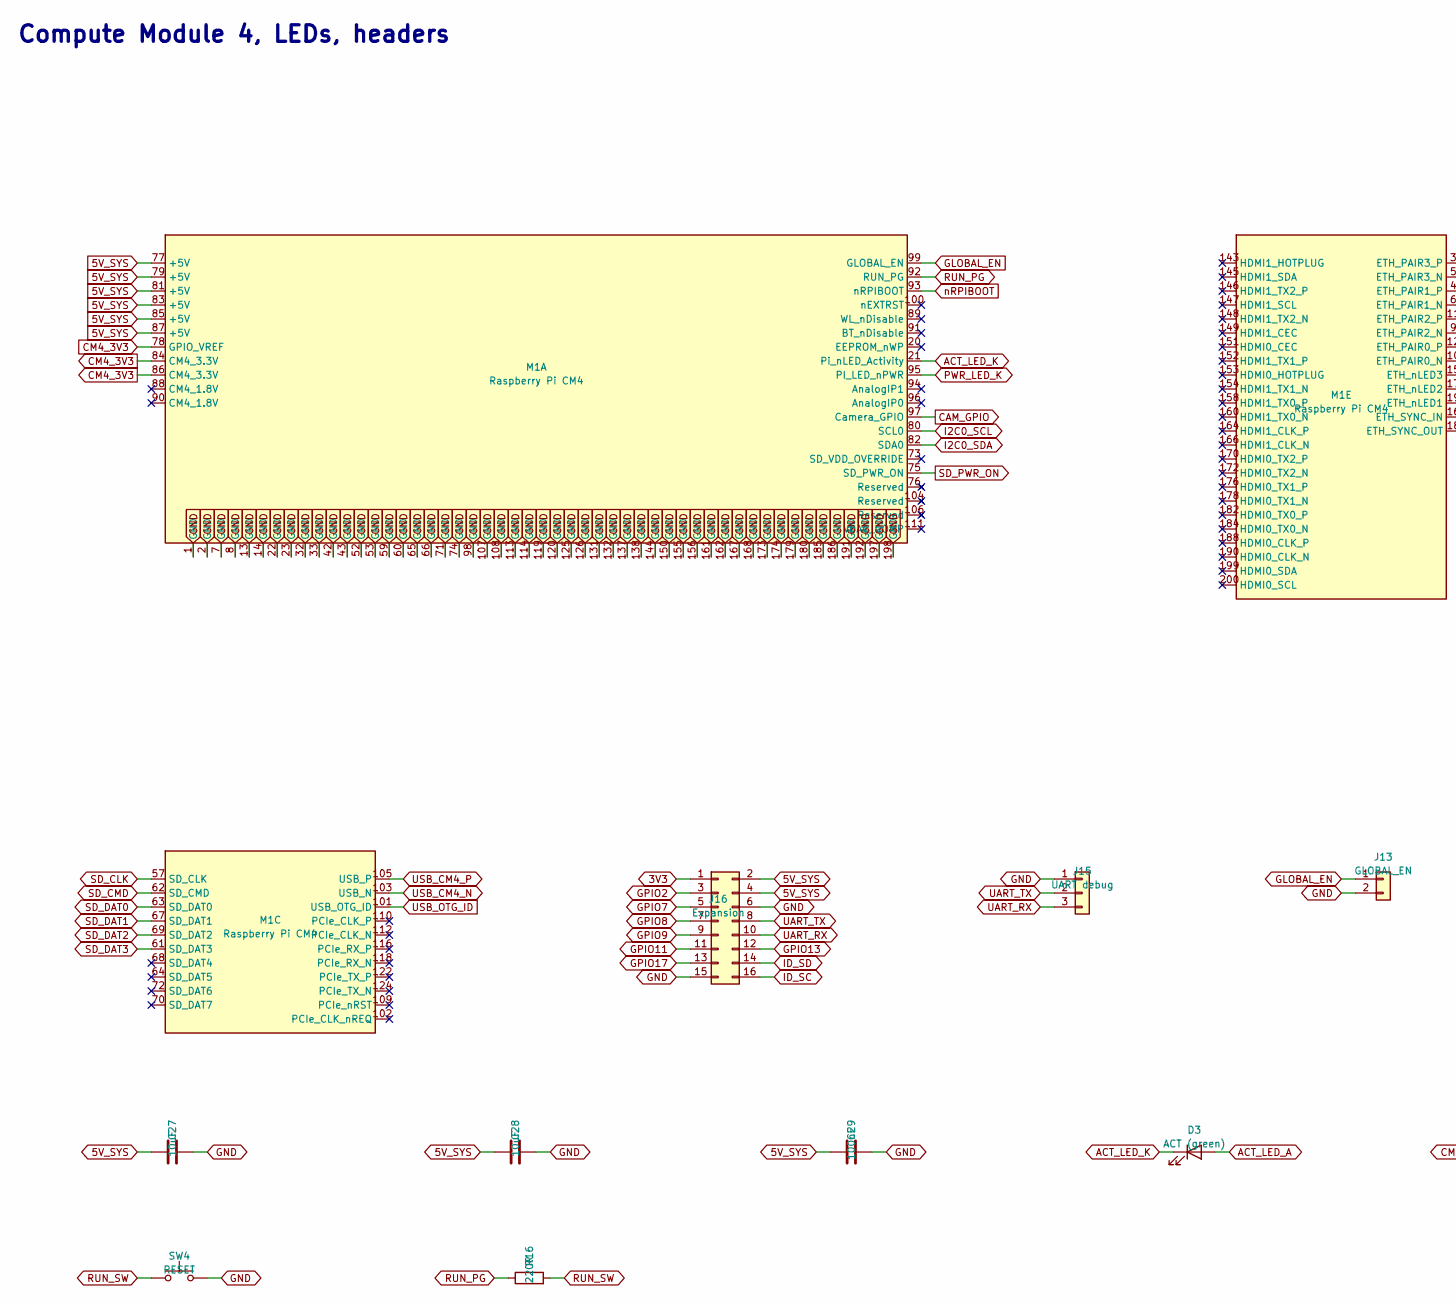
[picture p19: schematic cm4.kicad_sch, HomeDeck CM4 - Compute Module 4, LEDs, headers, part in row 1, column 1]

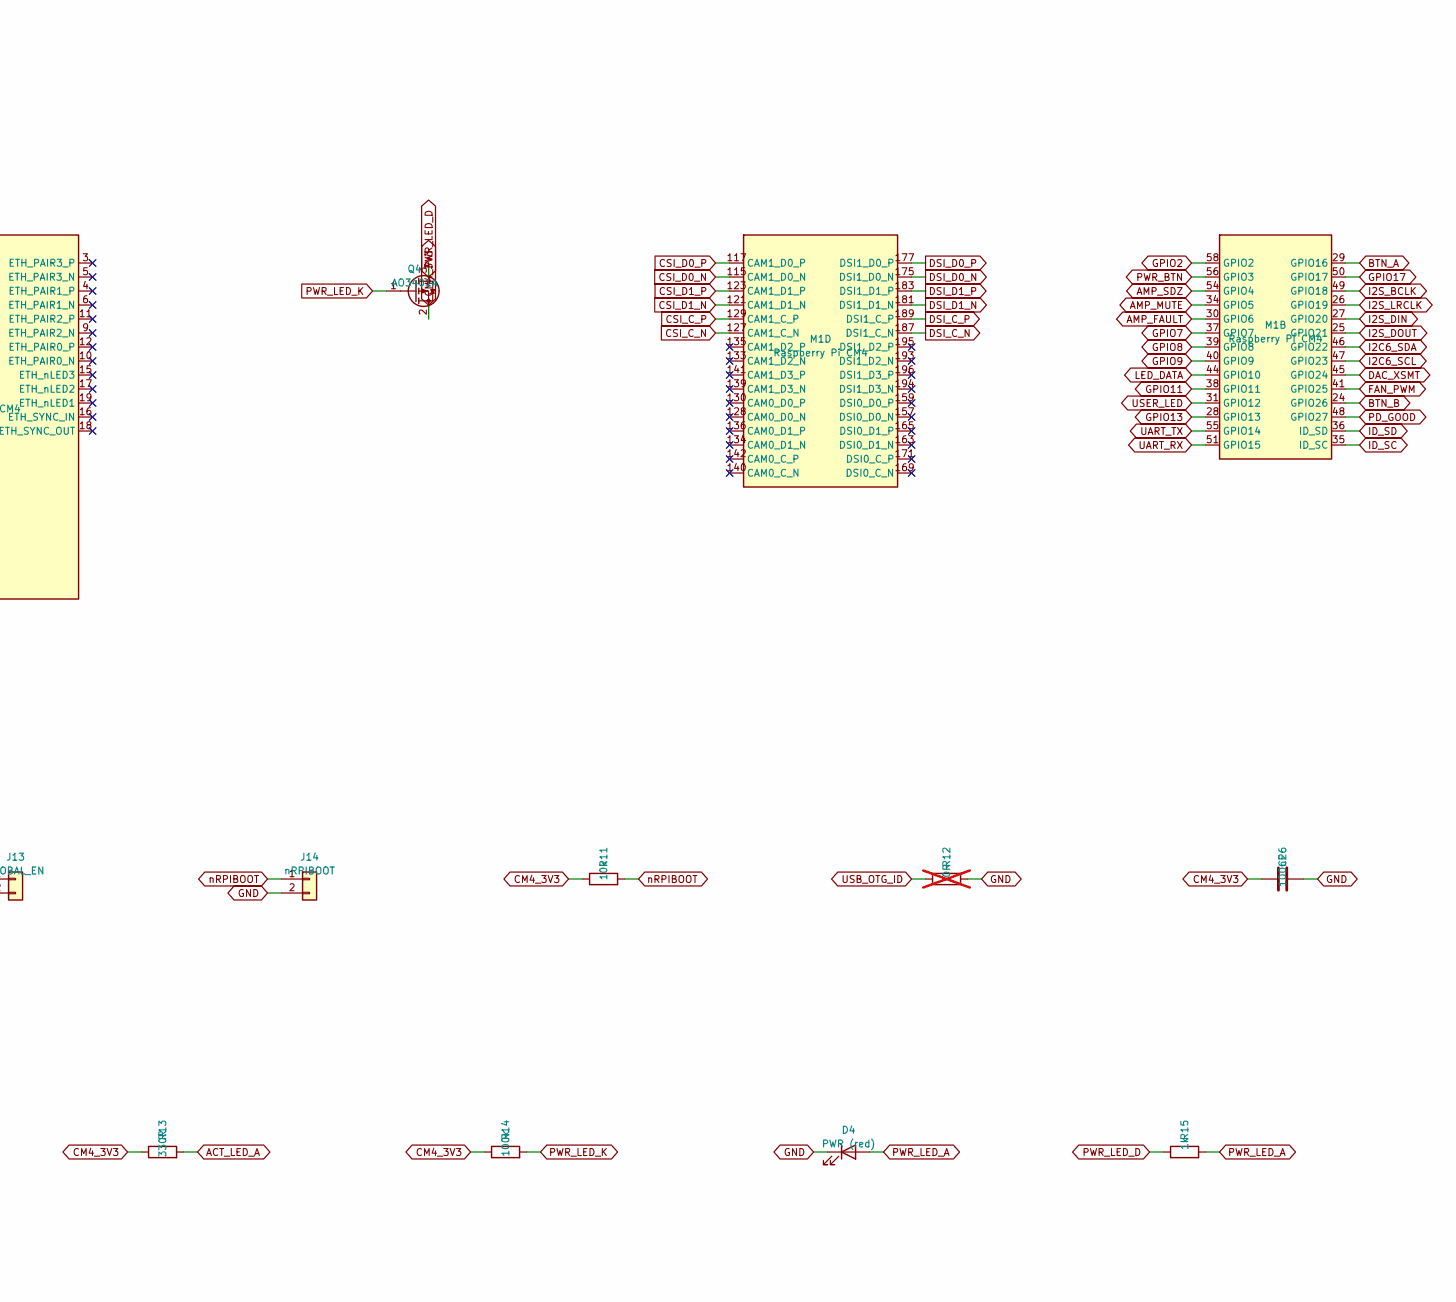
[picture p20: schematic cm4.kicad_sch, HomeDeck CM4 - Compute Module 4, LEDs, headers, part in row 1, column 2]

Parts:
C26, C29: 100nF; C_0603_1608Metric; LCSC C14663
C27, C28: 10uF; C_0603_1608Metric; LCSC C96446
D3: ACT (green); LED_0805_2012Metric; MPN KT-0805G; LCSC C2297
D4: PWR (red); LED_0603_1608Metric; MPN KT-0603R; LCSC C2286
J13: GLOBAL_EN; PinHeader_1x02_P2.54mm_Vertical; MPN B-2100S02P-A110; LCSC C124375
J14: nRPIBOOT; PinHeader_1x02_P2.54mm_Vertical; MPN B-2100S02P-A110; LCSC C124375
J15: UART debug; PinHeader_1x03_P2.54mm_Vertical; MPN B-2100S03P-A110; LCSC C124376
J16: Expansion; PinHeader_2x08_P2.54mm_Vertical; MPN PZ254V-12-16P; LCSC C492425
M1: Raspberry Pi CM4; RPi_CM4; MPN CM4
Q4: AO3401A; SOT-23; MPN AO3401A; LCSC C15127
R11: 10k; R_0603_1608Metric; LCSC C25804
R12: 0R; R_0603_1608Metric; LCSC C21189; not fitted
R13: 330R; R_0603_1608Metric; LCSC C23138
R14: 100k; R_0603_1608Metric; LCSC C25803
R15: 1k; R_0603_1608Metric; LCSC C21190
R16: 220R; R_0603_1608Metric; LCSC C22962
SW4: RESET; SW_Push_1P1T_XKB_TS-1187A; MPN TS-1187A-B-A-B; LCSC C318884

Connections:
3V3: J16.1; also elsewhere on the board
5V_SYS: C27.1, C28.1, C29.1, J16.2, J16.4, M1.77 (+5V), M1.79 (+5V), M1.81 (+5V), M1.83 (+5V), M1.85 (+5V), M1.87 (+5V); also elsewhere on the board
ACT_LED_A: D3.2 (A), R13.2
ACT_LED_K: D3.1 (K), M1.21 (Pi_nLED_Activity)
AMP_FAULT: M1.30 (GPIO6); also elsewhere on the board
AMP_MUTE: M1.34 (GPIO5); also elsewhere on the board
AMP_SDZ: M1.54 (GPIO4); also elsewhere on the board
BTN_A: M1.29 (GPIO16); also elsewhere on the board
BTN_B: M1.24 (GPIO26); also elsewhere on the board
CAM_GPIO: M1.97 (Camera_GPIO); also elsewhere on the board
CM4_3V3: C26.1, M1.78 (GPIO_VREF), M1.84 (CM4_3.3V), M1.86 (CM4_3.3V), Q4.2 (S), R11.1, R13.1, R14.1; also elsewhere on the board
CSI_C_N: M1.127 (CAM1_C_N); also elsewhere on the board
CSI_C_P: M1.129 (CAM1_C_P); also elsewhere on the board
CSI_D0_N: M1.115 (CAM1_D0_N); also elsewhere on the board
CSI_D0_P: M1.117 (CAM1_D0_P); also elsewhere on the board
CSI_D1_N: M1.121 (CAM1_D1_N); also elsewhere on the board
CSI_D1_P: M1.123 (CAM1_D1_P); also elsewhere on the board
DAC_XSMT: M1.45 (GPIO24); also elsewhere on the board
DSI_C_N: M1.187 (DSI1_C_N); also elsewhere on the board
DSI_C_P: M1.189 (DSI1_C_P); also elsewhere on the board
DSI_D0_N: M1.175 (DSI1_D0_N); also elsewhere on the board
DSI_D0_P: M1.177 (DSI1_D0_P); also elsewhere on the board
DSI_D1_N: M1.181 (DSI1_D1_N); also elsewhere on the board
DSI_D1_P: M1.183 (DSI1_D1_P); also elsewhere on the board
FAN_PWM: M1.41 (GPIO25); also elsewhere on the board
GLOBAL_EN: J13.1, M1.99 (GLOBAL_EN)
GND: C26.2, C27.2, C28.2, C29.2, D4.1 (K), J13.2, J14.2, J15.1, J16.6, J16.15, M1.1 (GND), M1.2 (GND), M1.7 (GND), M1.8 (GND), M1.13 (GND), M1.14 (GND), M1.22 (GND), M1.23 (GND), M1.32 (GND), M1.33 (GND), M1.42 (GND), M1.43 (GND), M1.52 (GND), M1.53 (GND), M1.59 (GND), M1.60 (GND), M1.65 (GND), M1.66 (GND), M1.71 (GND), M1.74 (GND), M1.98 (GND), M1.107 (GND), M1.108 (GND), M1.113 (GND), M1.114 (GND), M1.119 (GND), M1.120 (GND), M1.125 (GND), M1.126 (GND), M1.131 (GND), M1.132 (GND), M1.137 (GND), M1.138 (GND), M1.144 (GND), M1.150 (GND), M1.155 (GND), M1.156 (GND), M1.161 (GND), M1.162 (GND), M1.167 (GND), M1.168 (GND), M1.173 (GND), M1.174 (GND), M1.179 (GND), M1.180 (GND), M1.185 (GND), M1.186 (GND), M1.191 (GND), M1.192 (GND), M1.197 (GND), M1.198 (GND), R12.2, SW4.2; also elsewhere on the board
GPIO2: J16.3, M1.58 (GPIO2)
GPIO7: J16.5, M1.37 (GPIO7)
GPIO8: J16.7, M1.39 (GPIO8)
GPIO9: J16.9, M1.40 (GPIO9)
GPIO11: J16.11, M1.38 (GPIO11)
GPIO13: J16.12, M1.28 (GPIO13)
GPIO17: J16.13, M1.50 (GPIO17)
I2C0_SCL: M1.80 (SCL0); also elsewhere on the board
I2C0_SDA: M1.82 (SDA0); also elsewhere on the board
I2C6_SCL: M1.47 (GPIO23); also elsewhere on the board
I2C6_SDA: M1.46 (GPIO22); also elsewhere on the board
I2S_BCLK: M1.49 (GPIO18); also elsewhere on the board
I2S_DIN: M1.27 (GPIO20); also elsewhere on the board
I2S_DOUT: M1.25 (GPIO21); also elsewhere on the board
I2S_LRCLK: M1.26 (GPIO19); also elsewhere on the board
ID_SC: J16.16, M1.35 (ID_SC)
ID_SD: J16.14, M1.36 (ID_SD)
LED_DATA: M1.44 (GPIO10); also elsewhere on the board
PD_GOOD: M1.48 (GPIO27); also elsewhere on the board
PWR_BTN: M1.56 (GPIO3); also elsewhere on the board
PWR_LED_A: D4.2 (A), R15.2
PWR_LED_D: Q4.3 (D), R15.1
PWR_LED_K: M1.95 (PI_LED_nPWR), Q4.1 (G), R14.2
RUN_PG: M1.92 (RUN_PG), R16.1
RUN_SW: R16.2, SW4.1
SD_CLK: M1.57 (SD_CLK); also elsewhere on the board
SD_CMD: M1.62 (SD_CMD); also elsewhere on the board
SD_DAT0: M1.63 (SD_DAT0); also elsewhere on the board
SD_DAT1: M1.67 (SD_DAT1); also elsewhere on the board
SD_DAT2: M1.69 (SD_DAT2); also elsewhere on the board
SD_DAT3: M1.61 (SD_DAT3); also elsewhere on the board
SD_PWR_ON: M1.75 (SD_PWR_ON); also elsewhere on the board
UART_RX: J15.3, J16.10, M1.51 (GPIO15)
UART_TX: J15.2, J16.8, M1.55 (GPIO14)
USB_CM4_N: M1.103 (USB_N); also elsewhere on the board
USB_CM4_P: M1.105 (USB_P); also elsewhere on the board
USB_OTG_ID: M1.101 (USB_OTG_ID), R12.1
USER_LED: M1.31 (GPIO12); also elsewhere on the board
nRPIBOOT: J14.1, M1.93 (nRPIBOOT), R11.2; also elsewhere on the board

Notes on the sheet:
Compute Module 4, LEDs, headers

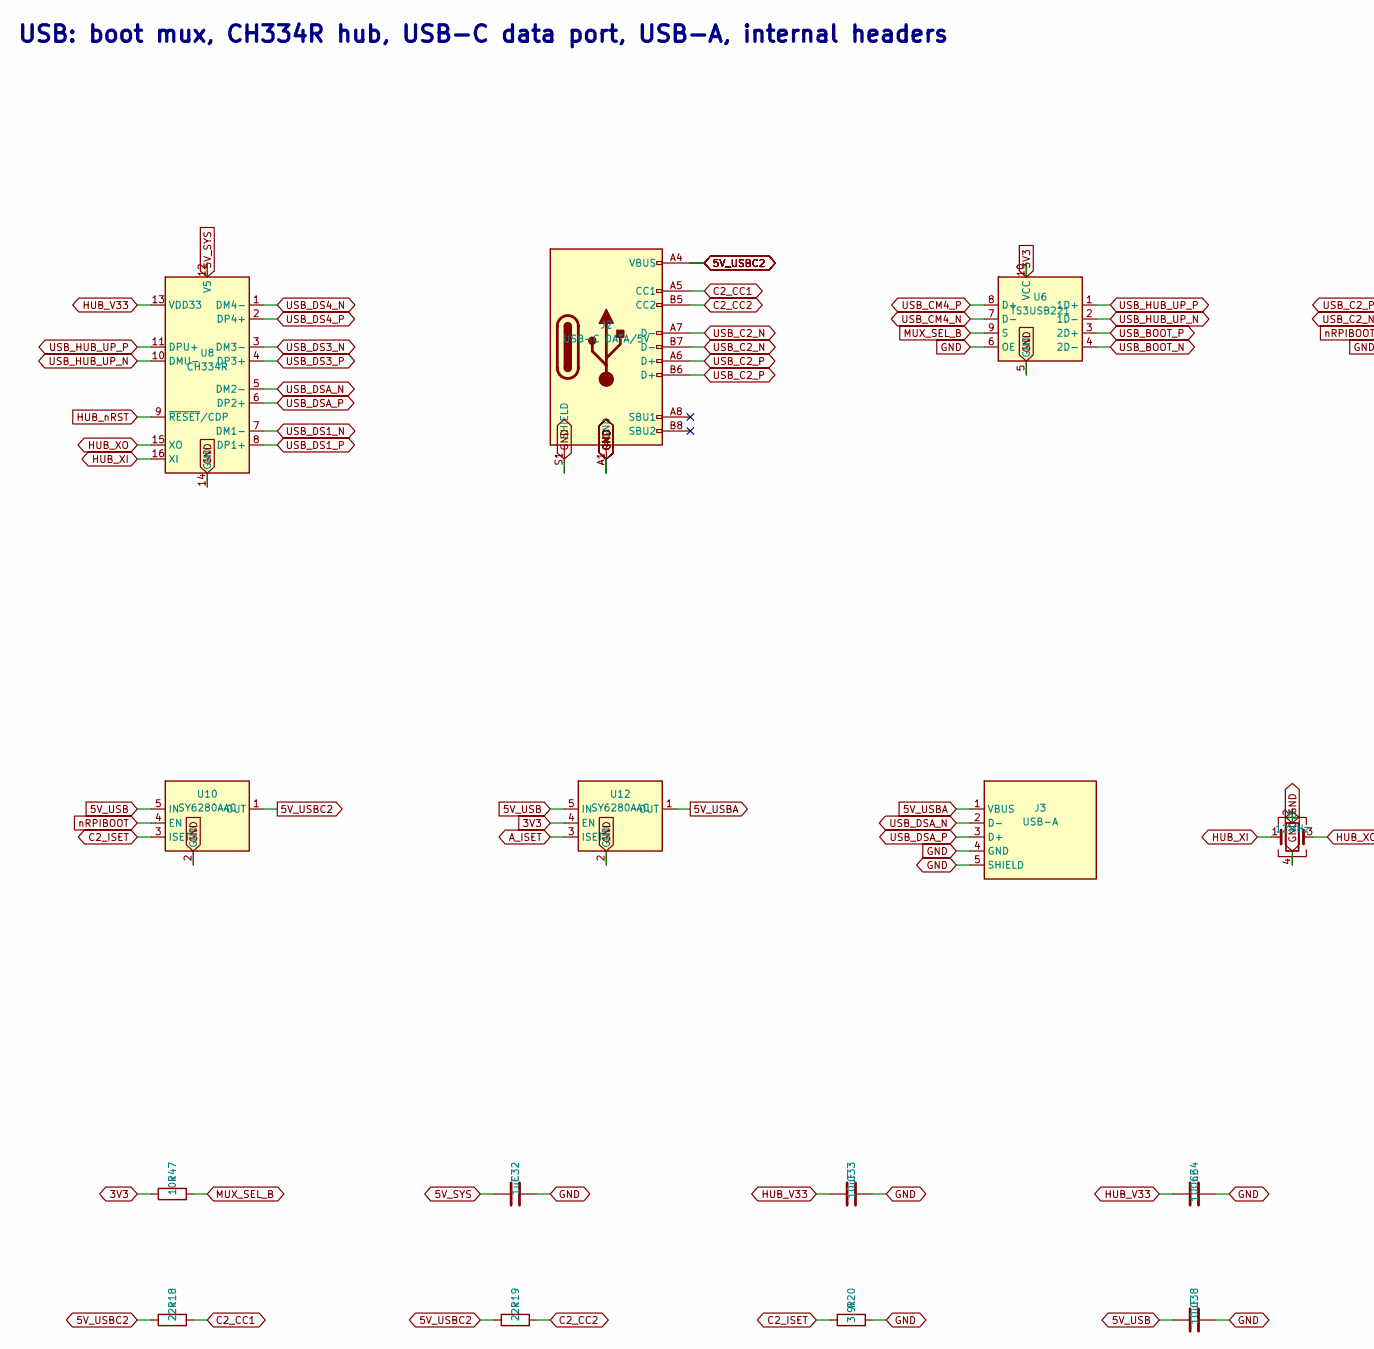
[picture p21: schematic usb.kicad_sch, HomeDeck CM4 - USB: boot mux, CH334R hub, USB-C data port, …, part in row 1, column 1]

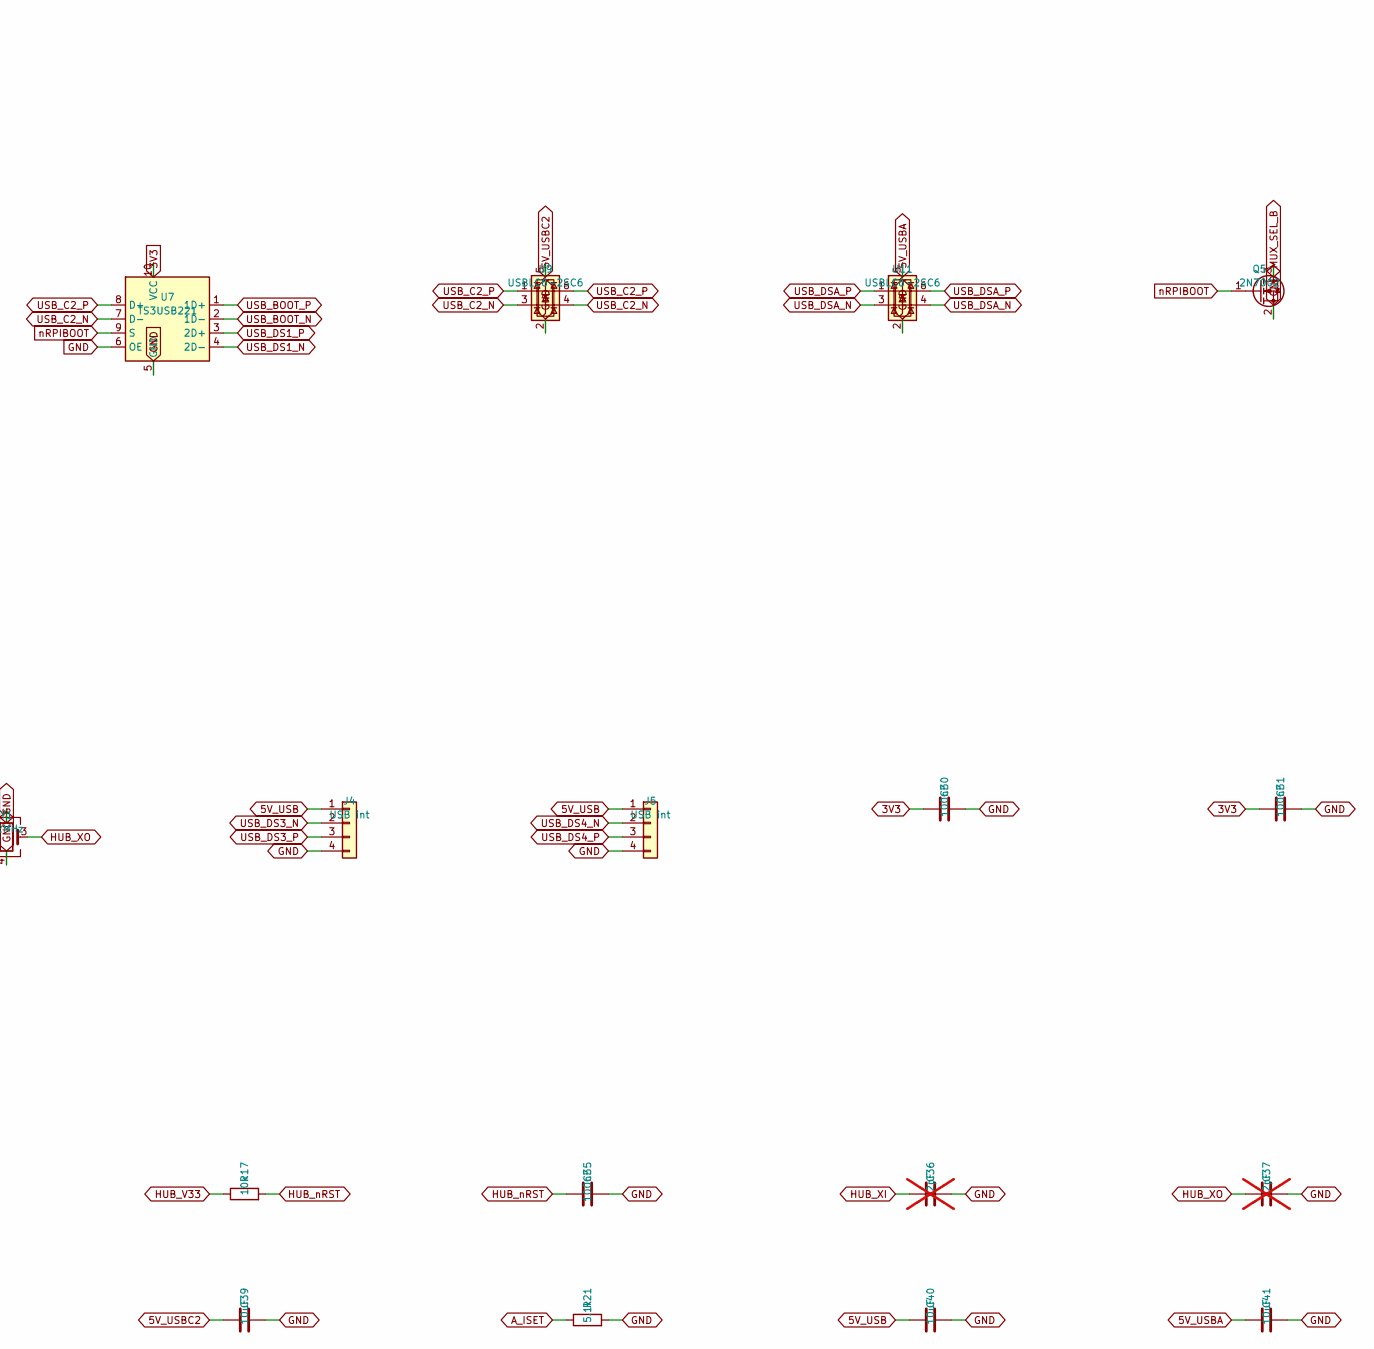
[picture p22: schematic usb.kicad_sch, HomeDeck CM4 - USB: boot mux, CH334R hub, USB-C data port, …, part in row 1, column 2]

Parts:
C30, C31, C34, C35: 100nF; C_0603_1608Metric; LCSC C14663
C32: 1uF; C_0603_1608Metric; LCSC C15849
C33, C38, C39, C40, C41: 10uF; C_0603_1608Metric; LCSC C96446
C36, C37: 22pF; C_0603_1608Metric; LCSC C1653; not fitted
J2: USB-C DATA/5V; USB_C_Receptacle_HRO_TYPE-C-31-M-12; MPN TYPE-C-31-M-12; LCSC C165948
J3: USB-A; USB_A_Molex_67643_Horizontal; MPN 901-211A1021D10100; LCSC C2346
J4, J5: USB int; PinHeader_1x04_P2.54mm_Vertical; MPN B-2100S04P-A110; LCSC C124378
Q5: 2N7002; SOT-23; MPN 2N7002; LCSC C8545
R17, R47: 10k; R_0603_1608Metric; LCSC C25804
R18, R19: 22k; R_0603_1608Metric; LCSC C31850
R20: 3.9k; R_0603_1608Metric; LCSC C23018
R21: 5.1k; R_0603_1608Metric; LCSC C23186
U6, U7: TS3USB221; Texas_UQFN-10_1.5x2mm_P0.5mm; MPN TS3USB221RSER; LCSC C130085
U8: CH334R; QSOP-16_3.9x4.9mm_P0.635mm; MPN CH334R; LCSC C4154405
U9, U11: USBLC6-2SC6; SOT-23-6; MPN USBLC6-2SC6; LCSC C7519
U10, U12: SY6280AAC; SOT-23-5; MPN SY6280AAC; LCSC C55136
Y1: 12MHz; Crystal_SMD_3225-4Pin_3.2x2.5mm; MPN X322512MSB4SI; LCSC C9002

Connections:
3V3: C30.1, C31.1, R47.1, U6.10 (VCC), U7.10 (VCC), U12.4 (EN); also elsewhere on the board
5V_SYS: C32.1, U8.12 (V5); also elsewhere on the board
5V_USB: C38.1, C40.1, J4.1, J5.1, U10.5 (IN), U12.5 (IN); also elsewhere on the board
5V_USBA: C41.1, J3.1 (VBUS), U11.5 (VBUS), U12.1 (OUT)
5V_USBC2: C39.1, J2.A4 (VBUS), J2.A9 (VBUS), J2.B4 (VBUS), J2.B9 (VBUS), R18.1, R19.1, U9.5 (VBUS), U10.1 (OUT)
A_ISET: R21.1, U12.3 (ISET)
C2_CC1: J2.A5 (CC1), R18.2
C2_CC2: J2.B5 (CC2), R19.2
C2_ISET: R20.1, U10.3 (ISET)
GND: C30.2, C31.2, C32.2, C33.2, C34.2, C35.2, C36.2, C37.2, C38.2, C39.2, C40.2, C41.2, J2.A1 (GND), J2.A12 (GND), J2.B1 (GND), J2.B12 (GND), J2.S1 (SHIELD), J3.4 (GND), J3.5 (SHIELD), J4.4, J5.4, Q5.2 (S), R20.2, R21.2, U6.5 (GND), U6.6 (OE), U7.5 (GND), U7.6 (OE), U8.14 (GND), U9.2 (GND), U10.2 (GND), U11.2 (GND), U12.2 (GND), Y1.2, Y1.4; also elsewhere on the board
HUB_V33: C33.1, C34.1, R17.1, U8.13 (VDD33)
HUB_XI: C36.1, U8.16 (XI), Y1.1
HUB_XO: C37.1, U8.15 (XO), Y1.3
HUB_nRST: C35.1, R17.2, U8.9 (~RESET/CDP)
MUX_SEL_B: Q5.3 (D), R47.2, U6.9 (S)
USB_BOOT_N: U6.4 (2D-), U7.2 (1D-)
USB_BOOT_P: U6.3 (2D+), U7.1 (1D+)
USB_C2_N: J2.A7 (D-), J2.B7 (D-), U7.7 (D-), U9.3 (I/O2), U9.4 (I/O2)
USB_C2_P: J2.A6 (D+), J2.B6 (D+), U7.8 (D+), U9.1 (I/O1), U9.6 (I/O1)
USB_CM4_N: U6.7 (D-); also elsewhere on the board
USB_CM4_P: U6.8 (D+); also elsewhere on the board
USB_DS1_N: U7.4 (2D-), U8.7 (DM1-)
USB_DS1_P: U7.3 (2D+), U8.8 (DP1+)
USB_DS3_N: J4.2, U8.3 (DM3-)
USB_DS3_P: J4.3, U8.4 (DP3+)
USB_DS4_N: J5.2, U8.1 (DM4-)
USB_DS4_P: J5.3, U8.2 (DP4+)
USB_DSA_N: J3.2 (D-), U8.5 (DM2-), U11.3 (I/O2), U11.4 (I/O2)
USB_DSA_P: J3.3 (D+), U8.6 (DP2+), U11.1 (I/O1), U11.6 (I/O1)
USB_HUB_UP_N: U6.2 (1D-), U8.10 (DMU-)
USB_HUB_UP_P: U6.1 (1D+), U8.11 (DPU+)
nRPIBOOT: Q5.1 (G), U7.9 (S), U10.4 (EN); also elsewhere on the board

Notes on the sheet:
USB: boot mux, CH334R hub, USB-C data port, USB-A, internal headers

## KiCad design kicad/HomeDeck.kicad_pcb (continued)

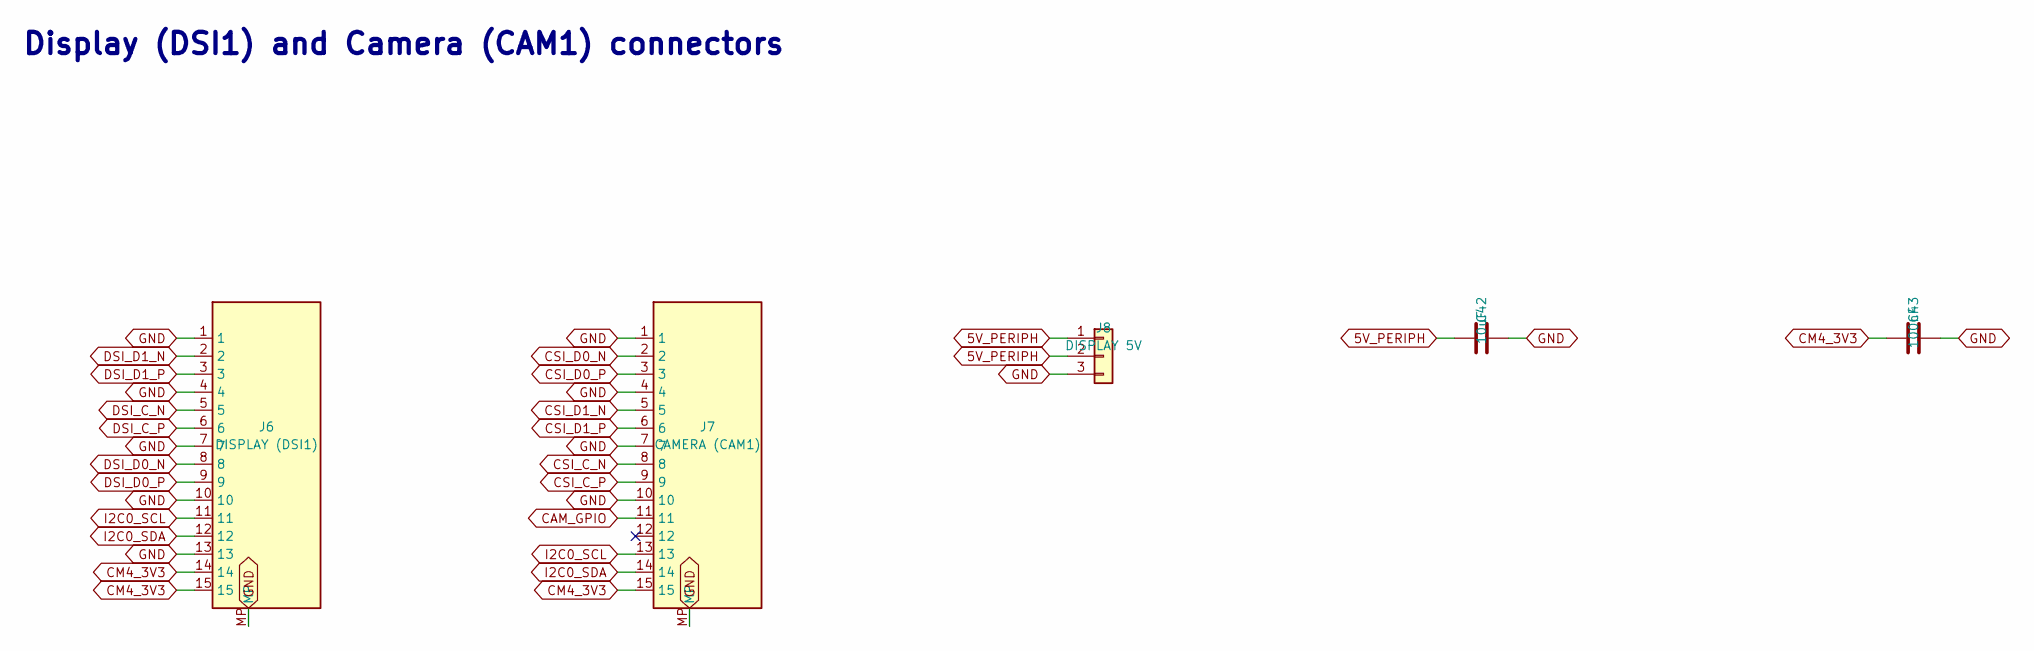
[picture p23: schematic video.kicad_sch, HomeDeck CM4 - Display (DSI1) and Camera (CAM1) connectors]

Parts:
C42: 10uF; C_0603_1608Metric; LCSC C96446
C43: 100nF; C_0603_1608Metric; LCSC C14663
J6: DISPLAY (DSI1); FPC_15P_1.0mm_BottomContact_RA; MPN 1.0-15PContact,Bottom; LCSC C66660
J7: CAMERA (CAM1); FPC_15P_1.0mm_BottomContact_RA; MPN 1.0-15PContact,Bottom; LCSC C66660
J8: DISPLAY 5V; PinHeader_1x03_P2.54mm_Vertical; MPN B-2100S03P-A110; LCSC C124376

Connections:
5V_PERIPH: C42.1, J8.1, J8.2; also elsewhere on the board
CAM_GPIO: J7.11; also elsewhere on the board
CM4_3V3: C43.1, J6.14, J6.15, J7.15; also elsewhere on the board
CSI_C_N: J7.8; also elsewhere on the board
CSI_C_P: J7.9; also elsewhere on the board
CSI_D0_N: J7.2; also elsewhere on the board
CSI_D0_P: J7.3; also elsewhere on the board
CSI_D1_N: J7.5; also elsewhere on the board
CSI_D1_P: J7.6; also elsewhere on the board
DSI_C_N: J6.5; also elsewhere on the board
DSI_C_P: J6.6; also elsewhere on the board
DSI_D0_N: J6.8; also elsewhere on the board
DSI_D0_P: J6.9; also elsewhere on the board
DSI_D1_N: J6.2; also elsewhere on the board
DSI_D1_P: J6.3; also elsewhere on the board
GND: C42.2, C43.2, J6.1, J6.4, J6.7, J6.10, J6.13, J6.MP, J7.1, J7.4, J7.7, J7.10, J7.MP, J8.3; also elsewhere on the board
I2C0_SCL: J6.11, J7.13; also elsewhere on the board
I2C0_SDA: J6.12, J7.14; also elsewhere on the board

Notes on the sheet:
Display (DSI1) and Camera (CAM1) connectors

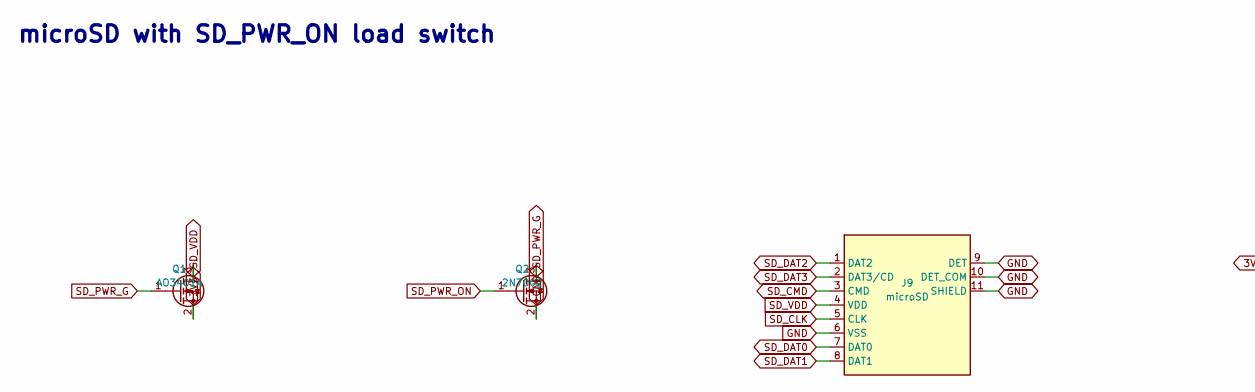
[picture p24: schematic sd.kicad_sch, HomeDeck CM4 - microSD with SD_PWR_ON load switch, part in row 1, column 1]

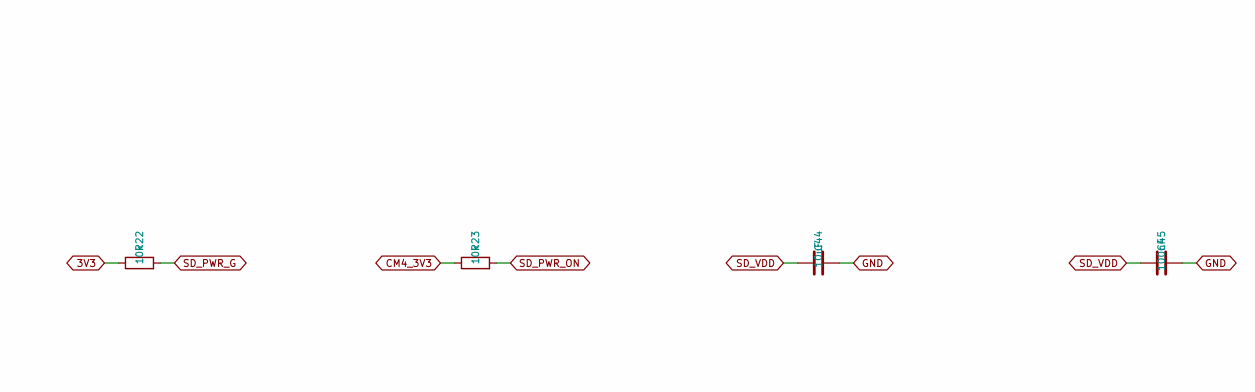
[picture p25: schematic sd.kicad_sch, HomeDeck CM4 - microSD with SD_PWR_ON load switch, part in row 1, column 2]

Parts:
C44: 10uF; C_0603_1608Metric; LCSC C96446
C45: 100nF; C_0603_1608Metric; LCSC C14663
J9: microSD; microSD_HC_Molex_104031-0811; MPN 104031-0811; LCSC C585350
Q1: AO3401A; SOT-23; MPN AO3401A; LCSC C15127
Q2: 2N7002; SOT-23; MPN 2N7002; LCSC C8545
R22, R23: 10k; R_0603_1608Metric; LCSC C25804

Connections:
3V3: Q1.2 (S), R22.1; also elsewhere on the board
CM4_3V3: R23.1; also elsewhere on the board
GND: C44.2, C45.2, J9.6 (VSS), J9.9 (DET), J9.10 (DET_COM), J9.11 (SHIELD), Q2.2 (S); also elsewhere on the board
SD_CLK: J9.5 (CLK); also elsewhere on the board
SD_CMD: J9.3 (CMD); also elsewhere on the board
SD_DAT0: J9.7 (DAT0); also elsewhere on the board
SD_DAT1: J9.8 (DAT1); also elsewhere on the board
SD_DAT2: J9.1 (DAT2); also elsewhere on the board
SD_DAT3: J9.2 (DAT3/CD); also elsewhere on the board
SD_PWR_G: Q1.1 (G), Q2.3 (D), R22.2
SD_PWR_ON: Q2.1 (G), R23.2; also elsewhere on the board
SD_VDD: C44.1, C45.1, J9.4 (VDD), Q1.3 (D)

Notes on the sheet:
microSD with SD_PWR_ON load switch

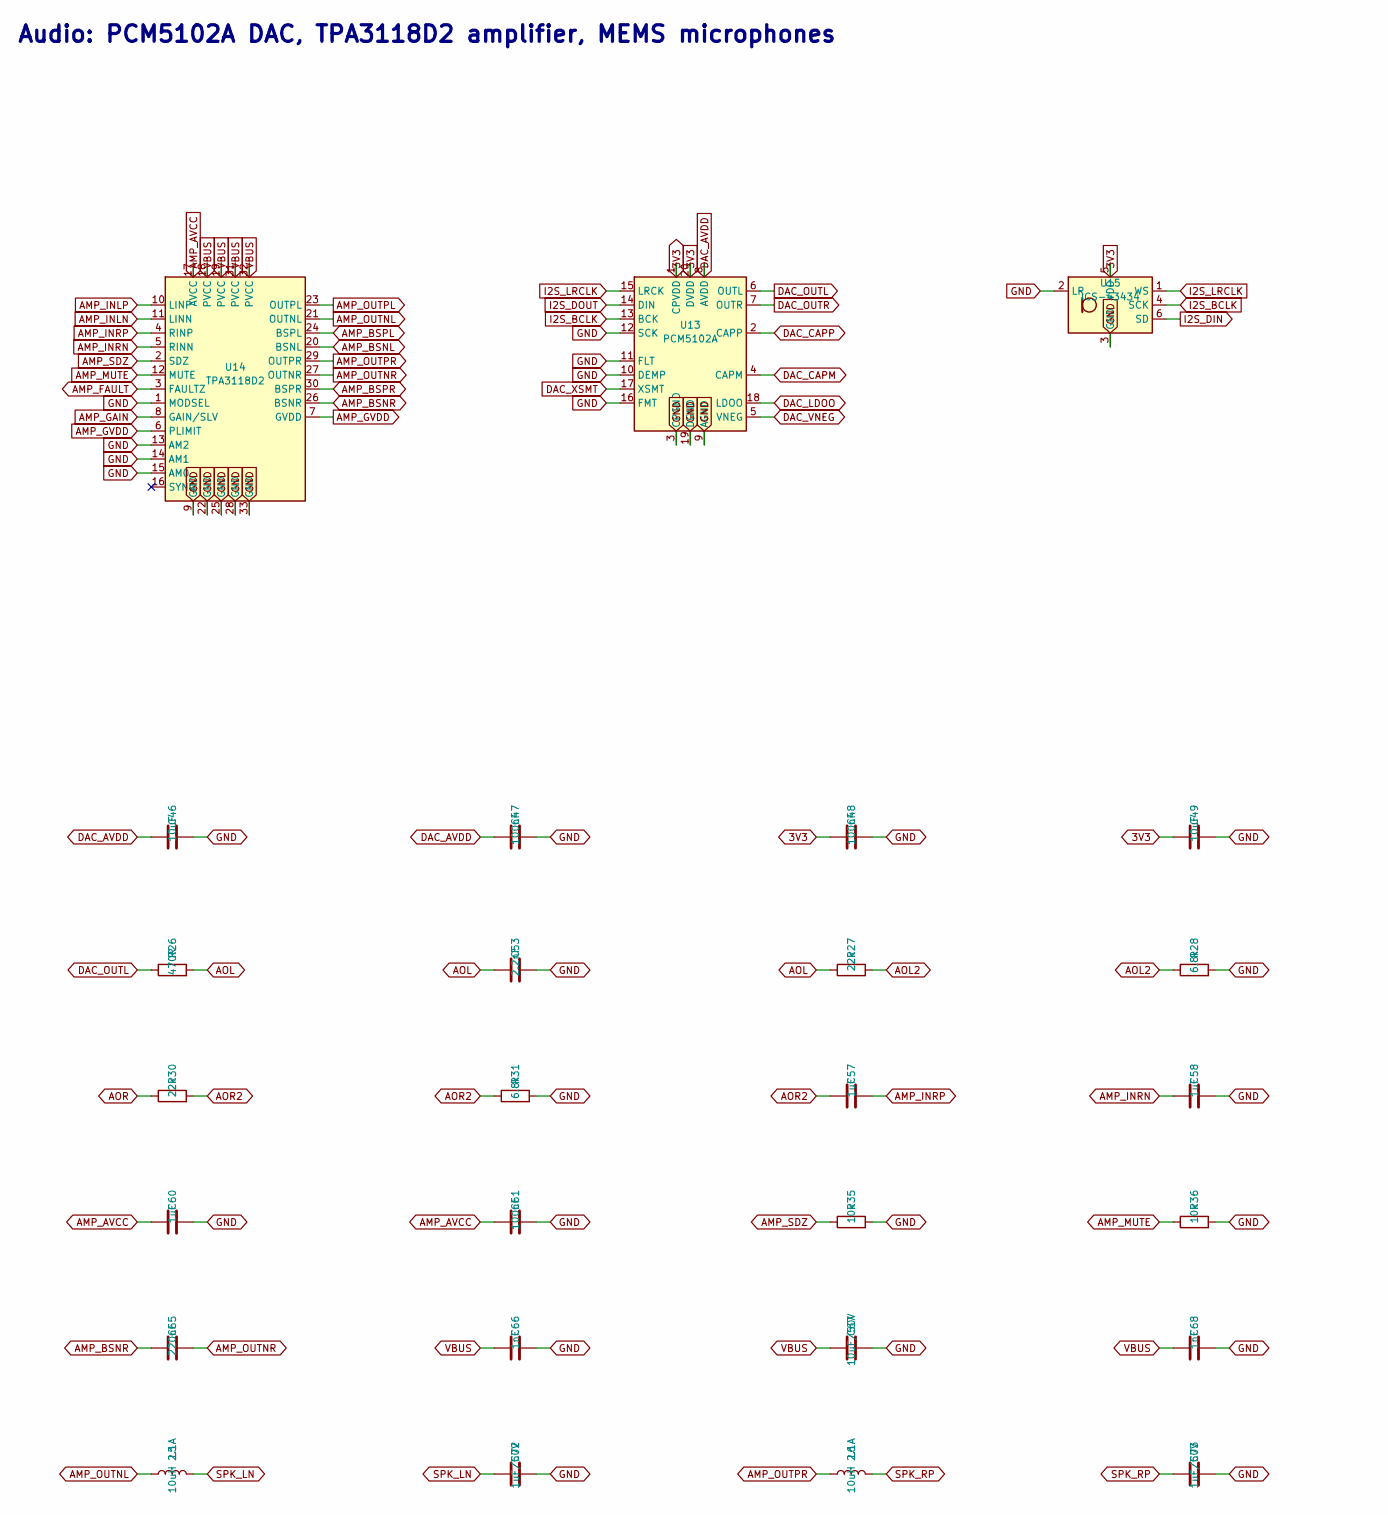
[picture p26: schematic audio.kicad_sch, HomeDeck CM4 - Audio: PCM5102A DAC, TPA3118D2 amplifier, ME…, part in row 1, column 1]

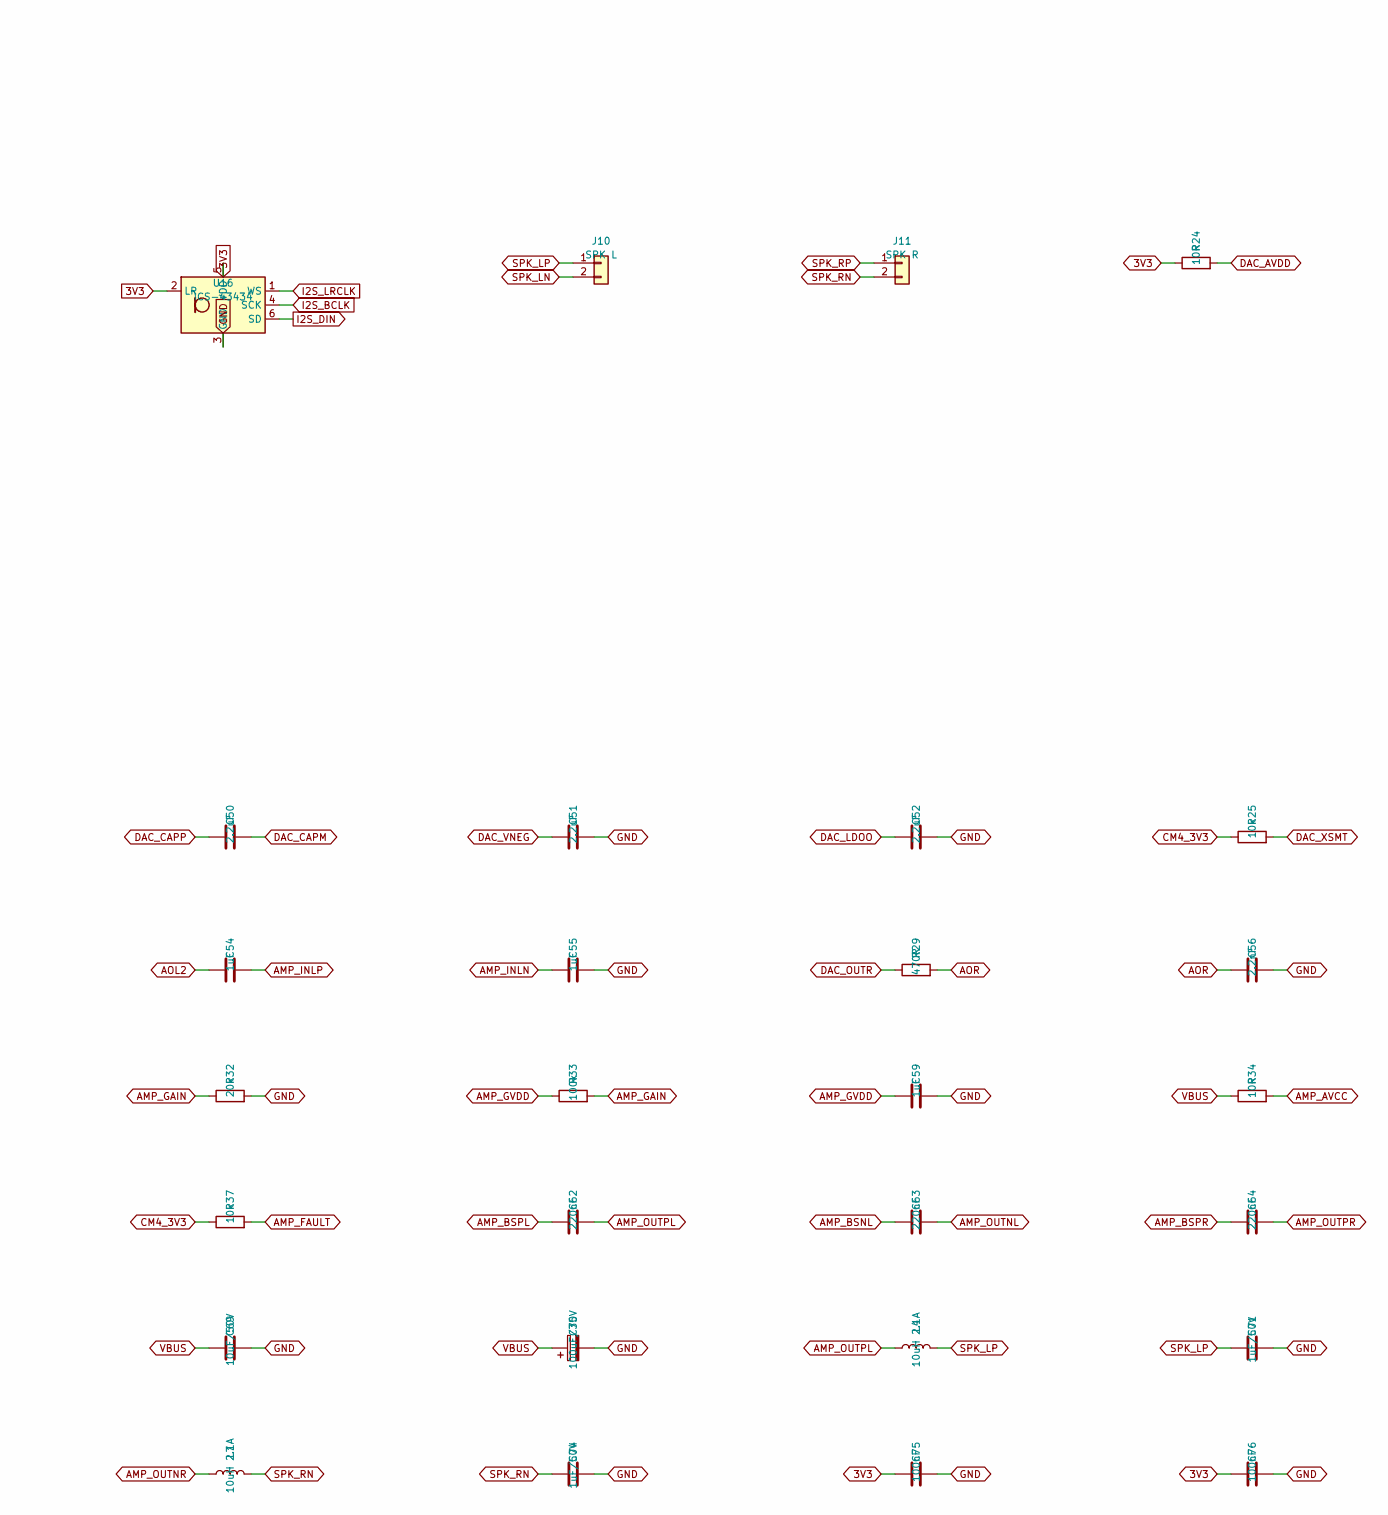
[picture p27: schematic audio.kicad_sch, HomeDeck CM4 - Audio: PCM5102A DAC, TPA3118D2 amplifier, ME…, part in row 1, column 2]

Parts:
C46, C49: 10uF; C_0603_1608Metric; LCSC C96446
C47, C48, C61, C75, C76: 100nF; C_0603_1608Metric; LCSC C14663
C50, C51, C52: 2.2uF; C_0603_1608Metric; LCSC C23630
C53, C56: 2.2nF; C_0603_1608Metric; LCSC C1604
C54, C55, C57, C58, C59, C60: 1uF; C_0603_1608Metric; LCSC C15849
C62, C63, C64, C65: 220nF; C_0603_1608Metric; LCSC C21120
C66, C68: 1nF; C_0603_1608Metric; LCSC C1588
C67, C69: 10uF/50V; C_1206_3216Metric; LCSC C13585
C70: 100uF/35V; CP_Elec_6.3x7.7; LCSC C3339
C71, C72, C73, C74: 1uF/50V; C_0805_2012Metric; LCSC C28323
J10: SPK L; JST_PH_S2B-PH-K_1x02_P2.00mm_Horizontal; MPN S2B-PH-K-S; LCSC C173752
J11: SPK R; JST_PH_S2B-PH-K_1x02_P2.00mm_Horizontal; MPN S2B-PH-K-S; LCSC C173752
L4, L5, L6, L7: 10uH 2.1A; L_Sunlord_SWPA5040S; MPN SWPA5040S100MT; LCSC C84608
R24, R34: 10R; R_0603_1608Metric; LCSC C22859
R25, R35, R36, R37: 10k; R_0603_1608Metric; LCSC C25804
R26, R29: 470R; R_0603_1608Metric; LCSC C23179
R27, R30: 22k; R_0603_1608Metric; LCSC C31850
R28, R31: 6.8k; R_0603_1608Metric; LCSC C23212
R32: 20k; R_0603_1608Metric; LCSC C4184
R33: 100k; R_0603_1608Metric; LCSC C25803
U13: PCM5102A; TSSOP-20_4.4x6.5mm_P0.65mm; MPN PCM5102APWR; LCSC C107671
U14: TPA3118D2; HTSSOP-32-1EP_6.1x11mm_P0.65mm_EP5.2x11mm_Mask4.11x4.36mm_T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; MPN TPA3118D2DAPR; LCSC C46497
U15, U16: ICS-43434; InvenSense_ICS-43434-6_3.5x2.65mm; MPN ICS-43434; LCSC C5656610

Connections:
3V3: C48.1, C49.1, C75.1, C76.1, R24.1, U13.1 (CPVDD), U13.20 (DVDD), U15.5 (VDD), U16.2 (LR), U16.5 (VDD); also elsewhere on the board
AMP_AVCC: C60.1, C61.1, R34.2, U14.17 (AVCC)
AMP_BSNL: C63.1, U14.20 (BSNL)
AMP_BSNR: C65.1, U14.26 (BSNR)
AMP_BSPL: C62.1, U14.24 (BSPL)
AMP_BSPR: C64.1, U14.30 (BSPR)
AMP_FAULT: R37.2, U14.3 (FAULTZ); also elsewhere on the board
AMP_GAIN: R32.1, R33.2, U14.8 (GAIN/SLV)
AMP_GVDD: C59.1, R33.1, U14.6 (PLIMIT), U14.7 (GVDD)
AMP_INLN: C55.1, U14.11 (LINN)
AMP_INLP: C54.2, U14.10 (LINP)
AMP_INRN: C58.1, U14.5 (RINN)
AMP_INRP: C57.2, U14.4 (RINP)
AMP_MUTE: R36.1, U14.12 (MUTE); also elsewhere on the board
AMP_OUTNL: C63.2, L5.1, U14.21 (OUTNL)
AMP_OUTNR: C65.2, L7.1, U14.27 (OUTNR)
AMP_OUTPL: C62.2, L4.1, U14.23 (OUTPL)
AMP_OUTPR: C64.2, L6.1, U14.29 (OUTPR)
AMP_SDZ: R35.1, U14.2 (SDZ); also elsewhere on the board
AOL: C53.1, R26.2, R27.1
AOL2: C54.1, R27.2, R28.1
AOR: C56.1, R29.2, R30.1
AOR2: C57.1, R30.2, R31.1
CM4_3V3: R25.1, R37.1; also elsewhere on the board
DAC_AVDD: C46.1, C47.1, R24.2, U13.8 (AVDD)
DAC_CAPM: C50.2, U13.4 (CAPM)
DAC_CAPP: C50.1, U13.2 (CAPP)
DAC_LDOO: C52.1, U13.18 (LDOO)
DAC_OUTL: R26.1, U13.6 (OUTL)
DAC_OUTR: R29.1, U13.7 (OUTR)
DAC_VNEG: C51.1, U13.5 (VNEG)
DAC_XSMT: R25.2, U13.17 (XSMT); also elsewhere on the board
GND: C46.2, C47.2, C48.2, C49.2, C51.2, C52.2, C53.2, C55.2, C56.2, C58.2, C59.2, C60.2, C61.2, C66.2, C67.2, C68.2, C69.2, C70.2, C71.2, C72.2, C73.2, C74.2, C75.2, C76.2, R28.2, R31.2, R32.2, R35.2, R36.2, U13.3 (CPGND), U13.9 (AGND), U13.10 (DEMP), U13.11 (FLT), U13.12 (SCK), U13.16 (FMT), U13.19 (DGND), U14.1 (MODSEL), U14.9 (GND), U14.13 (AM2), U14.14 (AM1), U14.15 (AM0), U14.22 (GND), U14.25 (GND), U14.28 (GND), U14.33 (GND), U15.2 (LR), U15.3 (GND), U16.3 (GND); also elsewhere on the board
I2S_BCLK: U13.13 (BCK), U15.4 (SCK), U16.4 (SCK); also elsewhere on the board
I2S_DIN: U15.6 (SD), U16.6 (SD); also elsewhere on the board
I2S_DOUT: U13.14 (DIN); also elsewhere on the board
I2S_LRCLK: U13.15 (LRCK), U15.1 (WS), U16.1 (WS); also elsewhere on the board
SPK_LN: C72.1, J10.2, L5.2
SPK_LP: C71.1, J10.1, L4.2
SPK_RN: C74.1, J11.2, L7.2
SPK_RP: C73.1, J11.1, L6.2
VBUS: C66.1, C67.1, C68.1, C69.1, C70.1, R34.1, U14.18 (PVCC), U14.19 (PVCC), U14.31 (PVCC), U14.32 (PVCC); also elsewhere on the board

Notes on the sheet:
Audio: PCM5102A DAC, TPA3118D2 amplifier, MEMS microphones



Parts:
C77: 10uF; C_0603_1608Metric; LCSC C96446
C78, C79, C80: 100nF; C_0603_1608Metric; LCSC C14663
J12: I2C ext (light sensor); PinHeader_1x04_P2.54mm_Vertical; MPN B-2100S04P-A110; LCSC C124378
R38, R39: 4.7k; R_0603_1608Metric; LCSC C23162
U17: SCD40; Sensirion_SCD4x-1EP_10.1x10.1mm_P1.25mm_EP4.8x4.8mm; MPN SCD40-D-R2; LCSC C3659421
U18: BME688; Bosch_LGA-8_3x3mm_P0.8mm_ClockwisePinNumbering; MPN BME688; LCSC C3664478

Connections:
3V3: C77.1, C78.1, C79.1, C80.1, J12.1, U17.7 (VDD), U17.19 (VDD), U18.2 (CSB), U18.6 (VDDIO), U18.8 (VDD); also elsewhere on the board
CM4_3V3: R38.1, R39.1; also elsewhere on the board
GND: C77.2, C78.2, C79.2, C80.2, J12.2, U17.6 (GND), U17.20 (GND), U17.21 (GND), U18.1 (GND), U18.5 (SDO), U18.7 (GND); also elsewhere on the board
I2C6_SCL: J12.4, R39.2, U17.9 (SCL), U18.4 (SCK); also elsewhere on the board
I2C6_SDA: J12.3, R38.2, U17.10 (SDA), U18.3 (SDI); also elsewhere on the board

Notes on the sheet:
Sensors: SCD40 CO2, BME688, I2C header

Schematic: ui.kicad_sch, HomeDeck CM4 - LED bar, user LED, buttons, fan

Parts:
C81, C82, C83, C84, C85, C86, C87, C88, C89, C90, C91, C93, C94, C95: 100nF; C_0603_1608Metric; LCSC C14663
C92: 10uF; C_0603_1608Metric; LCSC C96446
D5: USER (green); LED_0805_2012Metric; MPN KT-0805G; LCSC C2297
D6: SS34; D_SMA; MPN SS34; LCSC C8678
D10, D11, D12, D13, D14, D15, D16, D17, D18, D19: WS2812B; LED_WS2812B_PLCC4_5.0x5.0mm_P3.2mm; MPN WS2812B-B/T; LCSC C2761795
J17: LED strip ext; JST_PH_S3B-PH-K_1x03_P2.00mm_Horizontal; MPN S3B-PH-K-S; LCSC C157929
J18, J19, J20: ext button; PinHeader_1x02_P2.54mm_Vertical; MPN B-2100S02P-A110; LCSC C124375
J21: FAN 5V; JST_PH_S2B-PH-K_1x02_P2.00mm_Horizontal; MPN S2B-PH-K-S; LCSC C173752
Q3: AO3400A; SOT-23; MPN AO3400A; LCSC C20917
R40: 330R; R_0603_1608Metric; LCSC C23138
R41: 470R; R_0603_1608Metric; LCSC C23179
R42, R43, R44: 10k; R_0603_1608Metric; LCSC C25804
R45: 100R; R_0603_1608Metric; LCSC C22775
R46: 100k; R_0603_1608Metric; LCSC C25803
SW1: POWER; SW_Push_1P1T_XKB_TS-1187A; MPN TS-1187A-B-A-B; LCSC C318884
SW2: BTN A; SW_Push_1P1T_XKB_TS-1187A; MPN TS-1187A-B-A-B; LCSC C318884
SW3: BTN B; SW_Push_1P1T_XKB_TS-1187A; MPN TS-1187A-B-A-B; LCSC C318884
U19: 74AHCT1G125; SOT-23-5; MPN SN74AHCT1G125DBVR; LCSC C7484

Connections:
5V_PERIPH: C81.1, C82.1, C83.1, C84.1, C85.1, C86.1, C87.1, C88.1, C89.1, C90.1, C91.1, C92.1, D6.1 (K), D10.1 (VDD), D11.1 (VDD), D12.1 (VDD), D13.1 (VDD), D14.1 (VDD), D15.1 (VDD), D16.1 (VDD), D17.1 (VDD), D18.1 (VDD), D19.1 (VDD), J17.1, J21.1, U19.5 (VCC); also elsewhere on the board
BTN_A: C94.1, J19.1, R43.2, SW2.1; also elsewhere on the board
BTN_B: C95.1, J20.1, R44.2, SW3.1; also elsewhere on the board
CM4_3V3: R42.1, R43.1, R44.1; also elsewhere on the board
FAN_G: Q3.1 (G), R45.2, R46.1
FAN_N: D6.2 (A), J21.2, Q3.3 (D)
FAN_PWM: R45.1; also elsewhere on the board
GND: C81.2, C82.2, C83.2, C84.2, C85.2, C86.2, C87.2, C88.2, C89.2, C90.2, C91.2, C92.2, C93.2, C94.2, C95.2, D5.1 (K), D10.3 (VSS), D11.3 (VSS), D12.3 (VSS), D13.3 (VSS), D14.3 (VSS), D15.3 (VSS), D16.3 (VSS), D17.3 (VSS), D18.3 (VSS), D19.3 (VSS), J17.3, J18.2, J19.2, J20.2, Q3.2 (S), R46.2, SW1.2, SW2.2, SW3.2, U19.1, U19.3 (GND); also elsewhere on the board
LED_D0: D10.4 (DIN), R40.2
LED_D1: D10.2 (DOUT), D11.4 (DIN)
LED_D2: D11.2 (DOUT), D12.4 (DIN)
LED_D3: D12.2 (DOUT), D13.4 (DIN)
LED_D4: D13.2 (DOUT), D14.4 (DIN)
LED_D5: D14.2 (DOUT), D15.4 (DIN)
LED_D6: D15.2 (DOUT), D16.4 (DIN)
LED_D7: D16.2 (DOUT), D17.4 (DIN)
LED_D8: D17.2 (DOUT), D18.4 (DIN)
LED_D9: D18.2 (DOUT), D19.4 (DIN)
LED_D10: D19.2 (DOUT), J17.2
LED_DATA: U19.2; also elsewhere on the board
LED_DATA_5V: R40.1, U19.4
PWR_BTN: C93.1, J18.1, R42.2, SW1.1; also elsewhere on the board
USER_LED: R41.1; also elsewhere on the board
USER_LED_A: D5.2 (A), R41.2

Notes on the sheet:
LED bar, user LED, buttons, fan

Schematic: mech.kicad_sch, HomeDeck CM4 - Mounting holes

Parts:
H1, H2, H3, H4: M2.5 display standoff; MountingHole_2.7mm_M2.5

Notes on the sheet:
Mounting holes



Board: 4 copper layers, 130.0 x 105.0 mm, 228 parts (117 on the bottom side), 161 nets.

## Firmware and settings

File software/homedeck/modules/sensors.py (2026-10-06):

"""Room sensors: SCD40 (CO2/T/RH) and BME688 (T/P/RH/gas) on I2C6, with air-quality context and nudges.

state()["metrics"] is a list of {key,label,unit,value,lo,hi,zones,status,hint,history} tiles the app renders.
Emits: "co2_high" {value} when CO2 crosses the nudge threshold upward (hysteresis 100 ppm, once per hour max),
       "co2_ok" when it recovers, "humidity_low"/"humidity_high" similarly (once per 6 h).
"""
import json, os, re, threading, time

NAME = "sensors"
DEFAULTS = {
    "i2c_bus": 6,
    "nudges": {"enabled": True, "co2_threshold": 1000, "humidity_low": 30, "humidity_high": 65, "spoken": False},
    "history_every_s": 30, "history_len": 240,
    "temp_source": "scd40",      # scd40 sits further from the CM4 than the bme688 and reads closer to the room
    "temp_offset_c": 0.0,        # calibration against a real thermometer (Settings)
    "log_every_s": 60, "log_keep_days": 30,     # long-term history on disk (air_history.jsonl) for the chart and the report
    "report_enabled": True, "report_time": "21:30",   # pushed "air today" summary (notification + on-screen)
    "report_spoken": False,                           # say it out loud too (off: it interrupts the evening)
}
SCD40, BME688 = 0x62, 0x76

_state = {"scd40": {}, "bme688": {}, "external": {}, "metrics": [], "nudge": None}
_hist = {"co2": [], "temp": [], "hum": [], "voc": [], "press": []}
_lock = threading.Lock()
ctx = None

# ----------------------------------------------------------------- context zones
def _z(key, label, unit, v, lo, hi, zones, hint):
    m = dict(key=key, label=label, unit=unit, value=v, lo=lo, hi=hi, zones=zones, hint=hint,
             status={"level": "unknown", "text": "no data"})
    if v is not None:
        for a, b, level, text in zones:
            if a <= v < b or (v >= b and b == hi) or (v < a and a == lo):
                m["status"] = {"level": level, "text": text}; break
    m["history"] = [round(x, 1) for _, x in _hist[key]]
    return m

def _room_temp(s, b):
    """Room temperature: preferred source plus the user's calibration offset."""
    cfg = ctx.config if ctx else {}
    src = cfg.get("temp_source", "scd40")
    ext = _state.get("external") or {}
    if ext.get("temp_c") is not None and src != "bme688":
        t = ext["temp_c"]                       # an external sensor away from the board always wins
    else:
        t = (s.get("temp_c") if src == "scd40" else b.get("temp_c"))
    if t is None:
        t = b.get("temp_c", s.get("temp_c"))
    return None if t is None else round(t + float(cfg.get("temp_offset_c", 0.0)), 1)


def _metrics():
    s, b = _state["scd40"], _state["bme688"]
    return [
        _z("co2", "CO₂", "ppm", s.get("co2_ppm"), 400, 2500,
           [(400, 800, "good", "Good"), (800, 1000, "warning", "Acceptable"), (1000, 1500, "serious", "Poor, ventilate"), (1500, 2500, "critical", "Bad")],
           "Outdoor air is about 420 ppm. Under 800 feels fresh; above 1000 people get drowsy and lose focus."),
        _z("temp", "Temperature", "°C", _room_temp(s, b), 10, 34,
           [(10, 18, "serious", "Cold"), (18, 20, "warning", "Cool"), (20, 24, "good", "Comfortable"), (24, 26, "warning", "Warm"), (26, 34, "serious", "Hot")],
           "Comfort range 20 to 24 °C. This sensor sits near the CM4 and can read a degree or two high."),
        _z("hum", "Humidity", "%", (_state.get("external") or {}).get("humidity_pct", b.get("humidity_pct", s.get("humidity_pct"))), 0, 100,
           [(0, 30, "serious", "Dry"), (30, 40, "warning", "Slightly dry"), (40, 60, "good", "Ideal"), (60, 70, "warning", "Humid"), (70, 100, "serious", "Very humid")],
           "40 to 60 % is ideal. Below 30 % dries eyes and skin; above 60 % mould and dust mites thrive."),
        _z("voc", "VOC level", "", b.get("voc_index"), 0, 100,
           [(0, 25, "good", "Clean"), (25, 50, "warning", "Some VOCs"), (50, 75, "serious", "Elevated"), (75, 100, "critical", "High")],
           "Relative reading from the BME688 gas sensor: 0 is the cleanest air it has seen since boot. Needs about 20 minutes of warm-up."),
        _z("press", "Pressure", "hPa", b.get("pressure_hpa"), 950, 1060,
           [(950, 980, "warning", "Low, stormy"), (980, 1040, "good", "Normal"), (1040, 1060, "warning", "High")],
           "Sea-level normal is about 1013 hPa. A fast drop usually means weather is on the way."),
    ]

def _push(key, v):
    if v is None: return
    h = _hist[key]; now = time.time()
    if not h or now - h[-1][0] >= ctx.config["history_every_s"]:
        h.append((now, v)); del h[:-ctx.config["history_len"]]

# ----------------------------------------------------------------- SCD40
def _crc8(data):
    crc = 0xFF
    for b in data:
        crc ^= b
        for _ in range(8):
            crc = ((crc << 1) ^ 0x31) & 0xFF if crc & 0x80 else (crc << 1) & 0xFF
    return crc

def _scd(bus, cmd, nread=0):
    from smbus2 import i2c_msg
    bus.i2c_rdwr(i2c_msg.write(SCD40, [cmd >> 8, cmd & 0xFF]))
    if not nread: return None
    time.sleep(0.001)
    r = i2c_msg.read(SCD40, nread); bus.i2c_rdwr(r)
    raw = list(r); out = []
    for i in range(0, len(raw), 3):
        if _crc8(raw[i:i + 2]) != raw[i + 2]: raise ValueError("SCD40 CRC")
        out.append((raw[i] << 8) | raw[i + 1])
    return out

# ----------------------------------------------------------------- BME688
def _s8(v): return v - 256 if v > 127 else v
def _s16(lo, hi):
    v = (hi << 8) | lo
    return v - 65536 if v > 32767 else v
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

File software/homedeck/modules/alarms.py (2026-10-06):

"""Alarms with LED sunrise, light-retry ("keep ringing until the light is on") and a morning routine.

Alarm record (config["alarms"]):
  {id, time "07:00", days [0-6, Mon=0] ([] = one-off), enabled, label, sound "default"|"spotify:..."|path,
   sunrise_min 20, light_retry {enabled, lux_threshold, retry_after_min, max_retries}, routine true}
Events: "alarm_ringing" {id,label}, "alarm_stopped" {id}, "routine" {text}
"""
import datetime as dt, os, subprocess, threading, time, uuid, wave

NAME = "alarms"
DEFAULTS = {
    "alarms": [],
    "routine": {"enabled": True, "spoken": True},
    "auto_dismiss_min": 10,          # stop ringing on its own after this long (retries still apply)
}

ctx = None
_lock = threading.Lock()
_s = {"ringing": False, "ringing_id": None, "snoozed_until": None, "retries": 0, "routine_last": None,
      "next_alarm": None, "fired": {}, "light_pending": None}
_player = None            # subprocess playing the sound
_stop_flag = threading.Event()


# ------------------------------------------------------------------ sound
def _default_wav():
    """Rising two-tone beep loop, 8 s, generated once with numpy."""
    p = os.path.join(ctx.data_dir, "sounds", "alarm.wav")
    if os.path.isfile(p):
        return p
    os.makedirs(os.path.dirname(p), exist_ok=True)
    try:
        import numpy as np
        sr = 22050
        t = np.arange(sr * 8) / sr
        beat = 0.5                                        # seconds per beep
        idx = (t // beat).astype(int)
        freq = np.where(idx % 2 == 0, 880.0, 1174.7)      # A5 / D6 alternating
        rise = 1.0 + 0.5 * (t / 8.0)                      # pitch rises over the loop
        env = (t % beat) < 0.32                           # beep then gap
        sig = 0.35 * np.sin(2 * np.pi * freq * rise * t) * env
        fade = np.minimum(1.0, (t % beat) / 0.02)         # click-free attack
        pcm = (sig * fade * 32767).astype("<i2")
        with wave.open(p, "wb") as w:
            w.setnchannels(1); w.setsampwidth(2); w.setframerate(sr); w.writeframes(pcm.tobytes())
    except Exception as e:
        ctx.log(f"could not generate alarm.wav: {e}")
    return p


def _play(sound, label="Alarm"):
    """Start the alarm sound until _stop_sound(): a Spotify URI plays music, anything else rings the chosen tone."""
    global _player
    _stop_sound()
    _stop_flag.clear()
    if isinstance(sound, str) and sound.startswith("spotify:"):
        sp = ctx.module("spotify")
        if sp and hasattr(sp, "play_uri"):
            try:
                sp.play_uri(sound)
                _s["spotify_alarm"] = True
                return
            except Exception as e:
                ctx.log(f"spotify alarm failed, using tone: {e}")
    _s["spotify_alarm"] = False
    r = ctx.module("ringer")
    if r and hasattr(r, "ring"):
        try:
            line = f"{label}. It's {time.strftime('%-I:%M %p').lower()}." if (r.say_label() and label) else None
            r.ring("alarm", label, line)
            return
        except Exception as e:
            ctx.log(f"ringer failed, using the old tone: {e}")
    path = _default_wav() if sound in (None, "", "default") or not os.path.isfile(str(sound)) else sound

    def loop():
        global _player
        while not _stop_flag.is_set():
            try:
                _player = subprocess.Popen(["aplay", "-q", "-D", "default", path], stdout=subprocess.DEVNULL, stderr=subprocess.DEVNULL)
                _player.wait()
            except Exception as e:
                ctx.log(f"aplay failed: {e}")
                _stop_flag.wait(5)
    threading.Thread(target=loop, daemon=True).start()


def _stop_sound():
    global _player
    _stop_flag.set()
    if _player and _player.poll() is None:
        try:
            _player.terminate()
        except Exception:
            pass
    _player = None
    r = ctx.module("ringer")
    if r and hasattr(r, "stop"):
        try:
            if r.state().get("kind") == "alarm":
                r.stop()
        except Exception:
            pass
    if _s.get("spotify_alarm"):                       # only a music alarm pauses Spotify; a tone alarm leaves music alone
        _s["spotify_alarm"] = False
        sp = ctx.module("spotify")
        if sp and hasattr(sp, "pause"):
            try:
                sp.pause()
            except Exception:
                pass


# ------------------------------------------------------------------ helpers
def _lux():
    d = ctx.module("display")
    try:
        v = d.state().get("lux") if d else None
        return float(v) if v is not None else None
    except Exception:
        return None


def _next_fire(a, now=None):
    """Next datetime this alarm should ring, or None."""
    now = now or dt.datetime.now()
    try:
        h, m = [int(x) for x in a.get("time", "07:00").split(":")]
    except Exception:
        return None
    days = a.get("days") or []
    for d in range(0, 8):
        cand = (now + dt.timedelta(days=d)).replace(hour=h, minute=m, second=0, microsecond=0)
        if cand <= now:
            continue
        if not days or cand.weekday() in days:
            return cand
    return None


def _leds(name, **kw):
    l = ctx.module("leds")
    if l and hasattr(l, "pattern"):
        try:
            l.pattern(name, **kw)
        except Exception:
            pass


def _say(text):
    v = ctx.module("voice")
    if v and hasattr(v, "say"):
        try:
            v.say(text)
        except Exception as e:
            ctx.log(f"say failed: {e}")


def _ring(a, retry=False):
    with _lock:
        _s["ringing"] = True
        _s["ringing_id"] = a["id"]
        _s["snoozed_until"] = None
        _s["ring_started"] = time.time()
    _play(a.get("sound", "default"), a.get("label") or "Alarm")
    _leds("alert")
    ctx.emit("alarm_ringing", {"id": a["id"], "label": a.get("label", "Alarm"), "retry": retry})
    ctx.log(f"alarm ringing: {a.get('label', a['id'])}{' (light retry)' if retry else ''}")


def _stop_ring(reason):
    with _lock:
        aid = _s["ringing_id"]
        _s["ringing"] = False
        _s["ringing_id"] = None
    _stop_sound()
    _leds("off")
    ctx.emit("alarm_stopped", {"id": aid, "reason": reason})


def _arm_light_retry(a):
    lr = a.get("light_retry") or {}
    if not lr.get("enabled", True):
        return
    with _lock:
        _s["light_pending"] = {"id": a["id"], "at": time.time() + 60 * lr.get("retry_after_min", 3),
                               "threshold": lr.get("lux_threshold", 30), "max": lr.get("max_retries", 5)}
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
